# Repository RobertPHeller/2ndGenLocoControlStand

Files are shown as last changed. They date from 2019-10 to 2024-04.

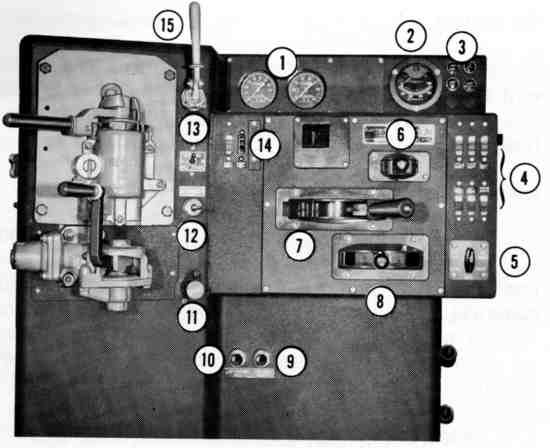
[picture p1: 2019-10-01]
docs/sd40-2-4.jpg

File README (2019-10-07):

This is a model diesel locomotive control stand (more or less typical of a 2nd 
generation diesel locomotive).

Files / Directories:

2ndGenLocoControlStand.dxf, 2ndGenLocoControlStand.gcad, and 
2ndGenLocoControlStand.tcl relate to the 3D model of the front panel (based on 
a Hammond Manucafturing RL6685 enclosure).

The ESP32ControlStand directory contains the ESP32 (TTGO-T1) based design, the 
electronics are in KiCad form (Version: 2013.06.11).  The 
ESP32ControlStand/ESP32ControlStand_Node directory contains the OpenMRN code 
(C++, Arduino style using the OpenMRNLite library).

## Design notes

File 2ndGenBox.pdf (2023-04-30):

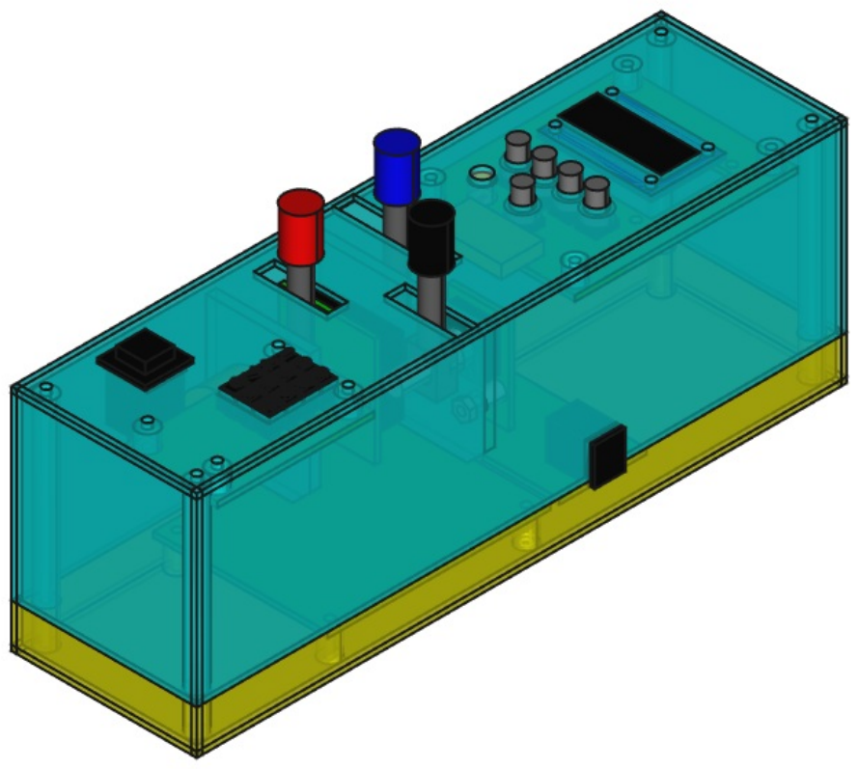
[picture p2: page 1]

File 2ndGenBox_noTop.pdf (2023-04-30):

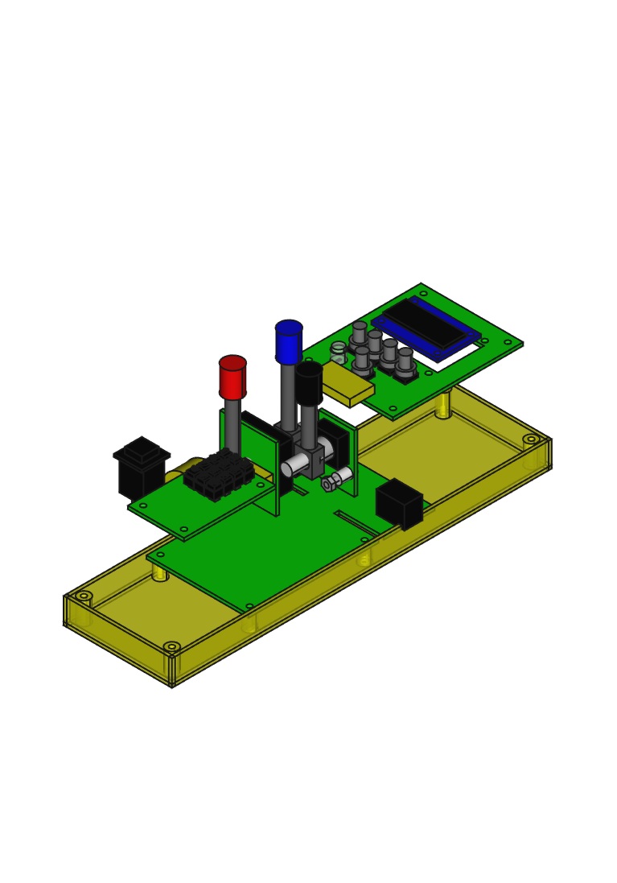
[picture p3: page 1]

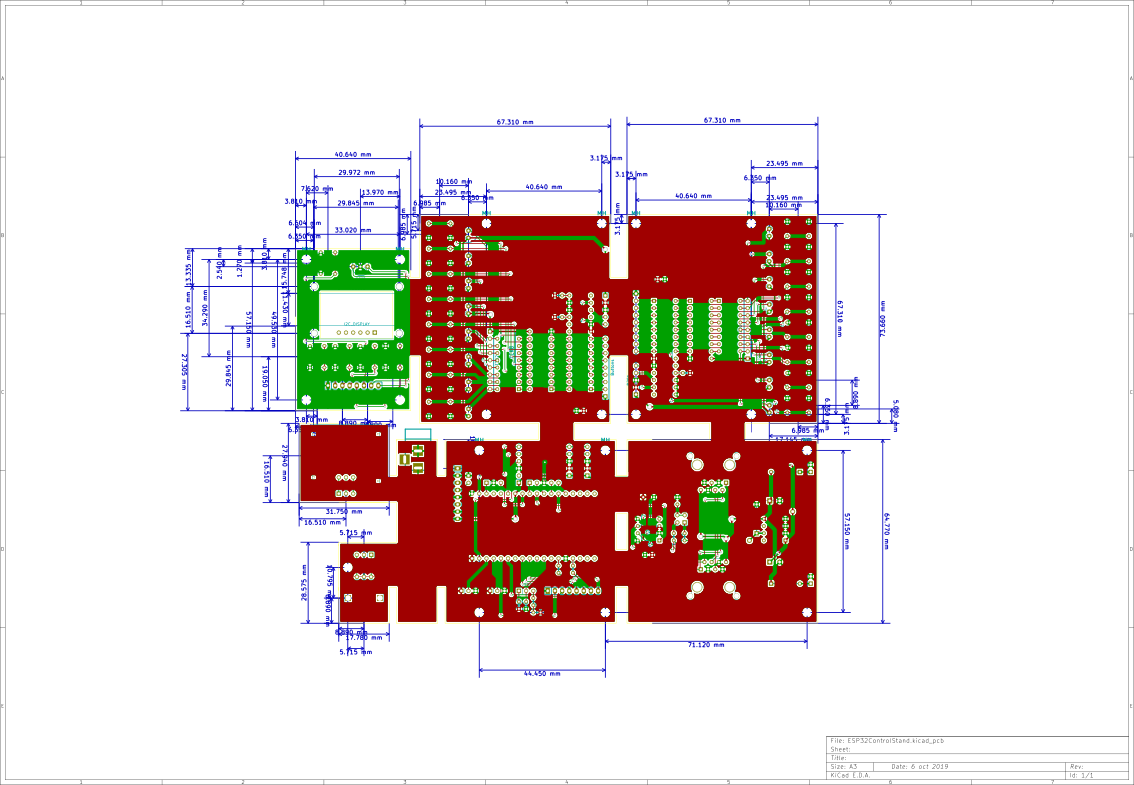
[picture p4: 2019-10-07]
ESP32ControlStand/ESP32ControlStand.png

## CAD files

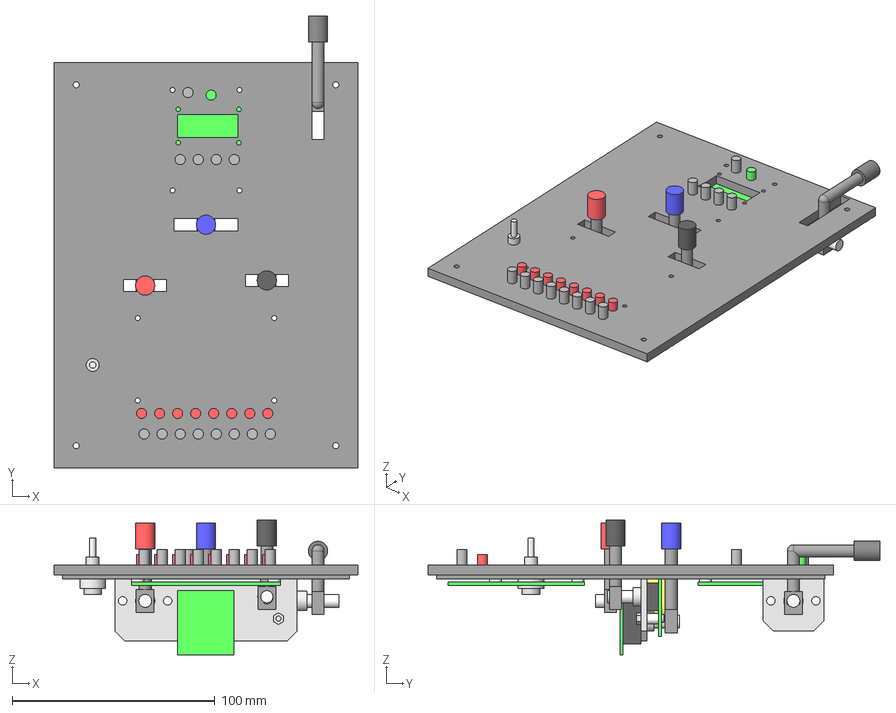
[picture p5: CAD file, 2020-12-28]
2ndGenLocoControlStand.fcstd
149.9 x 222.9 x 66.5 mm
ControlStandLid_lid
ControlStandLid_throttleReverserBrakeBracket
ControlStandLid_throttle_body
ControlStandLid_throttle_bushing
ControlStandLid_throttle_shaft
ControlStandLid_throttle_noturn
ControlStandLid_throttle_circuitBoard
ControlStandLid_throttleLever_shaft
ControlStandLid_throttleLever_handle
ControlStandLid_reverser_body
ControlStandLid_reverser_bushing
ControlStandLid_reverser_shaft
ControlStandLid_reverser_circuitBoard
ControlStandLid_reverser_noturnStandoff
ControlStandLid_reverser_noturnScrew
ControlStandLid_reverser_ntNut
ControlStandLid_reverserLever_shaft
ControlStandLid_reverserLever_handle
ControlStandLid_brakePot_body
ControlStandLid_brakePot_bushing
ControlStandLid_brakePot_shaft
ControlStandLid_brakePot_tab1
ControlStandLid_brakePot_tab2
ControlStandLid_brakeLever_shaft
ControlStandLid_brakeLever_handle
ControlStandLid_buttonDisplayBoard_board
ControlStandLid_buttonDisplayBoardSandoff1
ControlStandLid_buttonDisplayBoardSandoff2
ControlStandLid_buttonDisplayBoardSandoff3
ControlStandLid_buttonDisplayBoardSandoff4
ControlStandLid_hornBracket
ControlStandLid_hornPot_body
ControlStandLid_hornPot_bushing
ControlStandLid_hornPot_shaft
ControlStandLid_hornPot_tab1
ControlStandLid_hornPot_tab2
ControlStandLid_hornHandle_shaft
ControlStandLid_hornHandle_handle
ControlStandLid_buttonLEDBoard_board
ControlStandLid_buttonLEDBoardStandoff1
ControlStandLid_buttonLEDBoardStandoff2
ControlStandLid_buttonLEDBoardStandoff3
ControlStandLid_buttonLEDBoardStandoff4
ControlStandLid_lightSwitch_body
ControlStandLid_lightSwitch_terminals
ControlStandLid_lightSwitch_bushing
ControlStandLid_lightSwitch_shaft
ControlStandLid_statusLED_led
ControlStandLid_buttonLEDBoardLEDS1_led
ControlStandLid_buttonLEDBoardLEDS2_led
ControlStandLid_buttonLEDBoardLEDS3_led
ControlStandLid_buttonLEDBoardLEDS4_led
ControlStandLid_buttonLEDBoardLEDS5_led
ControlStandLid_buttonLEDBoardLEDS6_led
ControlStandLid_buttonLEDBoardLEDS7_led
ControlStandLid_buttonLEDBoardLEDS8_led
ControlStandLid_buttonDisplayBoardPlungers1_body
ControlStandLid_buttonDisplayBoardPlungers2_body
ControlStandLid_buttonDisplayBoardPlungers3_body
ControlStandLid_buttonDisplayBoardPlungers4_body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

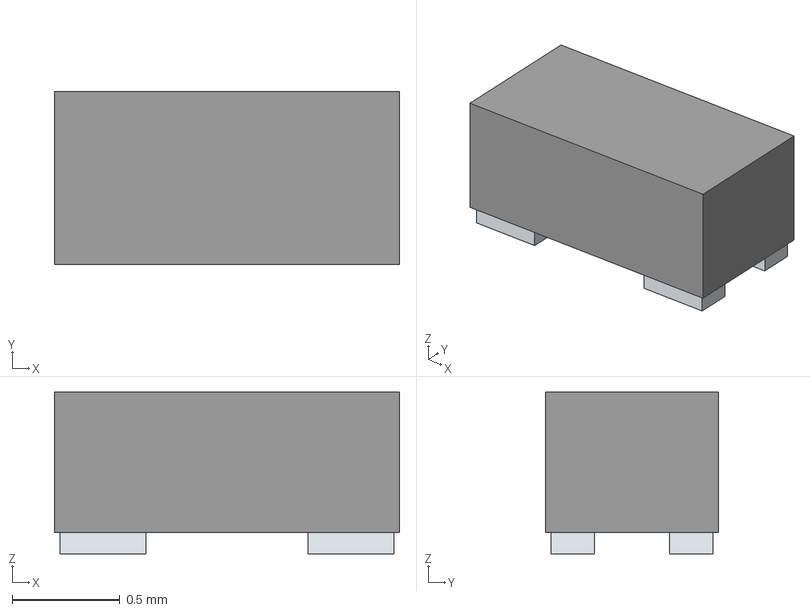
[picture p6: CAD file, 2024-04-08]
ESP32-S3-WROOM-ControlStand/3dmodels/APHB1608CGKSURKC.stp
1.60 x 0.8 x 0.75 mm
Pins

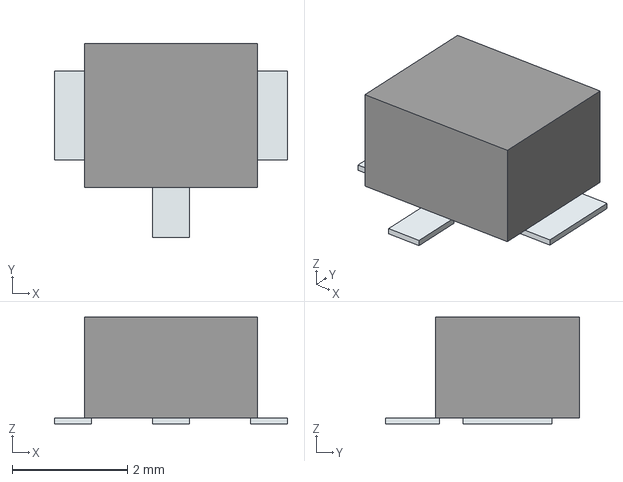
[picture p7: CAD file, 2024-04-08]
ESP32-S3-WROOM-ControlStand/3dmodels/B3U-1100P-B.stp
4.04 x 3.37 x 1.85 mm
Pins

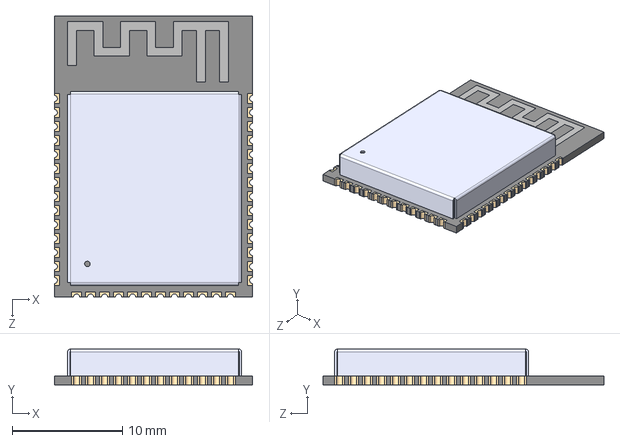
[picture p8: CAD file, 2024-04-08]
ESP32-S3-WROOM-ControlStand/3dmodels/ESP32-S3-WROOM-1-N4.stp
18.0 x 3.25 x 25.5 mm

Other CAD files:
2ndGenLocoControlStand.dxf

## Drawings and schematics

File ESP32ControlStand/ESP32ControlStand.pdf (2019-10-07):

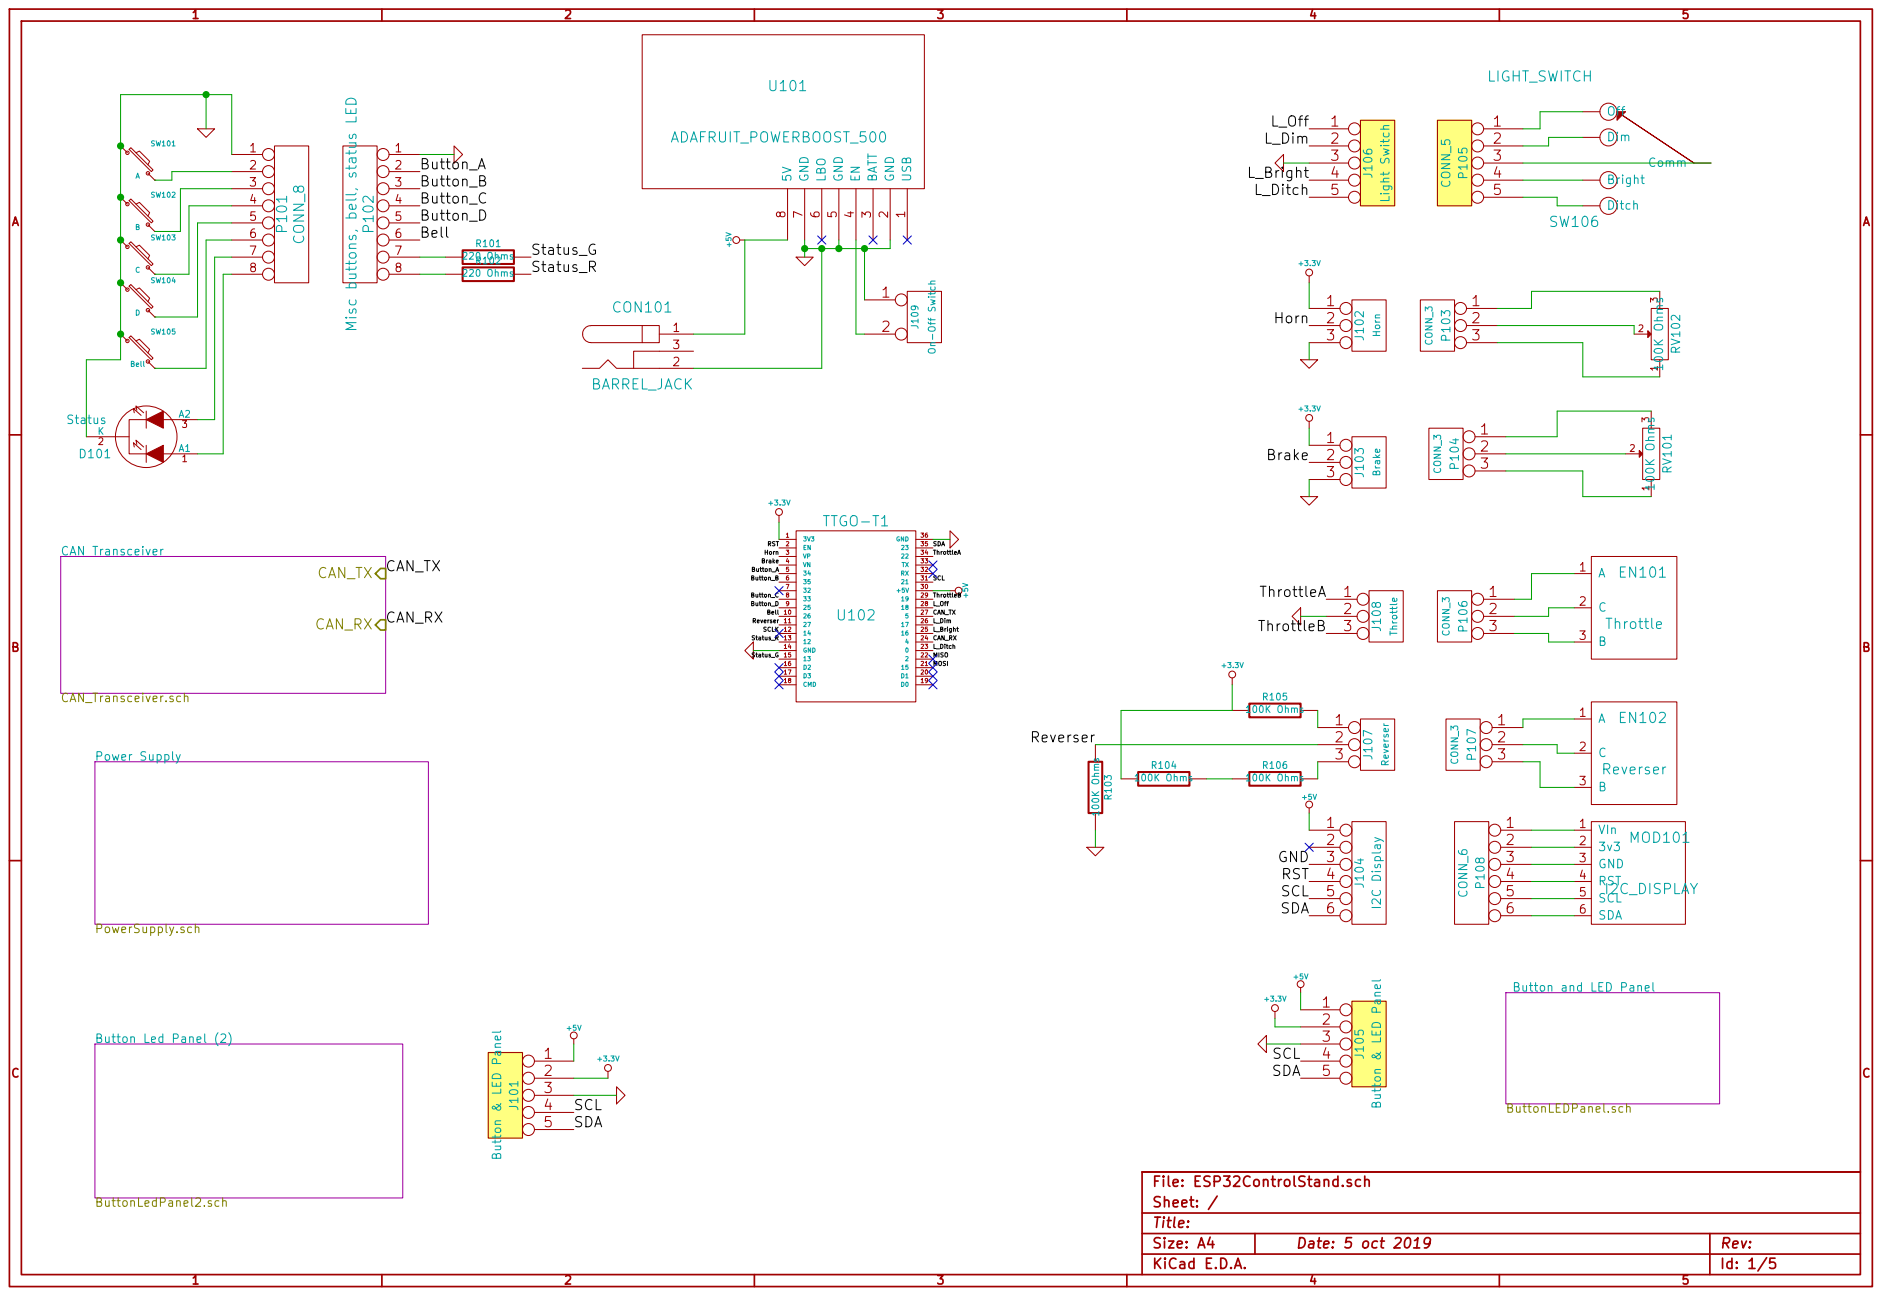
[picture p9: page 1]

220 Ohms Button Led Panel (2) ButtonLedPanel2.sch

+3.3V USB 1 GND 2 BATT 3 EN 4 GND 5 LBO 6 GND 7 5V 8 U101 ADAFRUIT_POWERBOOST_500 +5V
Status_G 123 CON101

SCL MISO MOSI SCLK CAN_TX

Id: 1/5 Title: File: ESP32ControlStand.sch

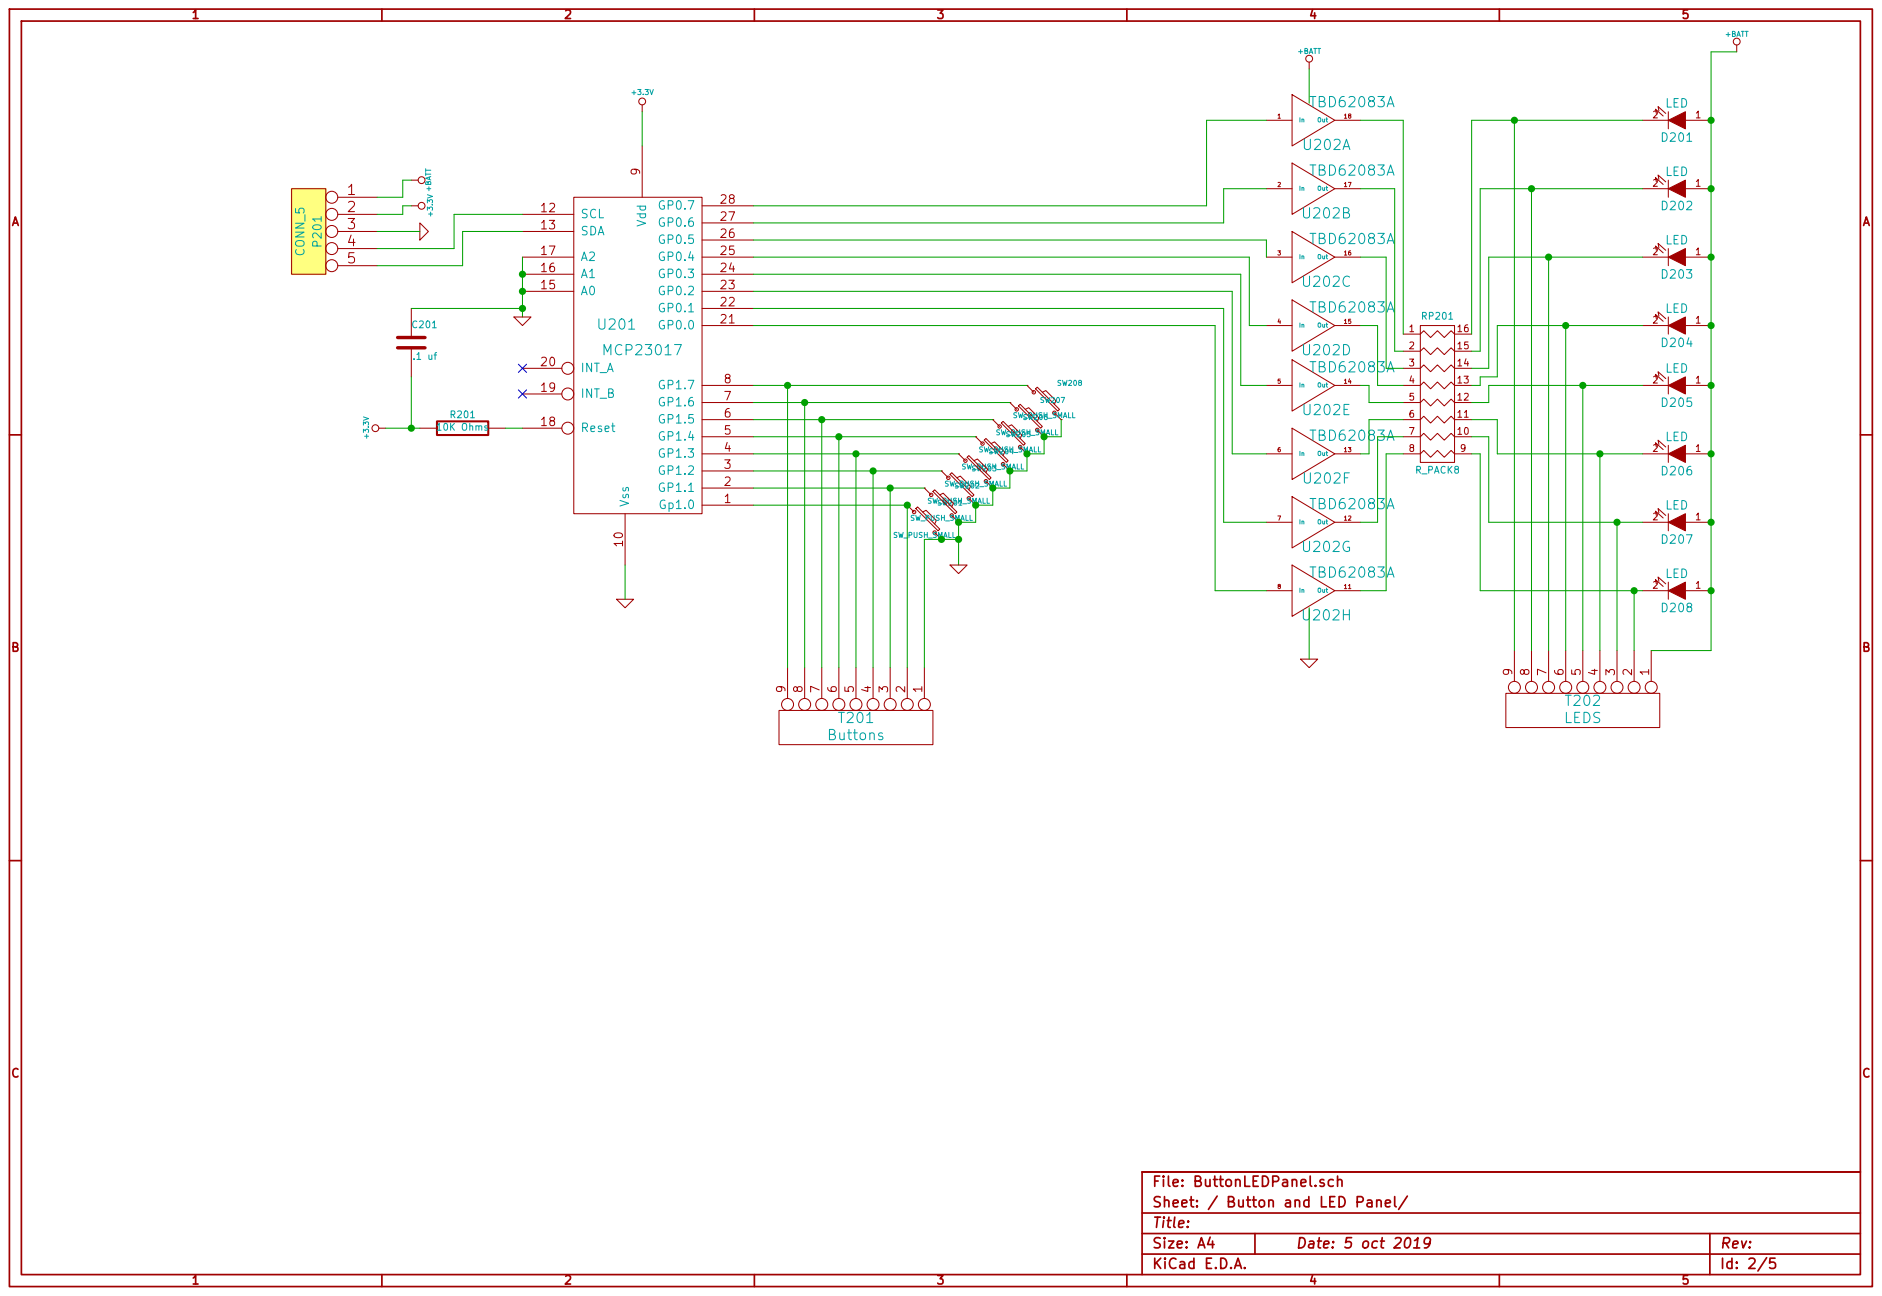
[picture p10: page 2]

7 | 10

Id: 2/5 Title: File: ButtonLEDPanel.sch Sheet: / Button and LED Panel/

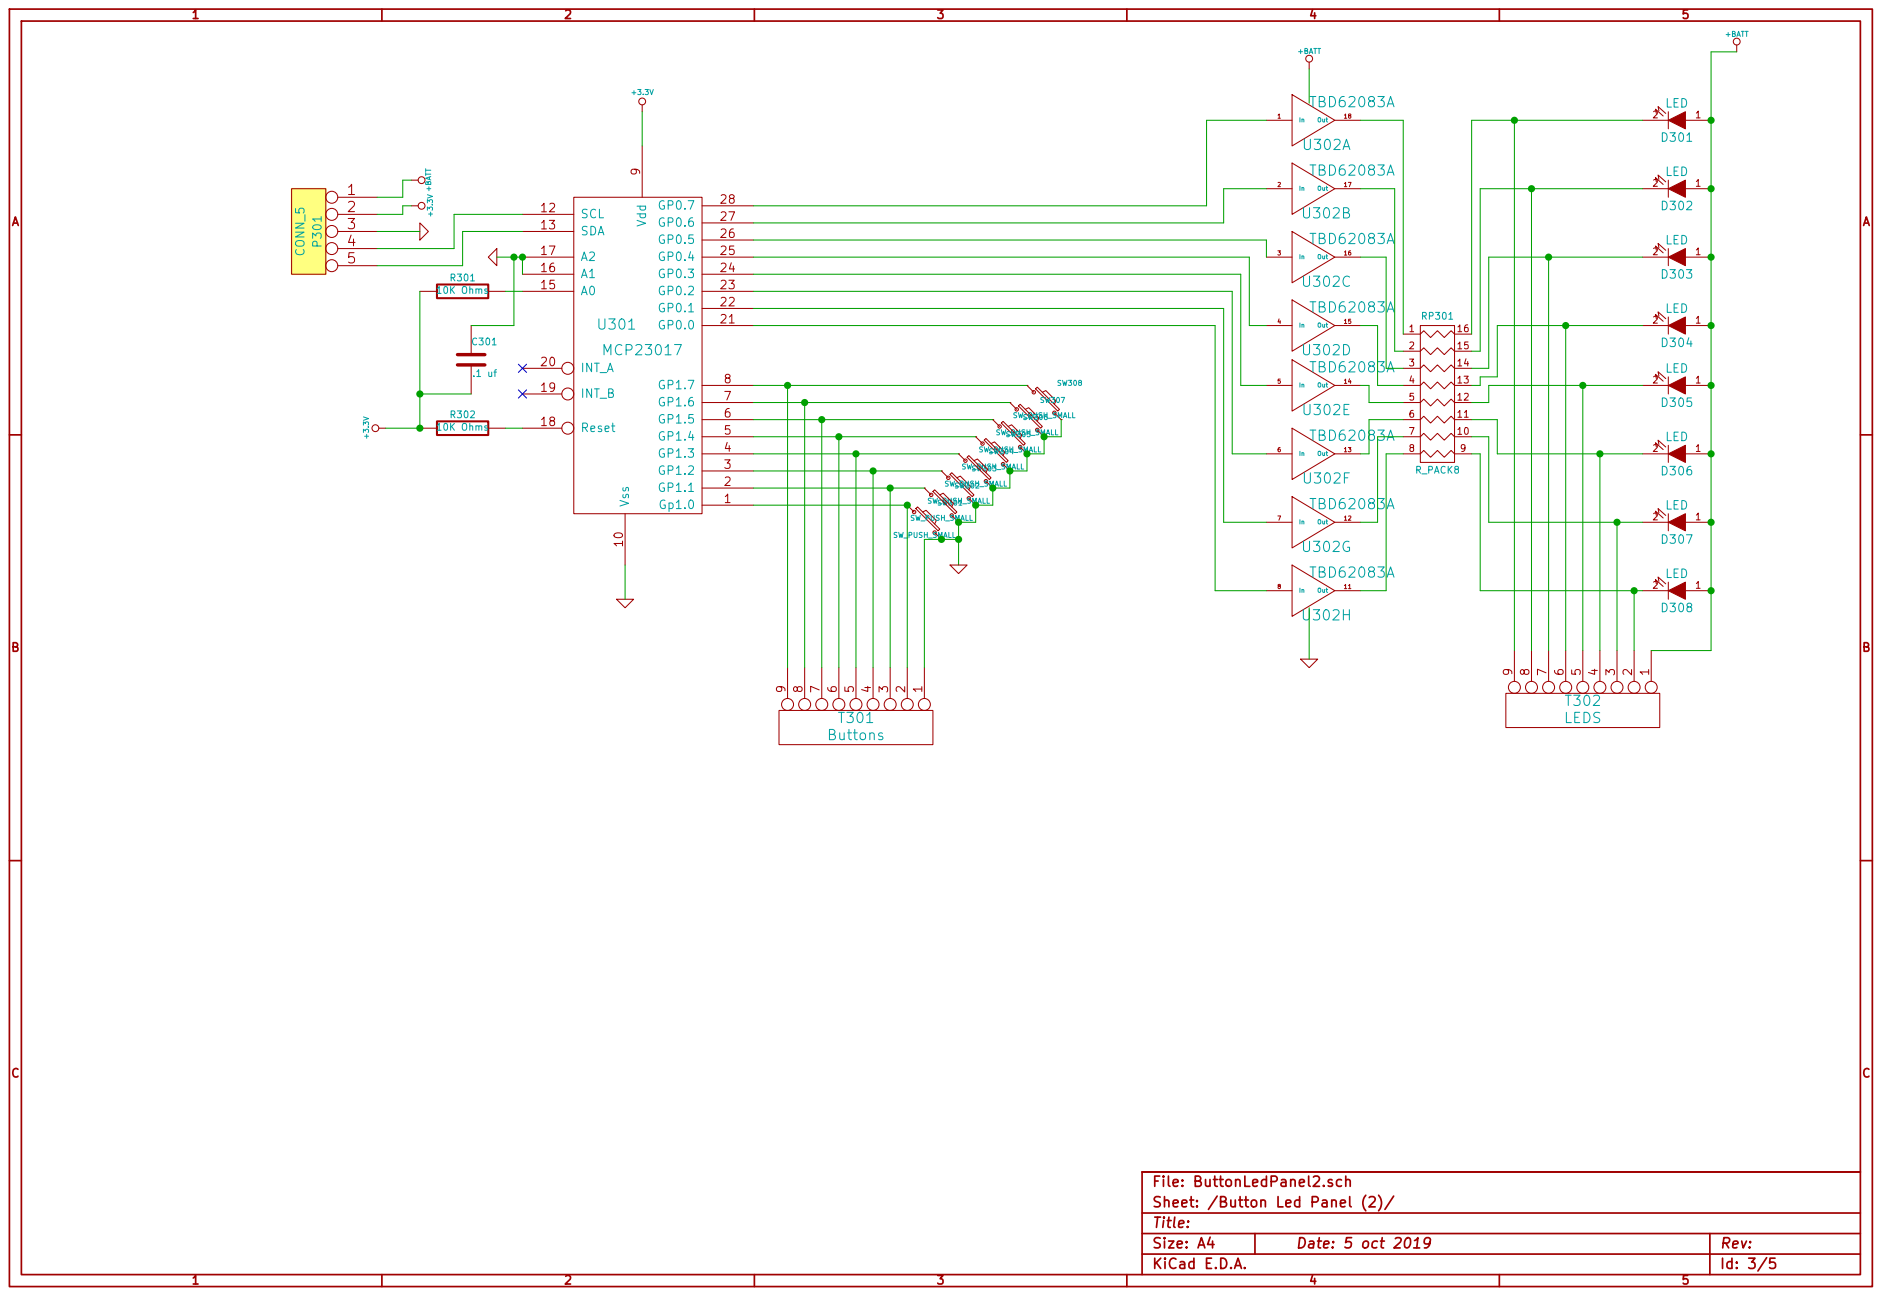
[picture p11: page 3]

7 | 10

Id: 3/5 Title: File: ButtonLedPanel2.sch Sheet: /Button Led Panel (2)/

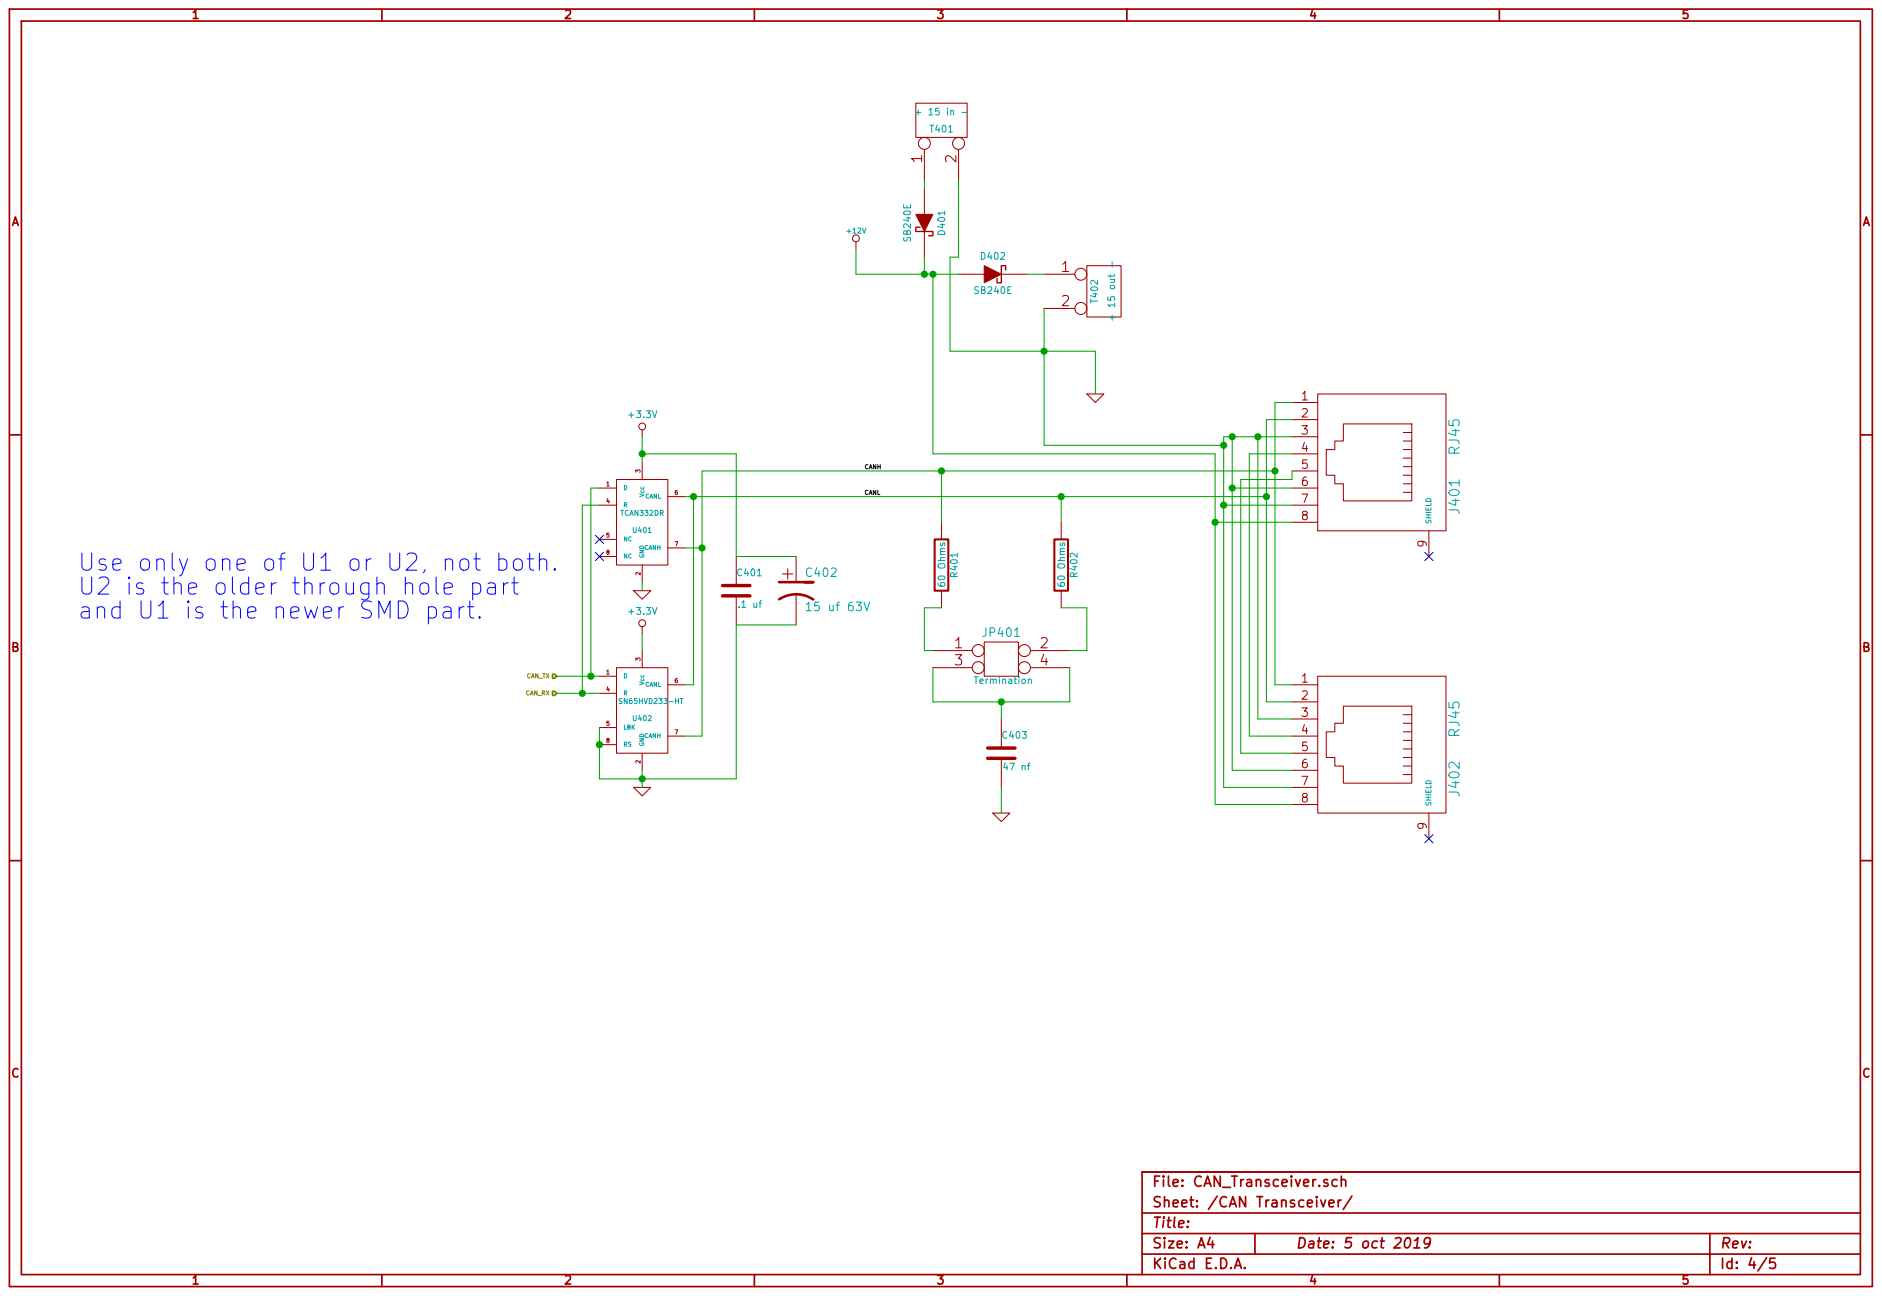
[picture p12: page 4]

T401 + 15 in - D401 SB240E +12V Use only one of U1 or U2, not both.

U2 is the older through hole part
and U1 is the newer SMD part.

Id: 4/5 Title: File: CAN_Transceiver.sch
Sheet: /CAN Transceiver/

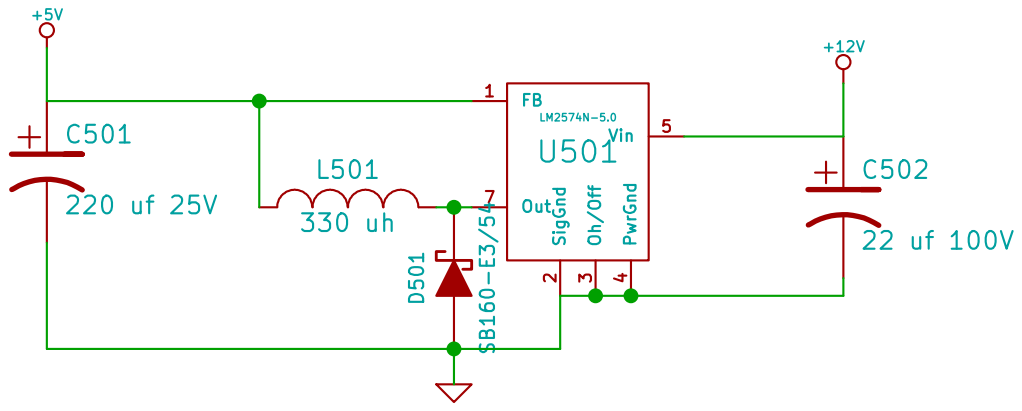
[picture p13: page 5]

Id: 5/5 Title: File: PowerSupply.sch
Sheet: /Power Supply/

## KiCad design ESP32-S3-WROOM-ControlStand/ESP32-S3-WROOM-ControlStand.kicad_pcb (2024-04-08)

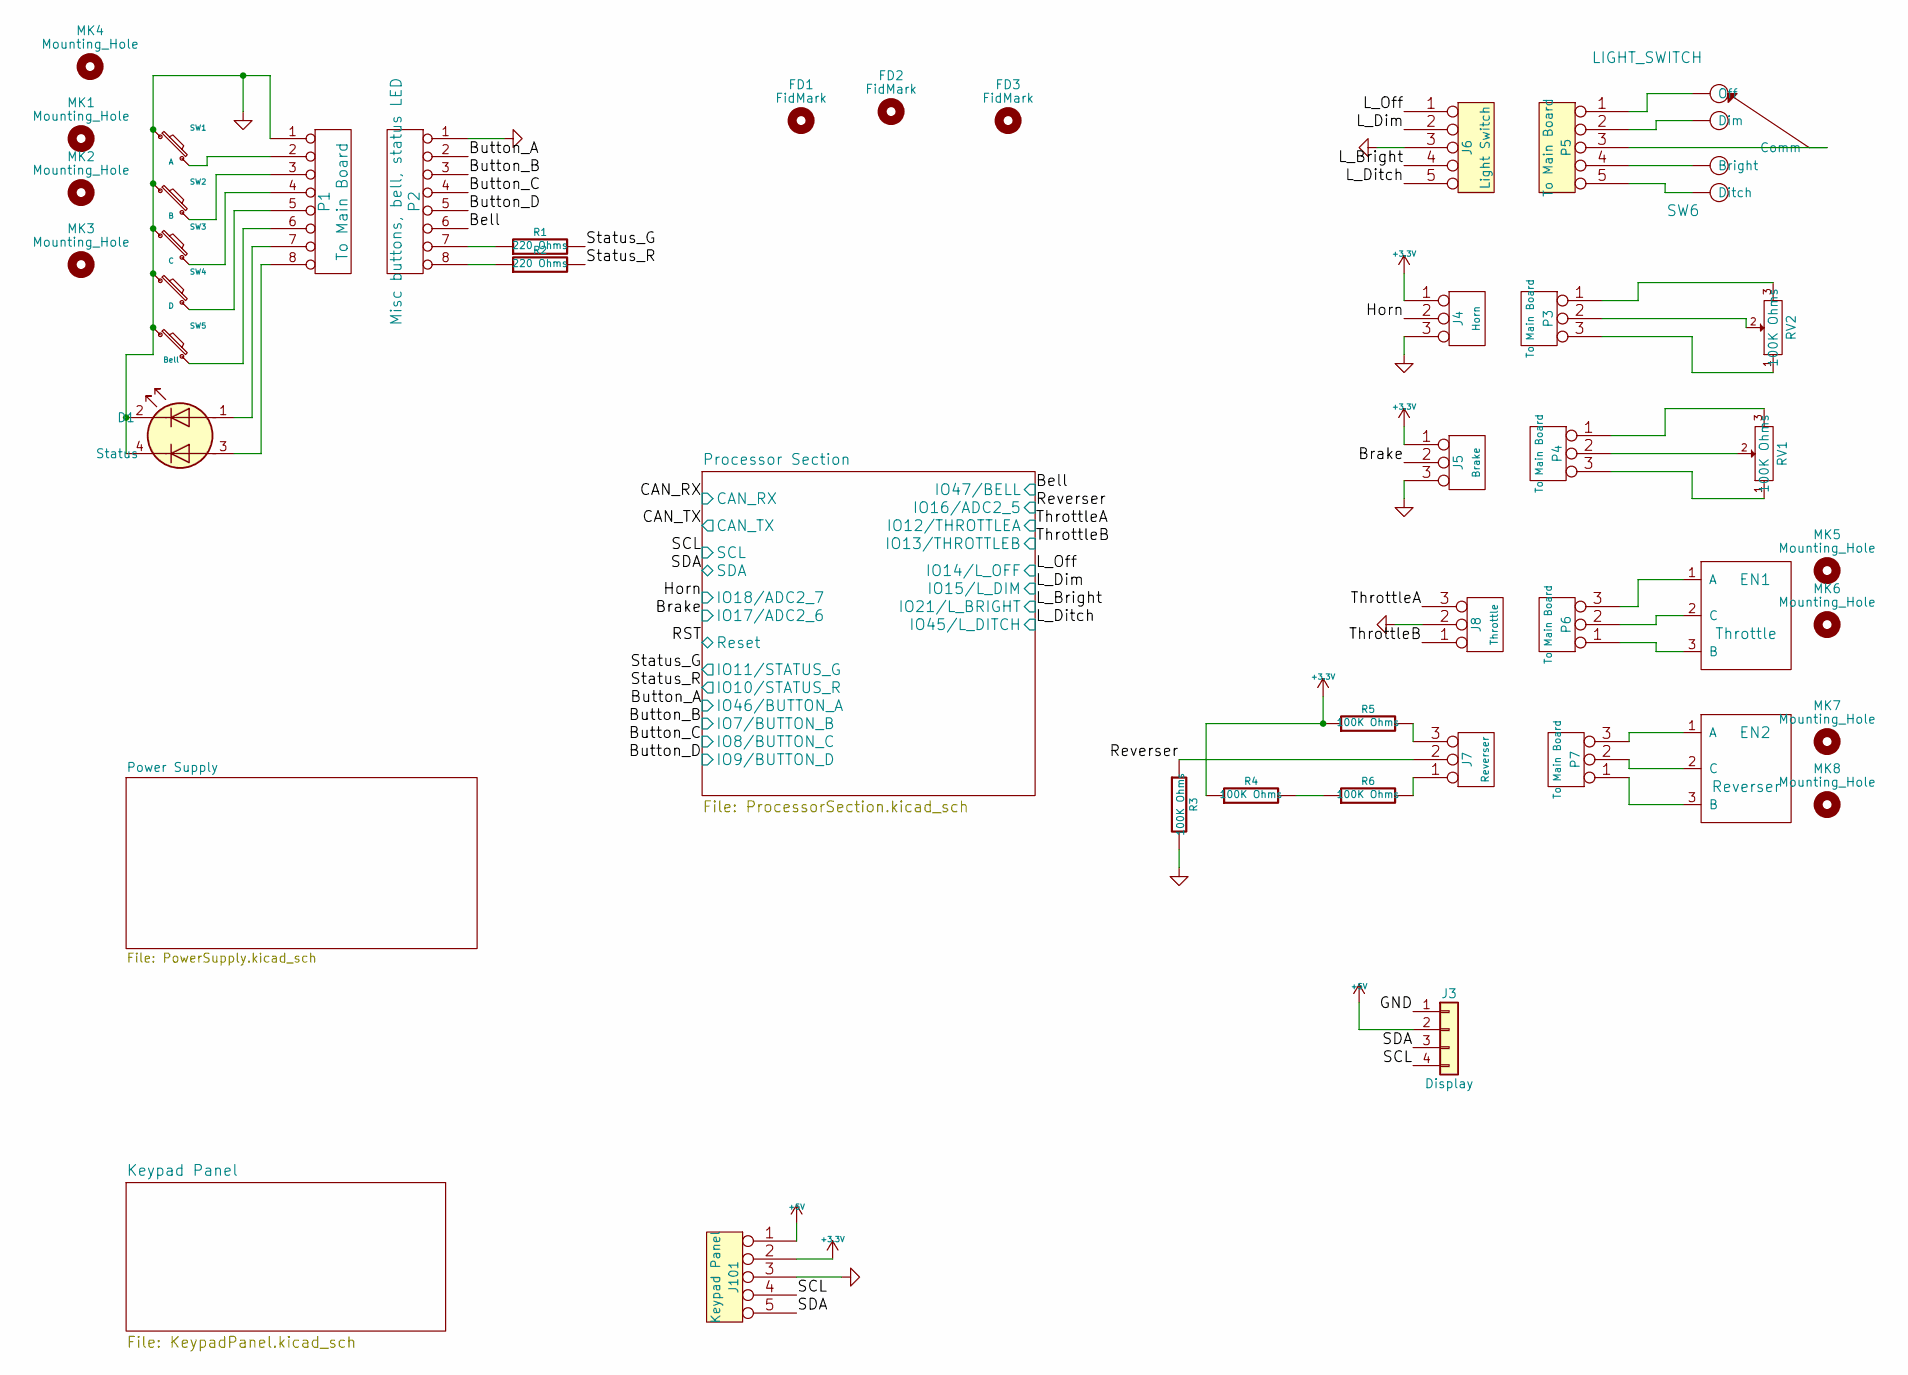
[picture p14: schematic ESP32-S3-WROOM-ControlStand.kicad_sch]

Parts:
D1: Status; APHB1608CGKSURKC; Mouser Part Number 604-APHB1608CGKSURKC
EN1: Throttle; Series25L-Encoder; Mouser Part Number 706-25LB10-Q
EN2: Reverser; ALPSEC12C; Mouser Part Number 652-PEC11R4325FN0012
FD1, FD2, FD3: FidMark; Fiducial_1mm_Dia_2.54mm_Outer_CopperTop
J3: Display; JST_PH_B4B-PH-K_1x04_P2.00mm_Vertical; Manufacturer_Part_Number B4B-PH-SM4-TB
J4: Horn; Pin_Header_Straight_1x03_Pitch2.54mm; Mouser Part Number 649-1012937890301BLF
J5: Brake; Pin_Header_Straight_1x03_Pitch2.54mm; Mouser Part Number 649-1012937890301BLF
J6: Light Switch; Pin_Header_Straight_1x05_Pitch2.54mm; Mouser Part Number 523-G800W303018EU
J7: Reverser; Pin_Header_Straight_1x03_Pitch2.54mm; Mouser Part Number 649-1012937890301BLF
J8: Throttle; Pin_Header_Straight_1x03_Pitch2.54mm; Mouser Part Number 649-1012937890301BLF
J101: Keypad Panel; Pin_Header_Straight_1x05_Pitch2.54mm; Mouser Part Number 523-G800W303018EU
MK1, MK2, MK3, MK4, MK5, MK6, MK7, MK8: Mounting_Hole; MountingHole_2.5mm
P1: To Main Board; Pin_Header_Angled_1x08_Pitch2.54mm; Mouser Part Number 649-1012937990801BLF
P2: Misc buttons, bell, status LED; Pin_Header_Straight_1x08_Pitch2.54mm; Mouser Part Number 649-1012937890801BLF
P3, P4, P5: To Main Board
P6, P7: To Main Board; Pin_Header_Angled_1x03_Pitch2.54mm; Mouser Part Number 855-M20-9750346
R1, R2: 220 Ohms; R_0603_1608Metric; Mouser Part Number 603-AC0603FR-07220RL
R3, R4, R5, R6: 100K Ohms; R_0402_1005Metric; Mouser Part Number 279-CRGCQ0402J100K
RV1, RV2: 100K Ohms; Mouser Part Number 774-450T328F104A1A1
SW1: A; SW_SPST_EVQQ2; Mouser Part Number 667-EVQ-Q2U02W
SW2: B; SW_SPST_EVQQ2; Mouser part Number 667-EVQ-Q2U02W
SW3: C; SW_SPST_EVQQ2; Mouser Part Number 667-EVQ-Q2U02W
SW4: D; SW_SPST_EVQQ2; Mouser Part Number 667-EVQ-Q2U02W
SW5: Bell; SW_SPST_EVQQ2; Mouser Part Number 667-EVQ-Q2U02W
SW6: LIGHT_SWITCH

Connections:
+5V: J3.2, J101.1; also elsewhere on the board
/Bell: P2.6; also elsewhere on the board
/Brake: J5.2 (PM); also elsewhere on the board
/Button_A: P2.2; also elsewhere on the board
/Button_B: P2.3; also elsewhere on the board
/Button_C: P2.4; also elsewhere on the board
/Button_D: P2.5; also elsewhere on the board
/Horn: J4.2 (PM); also elsewhere on the board
/L_Bright: J6.4; also elsewhere on the board
/L_Dim: J6.2; also elsewhere on the board
/L_Ditch: J6.5; also elsewhere on the board
/L_Off: J6.1; also elsewhere on the board
/Reverser: J7.2 (PM), R3.1; also elsewhere on the board
/SCL: J3.4, J101.4; also elsewhere on the board
/SDA: J3.3, J101.5; also elsewhere on the board
/Status_G: R1.2; also elsewhere on the board
/Status_R: R2.2; also elsewhere on the board
/ThrottleA: J8.3; also elsewhere on the board
/ThrottleB: J8.1; also elsewhere on the board
GND: D1.2 (K1), D1.4 (K2), J3.1, J4.3, J5.3, J6.3, J8.2 (PM), J101.3, P1.1, P2.1, R3.2, SW1.1, SW2.1, SW3.1, SW4.1, SW5.1; also elsewhere on the board
unnamed: D1.1 (A1), P1.7
unnamed: D1.3 (A2), P1.8
unnamed: EN1.1 (A), P6.3
unnamed: EN1.2 (C), P6.2 (PM)
unnamed: EN1.3 (B), P6.1
unnamed: EN2.1 (A), P7.3
unnamed: EN2.2 (C), P7.2 (PM)
unnamed: EN2.3 (B), P7.1
unnamed: J7.1, R6.2
unnamed: J7.3, R5.2
unnamed: P1.2, SW1.2
unnamed: P1.3, SW2.2
unnamed: P1.4, SW3.2
unnamed: P1.5, SW4.2
unnamed: P1.6, SW5.2
unnamed: P2.7, R1.1
unnamed: P2.8, R2.1
unnamed: P3.1, RV2.3
unnamed: P3.2 (PM), RV2.2
unnamed: P3.3, RV2.1
unnamed: P4.1, RV1.3
unnamed: P4.2 (PM), RV1.2
unnamed: P4.3, RV1.1
unnamed: P5.1, SW6.~
unnamed: P5.2, SW6.~
unnamed: P5.3, SW6.~
unnamed: P5.4, SW6.~
unnamed: P5.5, SW6.~
unnamed: R4.2, R6.1

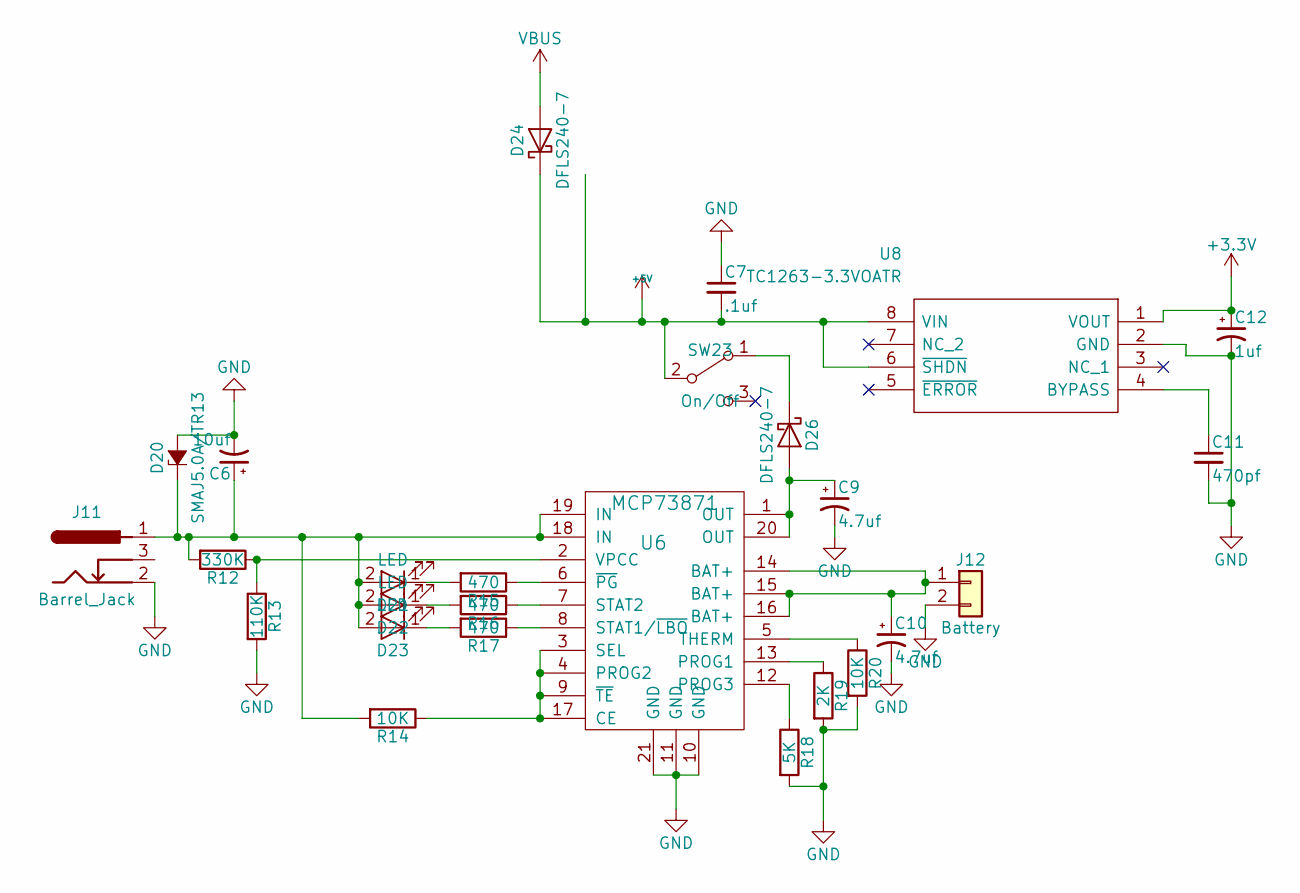
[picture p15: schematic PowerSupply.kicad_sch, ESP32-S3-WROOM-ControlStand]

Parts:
C6: 10uf; CP_Elec_4x5.7; Mouser Part Number 710-865080340001
C7: .1uf; C_0402; Mouser Part Number 81-GRM155R62A104KE4J
C9, C10: 4.7uf; CP_Elec_4x5.7; Mouser Part Number 710-865080640004
C11: 470pf; C_0402; Mouser Part Number 80-C0402C471K4RAUTO
C12: 1uf; C_0603_POL; Mouser Part Number 74-TMCJ1C105MTRF
D20: SMAJ5.0A/TR13; D_SMA; Mouser Part Number 603-SMAJ5.0A/TR13
D21: LED; LED_0402; Mouser Part Number 710-150040GS73220
D22: LED; LED_0402; Mouser Part Number 710-150040YS73220
D23: LED; LED_0402; Mouser Part Number 710-150040RS73220
D24, D26: DFLS240-7; D_PowerDI-123; Mouser Part Number 621-DFLS240-7
J11: Barrel_Jack; BARREL_JACK; Mouser Part Number 992-CON-SOCJ-2155
J12: Battery; JST_PH_B2B-PH-K_1x02_P2.00mm_Vertical; Manufacturer_Part_Number B2B-PH-SM4-TB
R12: 330K; R_0402; Mouser Part Number 603-AF0402FR-07330KL
R13: 110K; R_0402; Mouser Part Number 603-RC0402JR-13110KL
R14, R20: 10K; R_0402; Mouser Part Number 603-RC0402JR-0710KL
R15, R16, R17: 470; R_0402; Mouser Part Number 603-RC0402JR-07470RL
R18: 5K; R_0402; Mouser Part Number 603-RC0402FR-075KL
R19: 2K; R_0402; Mouser Part Number 603-RC0402FR-132KL
SW23: On/Off; SW_SPDT_CK-JS102011SAQN; Mouser Part Number 611-JS102011SAQN
U6: MCP73871; QFN-20-1EP_4x4mm_P0.5mm_EP2.5x2.5mm_ThermalVias; Mouser Part Number 579-MCP73871-3CAI/ML
U8: TC1263-3.3VOATR; SOIC-8W_5.3x5.3mm_P1.27mm; Manufacturer_Part_Number TC1263-3.3VOATR

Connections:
+5V: C7.2, D24.1 (K), SW23.2 (B), U8.6 (~SHDN), U8.8 (VIN); also elsewhere on the board
GND: C6.2, C7.1, C9.2, C10.2, C11.2, C12.2, D20.2 (A), J11.2, J12.2, R13.2, R18.2, R19.2, R20.2, U6.10 (GND), U6.11 (GND), U6.21 (GND), U8.2 (GND); also elsewhere on the board
unnamed: C6.1, D20.1 (K), D21.2 (A), D22.2 (A), D23.2 (A), J11.1, R12.2, R14.2, U6.18 (IN), U6.19 (IN)
unnamed: C9.1, D26.2 (A), U6.1 (OUT), U6.20 (OUT)
unnamed: C10.1, J12.1, U6.14 (BAT+), U6.15 (BAT+), U6.16 (BAT+)
unnamed: C11.1, U8.4 (BYPASS)
unnamed: D21.1 (K), R15.2
unnamed: D22.1 (K), R16.2
unnamed: D23.1 (K), R17.2
unnamed: D26.1 (K), SW23.1 (A)
unnamed: R12.1, R13.1, U6.2 (VPCC)
unnamed: R14.1, U6.3 (SEL), U6.4 (PROG2), U6.9 (~TE), U6.17 (CE)
unnamed: R15.1, U6.6 (~PG)
unnamed: R16.1, U6.7 (STAT2)
unnamed: R17.1, U6.8 (STAT1/~LBO)
unnamed: R18.1, U6.12 (PROG3)
unnamed: R19.1, U6.13 (PROG1)
unnamed: R20.1, U6.5 (THERM)
VBUS: D24.2 (A); also elsewhere on the board

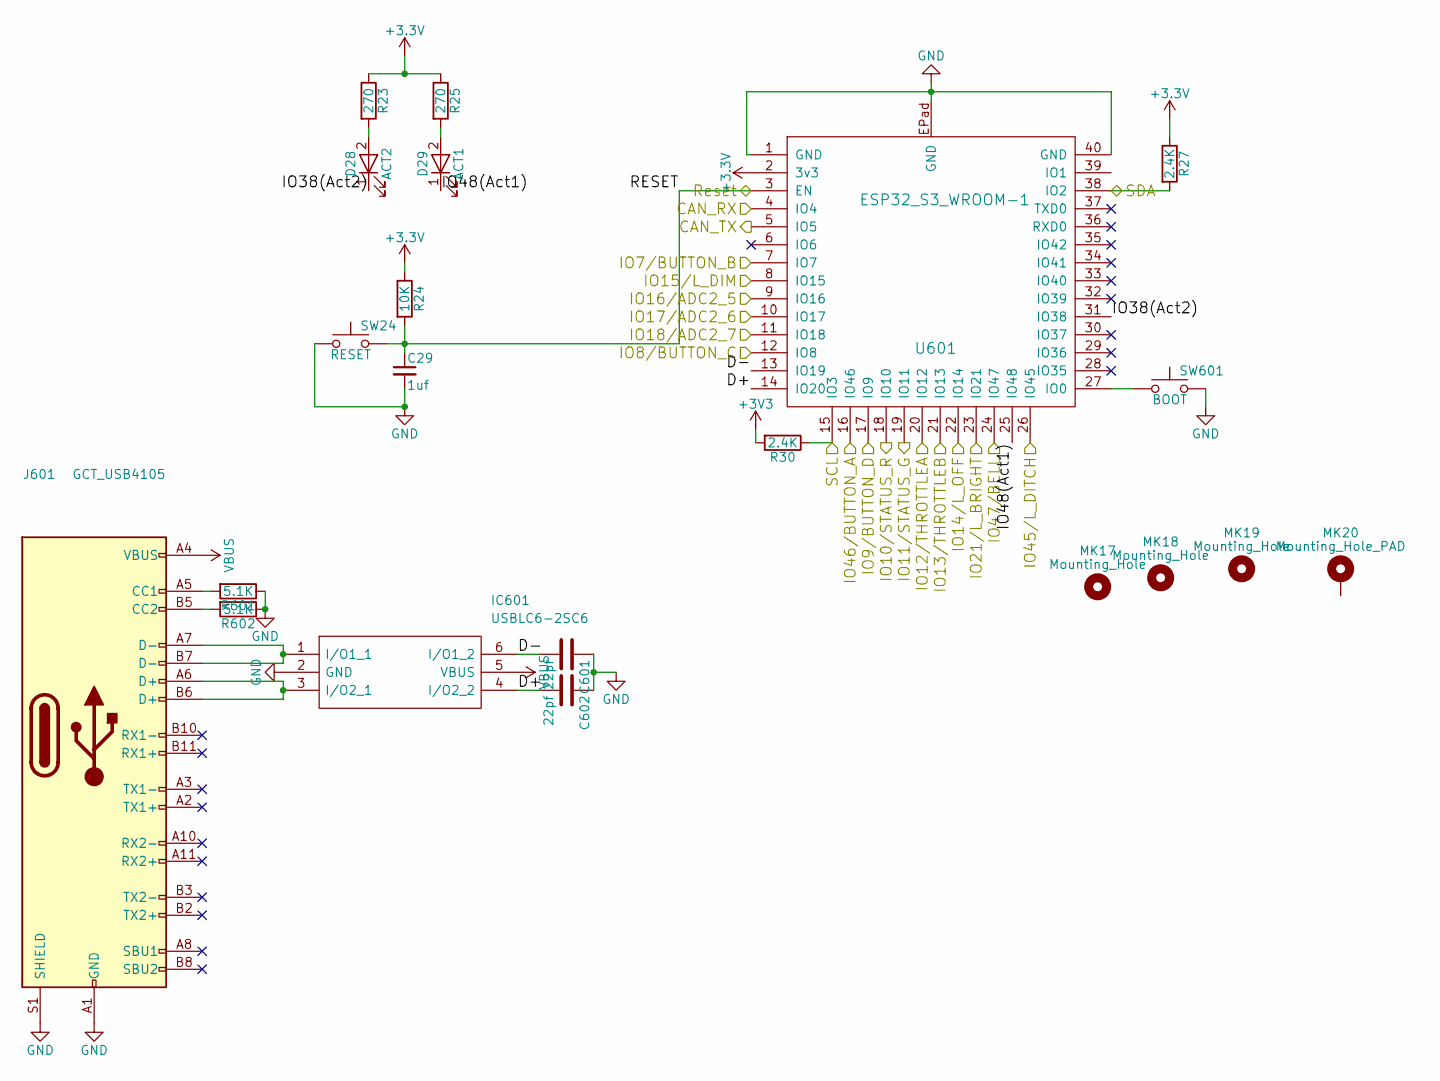
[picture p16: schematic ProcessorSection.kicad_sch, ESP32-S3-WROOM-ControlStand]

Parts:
C29: 1uf; C_0402; Mouser Part Number 80-C0402C101K8RAUTO
C601, C602: 22pf; C_0402; Mouser Part Number 187-CL05C220JB5NNND
D28: ACT2; LED_0402; Mouser Part Number 710-150040SS73220
D29: ACT1; LED_0402; Mouser Part Number 710-150040GS73220
IC601: USBLC6-2SC6; SOT-23-6; Mouser2 Part Number 511-USBLC6-2SC6
J601: GCT_USB4105; USB_C_Receptacle_GCT_USB4105-xx-A_16P_TopMnt_Horizontal
MK17, MK18, MK19: Mounting_Hole; MountingHole_2.5mm
MK20: Mounting_Hole_PAD; MountingHole_2.5mm_Pad
R23, R25: 270; R_0402; Mouser Part Number 754-RR0510P-271D
R24: 10K; R_0402; Mouser Part Number 603-RC0402JR-1310KL
R27, R30: 2.4K; R_0402; Mouser Part Number 71-CRCW06032K40JNEAC
R601, R602: 5.1K; R_0402; Mouser Part Number 71-CRCW0402-5.1K-E3
SW24: RESET; SW_SPST_PTS810; Mouser Part Number 611-PTS810SJM250SMTR
SW601: BOOT; SW_SPST_PTS810; Mouser Part Number 611-PTS810SJM250SMTR
U601: ESP32_S3_WROOM-1; Mouser Part Number 356-ESP32-S3WROOM1N4

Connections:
/Bell: U601.24 (IO47); also elsewhere on the board
/Brake: U601.10 (IO17); also elsewhere on the board
/Button_A: U601.16 (IO46); also elsewhere on the board
/Button_B: U601.7 (IO7); also elsewhere on the board
/Button_C: U601.12 (IO8); also elsewhere on the board
/Button_D: U601.17 (IO9); also elsewhere on the board
/CAN_RX: U601.4 (IO4)
/CAN_TX: U601.5 (IO5)
/Horn: U601.11 (IO18); also elsewhere on the board
/L_Bright: U601.23 (IO21); also elsewhere on the board
/L_Dim: U601.8 (IO15); also elsewhere on the board
/L_Ditch: U601.26 (IO45); also elsewhere on the board
/L_Off: U601.22 (IO14); also elsewhere on the board
/Processor Section/D+: C602.2, IC601.4 (I/O2_2), U601.14 (IO20)
/Processor Section/D-: C601.2, IC601.6 (I/O1_2), U601.13 (IO19)
/Processor Section/IO38(Act2): D28.1 (K), U601.31 (IO38)
/Processor Section/IO48(Act1): D29.1 (K), U601.25 (IO48)
/RST: C29.1, R24.2, SW24.2, U601.3 (EN)
/Reverser: U601.9 (IO16); also elsewhere on the board
/SCL: R30.1, U601.15 (IO3); also elsewhere on the board
/SDA: R27.2, U601.38 (IO2); also elsewhere on the board
/Status_G: U601.19 (IO11); also elsewhere on the board
/Status_R: U601.18 (IO10); also elsewhere on the board
/ThrottleA: U601.20 (IO12); also elsewhere on the board
/ThrottleB: U601.21 (IO13); also elsewhere on the board
GND: C29.2, C601.1, C602.1, IC601.2 (GND), J601.A1 (GND), J601.A12 (GND), J601.B1 (GND), J601.B12 (GND), J601.S1 (SHIELD), R601.1, R602.1, SW24.1, SW601.2, U601.1 (GND), U601.40 (GND), U601.EPad (GND); also elsewhere on the board
unnamed: D28.2 (A), R23.2
unnamed: D29.2 (A), R25.2
unnamed: IC601.1 (I/O1_1), J601.A7 (D-), J601.B7 (D-)
unnamed: IC601.3 (I/O2_1), J601.A6 (D+), J601.B6 (D+)
unnamed: J601.A5 (CC1), R601.2
unnamed: J601.B5 (CC2), R602.2
unnamed: SW601.1, U601.27 (IO0)
VBUS: IC601.5 (VBUS), J601.A4 (VBUS), J601.A9 (VBUS), J601.B4 (VBUS), J601.B9 (VBUS); also elsewhere on the board

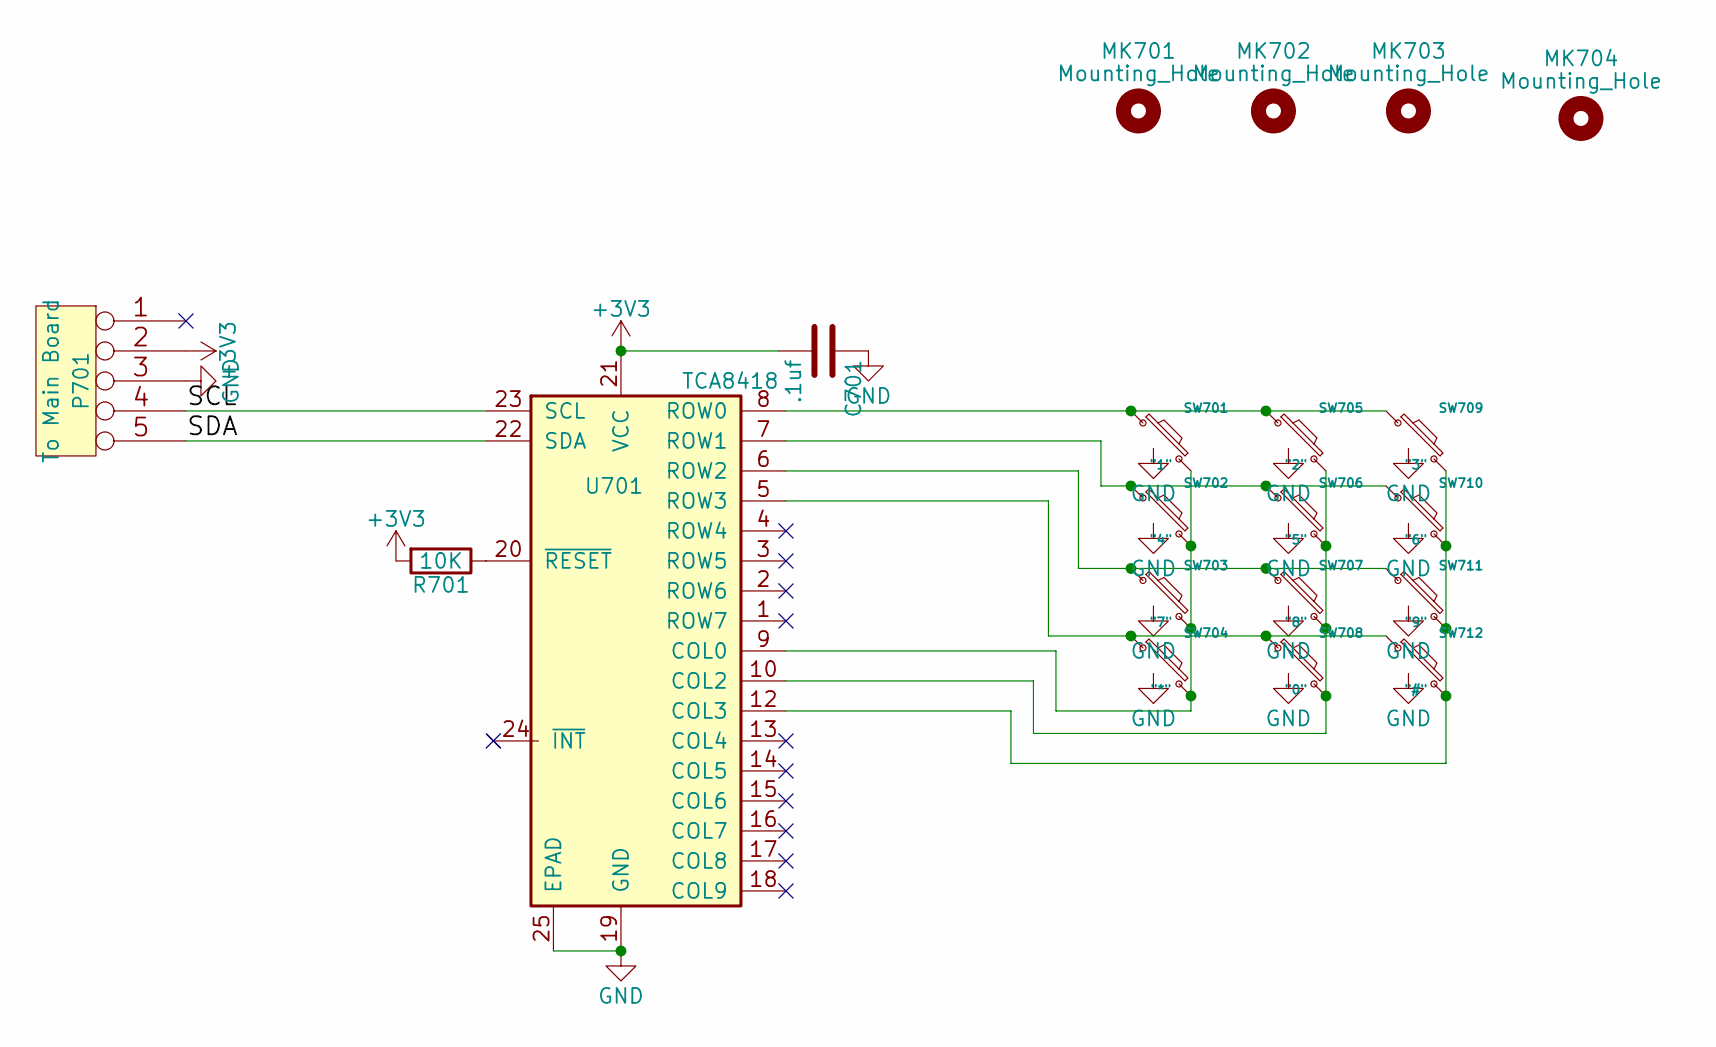
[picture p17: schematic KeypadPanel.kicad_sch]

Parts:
C701: .1uf; C_0603_1608Metric; Mouser Part Number 810-C0603X5R1E104KBB
MK701, MK702, MK703, MK704: Mounting_Hole; MountingHole_2.5mm
P701: To Main Board; Pin_Header_Angled_1x05_Pitch2.54mm; Mouser Part Number 649-1012937990501BLF
R701: 10K; R_0603_1608Metric; Mouser Part Number 71-CRCW0603J-910K-E3
SW701: "1"; SW_SPST_B3U-1100P-B; Mouser Part Number 653-B3U-1100P-B
SW702: "4"; SW_SPST_B3U-1100P-B; Mouser Part Number 653-B3U-1100P-B
SW703: "7"; SW_SPST_B3U-1100P-B; Mouser Part Number 653-B3U-1100P-B
SW704: "*"; SW_SPST_B3U-1100P-B; Mouser Part Number 653-B3U-1100P-B
SW705: "2"; SW_SPST_B3U-1100P-B; Mouser Part Number 653-B3U-1100P-B
SW706: "5"; SW_SPST_B3U-1100P-B; Mouser Part Number 653-B3U-1100P-B
SW707: "8"; SW_SPST_B3U-1100P-B; Mouser Part Number 653-B3U-1100P-B
SW708: "0"; SW_SPST_B3U-1100P-B; Mouser Part Number 653-B3U-1100P-B
SW709: "3"; SW_SPST_B3U-1100P-B; Mouser Part Number 653-B3U-1100P-B
SW710: "6"; SW_SPST_B3U-1100P-B; Mouser Part Number 653-B3U-1100P-B
SW711: "9"; SW_SPST_B3U-1100P-B; Mouser Part Number 653-B3U-1100P-B
SW712: "#"; SW_SPST_B3U-1100P-B; Mouser Part Number 653-B3U-1100P-B
U701: TCA8418; QFN-24-1EP_4x4mm_P0.5mm_EP2.7x2.7mm_ThermalVias

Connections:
/Keypad Panel/SCL: P701.4, U701.23 (SCL)
/Keypad Panel/SDA: P701.5, U701.22 (SDA)
GND: C701.1, P701.3, SW701.3 (GND), SW702.3 (GND), SW703.3 (GND), SW704.3 (GND), SW705.3 (GND), SW706.3 (GND), SW707.3 (GND), SW708.3 (GND), SW709.3 (GND), SW710.3 (GND), SW711.3 (GND), SW712.3 (GND), U701.19 (GND), U701.25 (EPAD); also elsewhere on the board
unnamed: R701.1, U701.20 (~RESET)
unnamed: SW701.1, SW705.1, SW709.1, U701.8 (ROW0)
unnamed: SW701.2, SW702.2, SW703.2, SW704.2, U701.9 (COL0)
unnamed: SW702.1, SW706.1, SW710.1, U701.7 (ROW1)
unnamed: SW703.1, SW707.1, SW711.1, U701.6 (ROW2)
unnamed: SW704.1, SW708.1, SW712.1, U701.5 (ROW3)
unnamed: SW705.2, SW706.2, SW707.2, SW708.2, U701.10 (COL2)
unnamed: SW709.2, SW710.2, SW711.2, SW712.2, U701.12 (COL3)

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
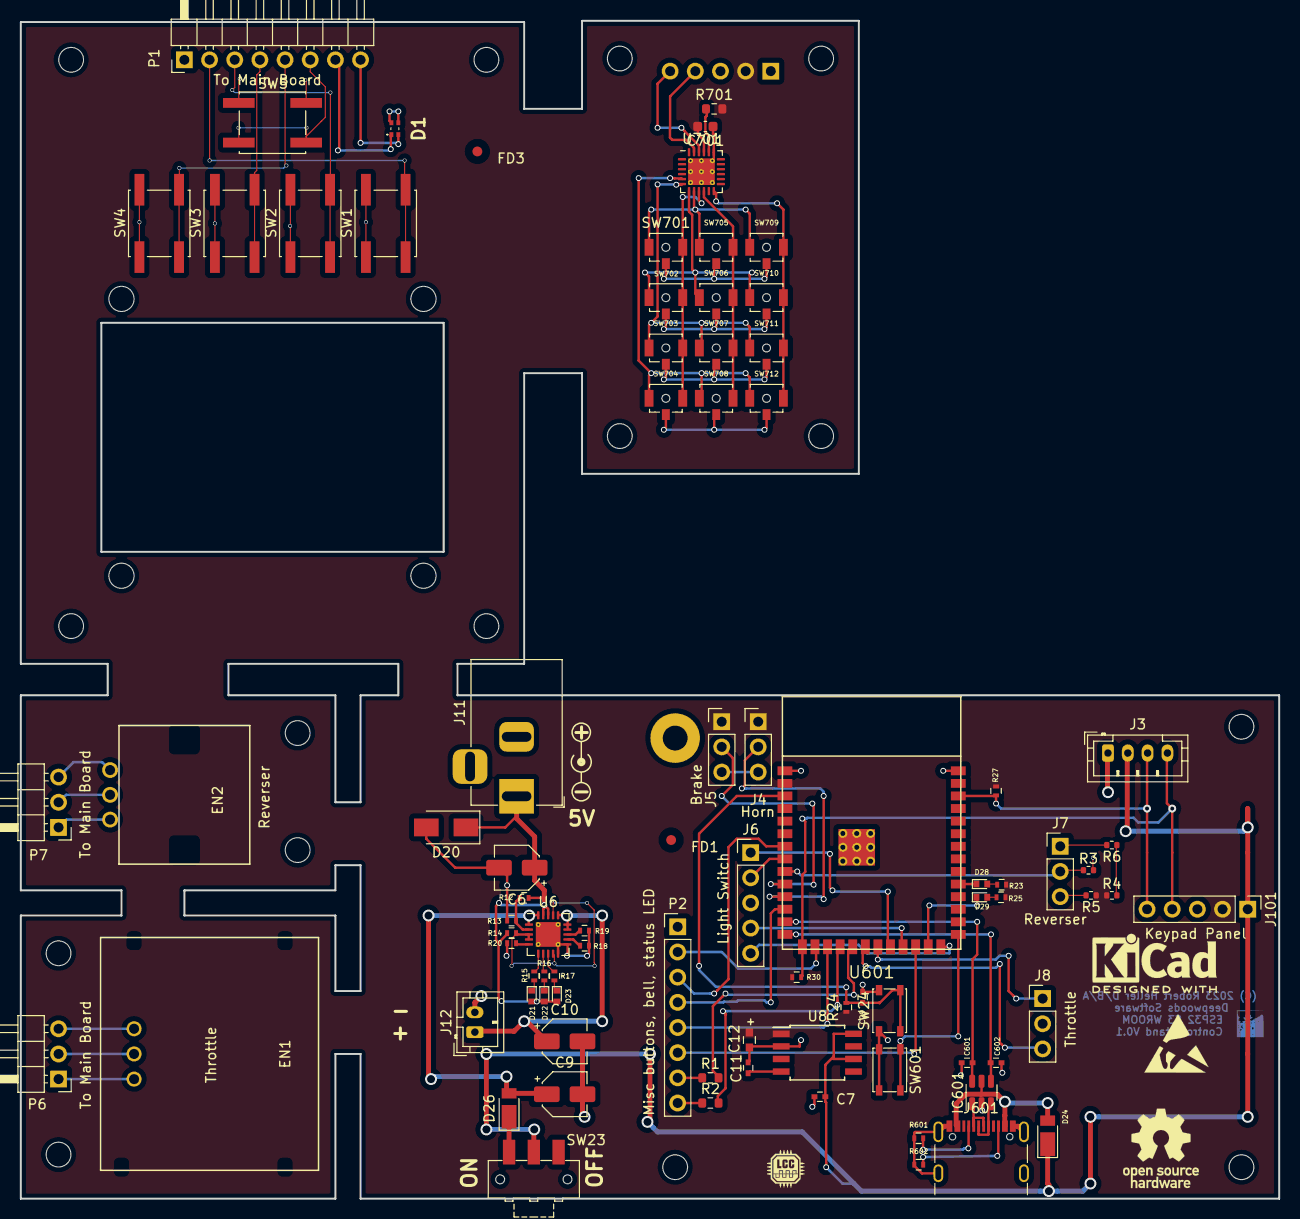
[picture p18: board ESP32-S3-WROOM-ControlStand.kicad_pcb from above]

Board: 2 copper layers, 127.0 x 118.9 mm, 102 parts (1 on the bottom side), 78 nets.

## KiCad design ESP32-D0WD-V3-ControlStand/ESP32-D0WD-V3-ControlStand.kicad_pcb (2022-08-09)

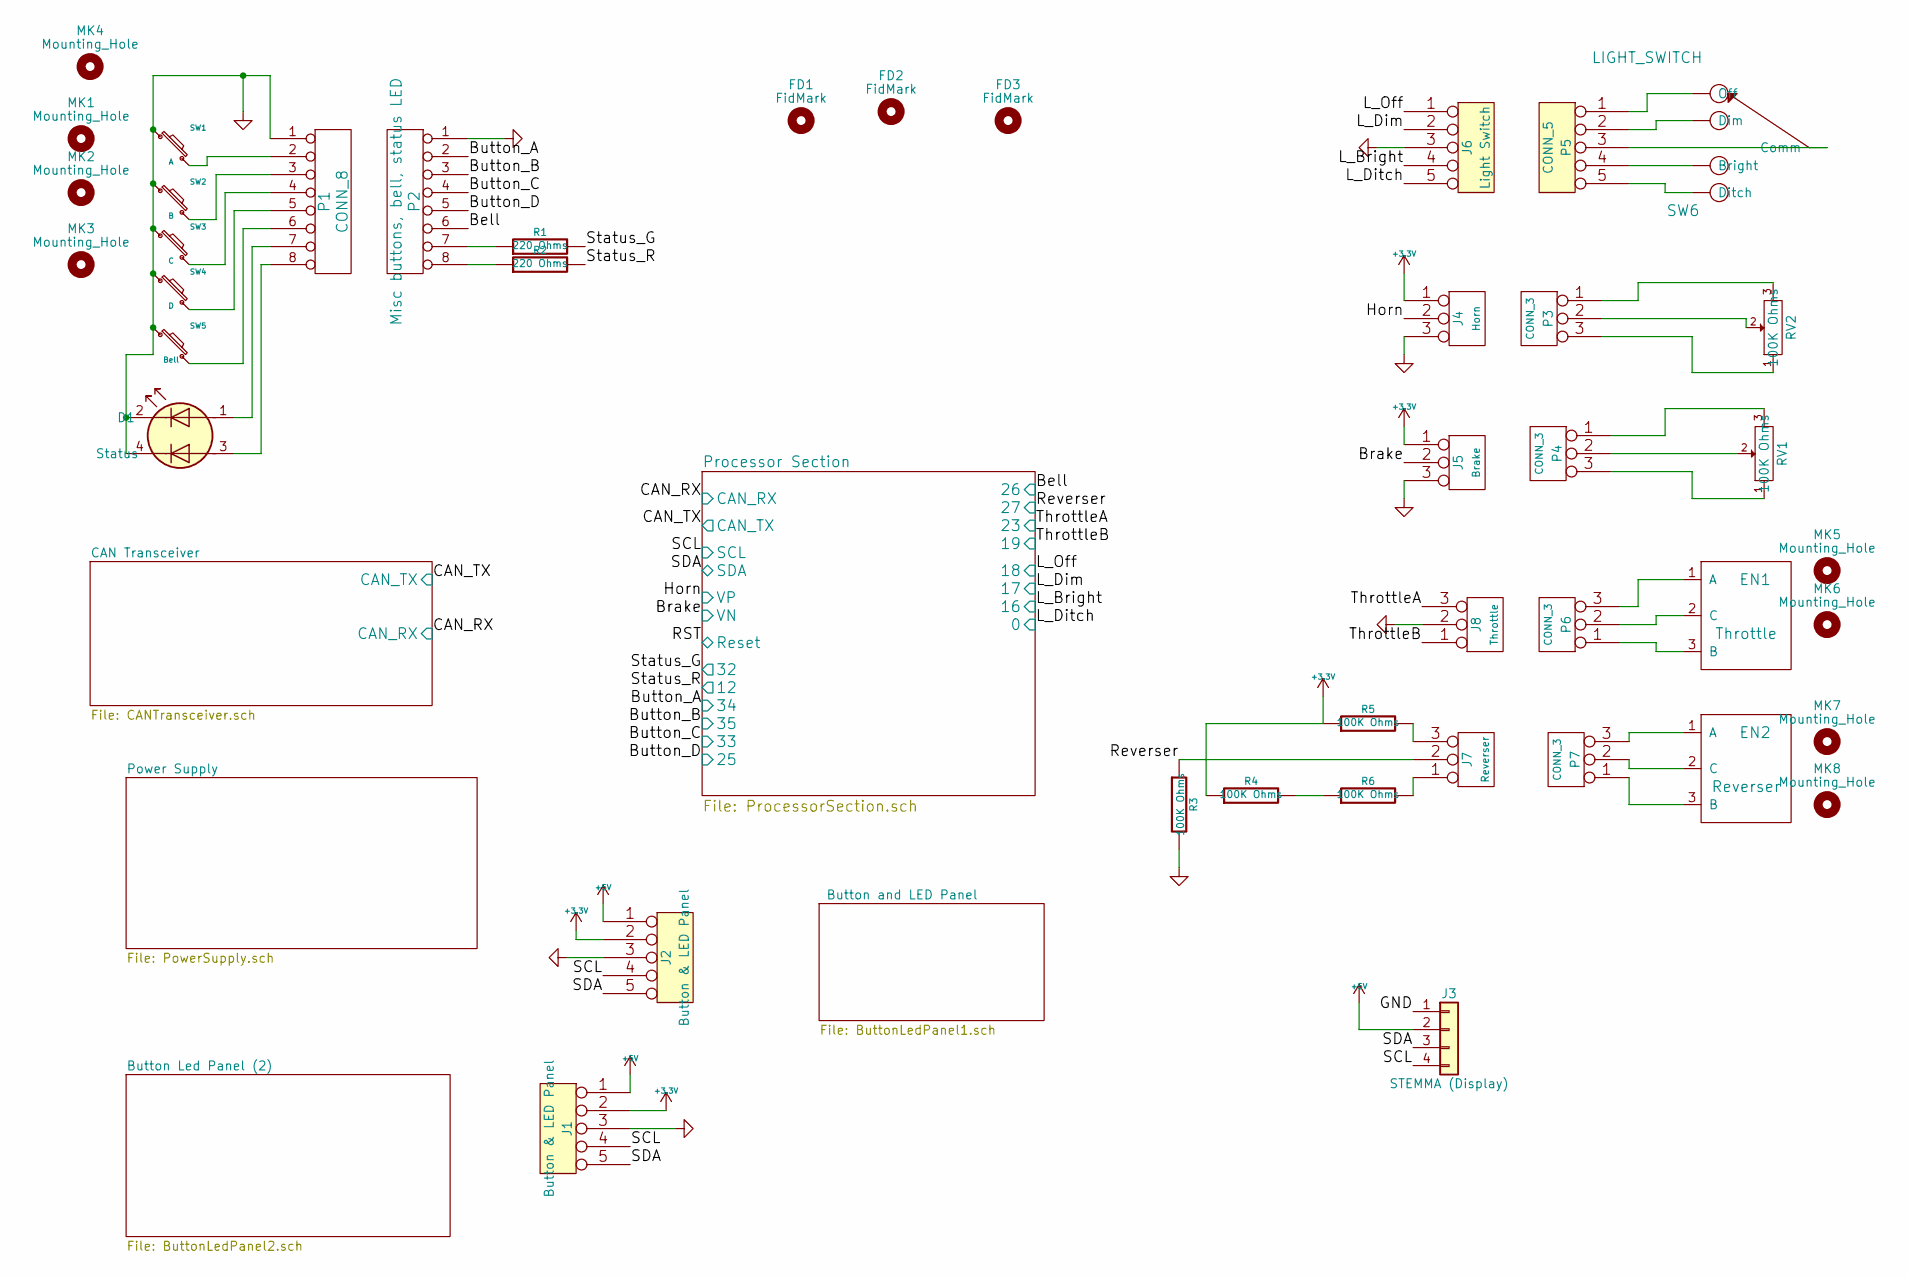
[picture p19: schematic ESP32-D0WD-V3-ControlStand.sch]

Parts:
D1: Status; APHB1608CGKSURKC; Mouser Part Number 604-APHB1608CGKSURKC
EN1: Throttle; Series25L-Encoder; Mouser Part Number 706-25LB10-Q
EN2: Reverser; ALPSEC12C; Mouser Part Number 652-PEC11R4325FN0012
FD1, FD2, FD3: FidMark; Fiducial_1mm_Dia_2.54mm_Outer_CopperTop
J1, J2: Button & LED Panel; Pin_Header_Straight_1x05_Pitch2.54mm; Mouser Part Number 523-G800W303018EU
J3: STEMMA (Display); JST_PH_B4B-PH-SM4-TB_04x2.00mm_Straight; Manufacturer_Part_Number B4B-PH-SM4-TB
J4: Horn; Pin_Header_Straight_1x03_Pitch2.54mm; Mouser Part Number 649-1012937890301BLF
J5: Brake; Pin_Header_Straight_1x03_Pitch2.54mm; Mouser Part Number 649-1012937890301BLF
J6: Light Switch; Pin_Header_Straight_1x05_Pitch2.54mm; Mouser Part Number 523-G800W303018EU
J7: Reverser; Pin_Header_Straight_1x03_Pitch2.54mm; Mouser Part Number 649-1012937890301BLF
J8: Throttle; Pin_Header_Straight_1x03_Pitch2.54mm; Mouser Part Number 649-1012937890301BLF
MK1, MK2, MK3, MK4, MK5, MK6, MK7, MK8: Mounting_Hole; MountingHole_2.5mm
P1: CONN_8; Pin_Header_Angled_1x08_Pitch2.54mm; Mouser Part Number 649-1012937990801BLF
P2: Misc buttons, bell, status LED; Pin_Header_Straight_1x08_Pitch2.54mm; Mouser Part Number 649-1012937890801BLF
P3, P4: CONN_3
P5: CONN_5
P6, P7: CONN_3; Pin_Header_Angled_1x03_Pitch2.54mm; Mouser Part Number 855-M20-9750346
R1, R2: 220 Ohms; R_0603; Mouser Part Number 603-AC0603FR-07220RL
R3, R4, R5, R6: 100K Ohms; R_0402; Mouser Part Number 279-CRGCQ0402J100K
RV1, RV2: 100K Ohms; Mouser Part Number 774-450T328F104A1A1
SW1: A; SW_SPST_EVQQ2; Mouser Part Number 667-EVQ-Q2U02W
SW2: B; SW_SPST_EVQQ2; Mouser part Number 667-EVQ-Q2U02W
SW3: C; SW_SPST_EVQQ2; Mouser Part Number 667-EVQ-Q2U02W
SW4: D; SW_SPST_EVQQ2; Mouser Part Number 667-EVQ-Q2U02W
SW5: Bell; SW_SPST_EVQQ2; Mouser Part Number 667-EVQ-Q2U02W
SW6: LIGHT_SWITCH

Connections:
+3V3: J1.2, J2.2, J4.1, J5.1, R4.1, R5.1; also elsewhere on the board
+5V: J1.1, J2.1, J3.2; also elsewhere on the board
/Bell: P2.6; also elsewhere on the board
/Brake: J5.2 (PM); also elsewhere on the board
/Button_A: P2.2; also elsewhere on the board
/Button_B: P2.3; also elsewhere on the board
/Button_C: P2.4; also elsewhere on the board
/Button_D: P2.5; also elsewhere on the board
/Horn: J4.2 (PM); also elsewhere on the board
/L_Bright: J6.4; also elsewhere on the board
/L_Dim: J6.2; also elsewhere on the board
/L_Ditch: J6.5; also elsewhere on the board
/L_Off: J6.1; also elsewhere on the board
/Reverser: J7.2 (PM), R3.1; also elsewhere on the board
/SCL: J1.4, J2.4, J3.4; also elsewhere on the board
/SDA: J1.5, J2.5, J3.3; also elsewhere on the board
/Status_G: R1.2; also elsewhere on the board
/Status_R: R2.2; also elsewhere on the board
/ThrottleA: J8.3; also elsewhere on the board
/ThrottleB: J8.1; also elsewhere on the board
GND: D1.2 (K1), D1.4 (K2), J1.3, J2.3, J3.1, J4.3, J5.3, J6.3, J8.2 (PM), P1.1, P2.1, R3.2, SW1.1, SW2.1, SW3.1, SW4.1, SW5.1; also elsewhere on the board
unnamed: D1.1 (A1), P1.7
unnamed: D1.3 (A2), P1.8
unnamed: EN1.1 (A), P6.3
unnamed: EN1.2 (C), P6.2 (PM)
unnamed: EN1.3 (B), P6.1
unnamed: EN2.1 (A), P7.3
unnamed: EN2.2 (C), P7.2 (PM)
unnamed: EN2.3 (B), P7.1
unnamed: J7.1, R6.2
unnamed: J7.3, R5.2
unnamed: P1.2, SW1.2
unnamed: P1.3, SW2.2
unnamed: P1.4, SW3.2
unnamed: P1.5, SW4.2
unnamed: P1.6, SW5.2
unnamed: P2.7, R1.1
unnamed: P2.8, R2.1
unnamed: P3.1, RV2.3
unnamed: P3.2 (PM), RV2.2
unnamed: P3.3, RV2.1
unnamed: P4.1, RV1.3
unnamed: P4.2 (PM), RV1.2
unnamed: P4.3, RV1.1
unnamed: P5.1, SW6.~
unnamed: P5.2, SW6.~
unnamed: P5.3, SW6.~
unnamed: P5.4, SW6.~
unnamed: P5.5, SW6.~
unnamed: R4.2, R6.1

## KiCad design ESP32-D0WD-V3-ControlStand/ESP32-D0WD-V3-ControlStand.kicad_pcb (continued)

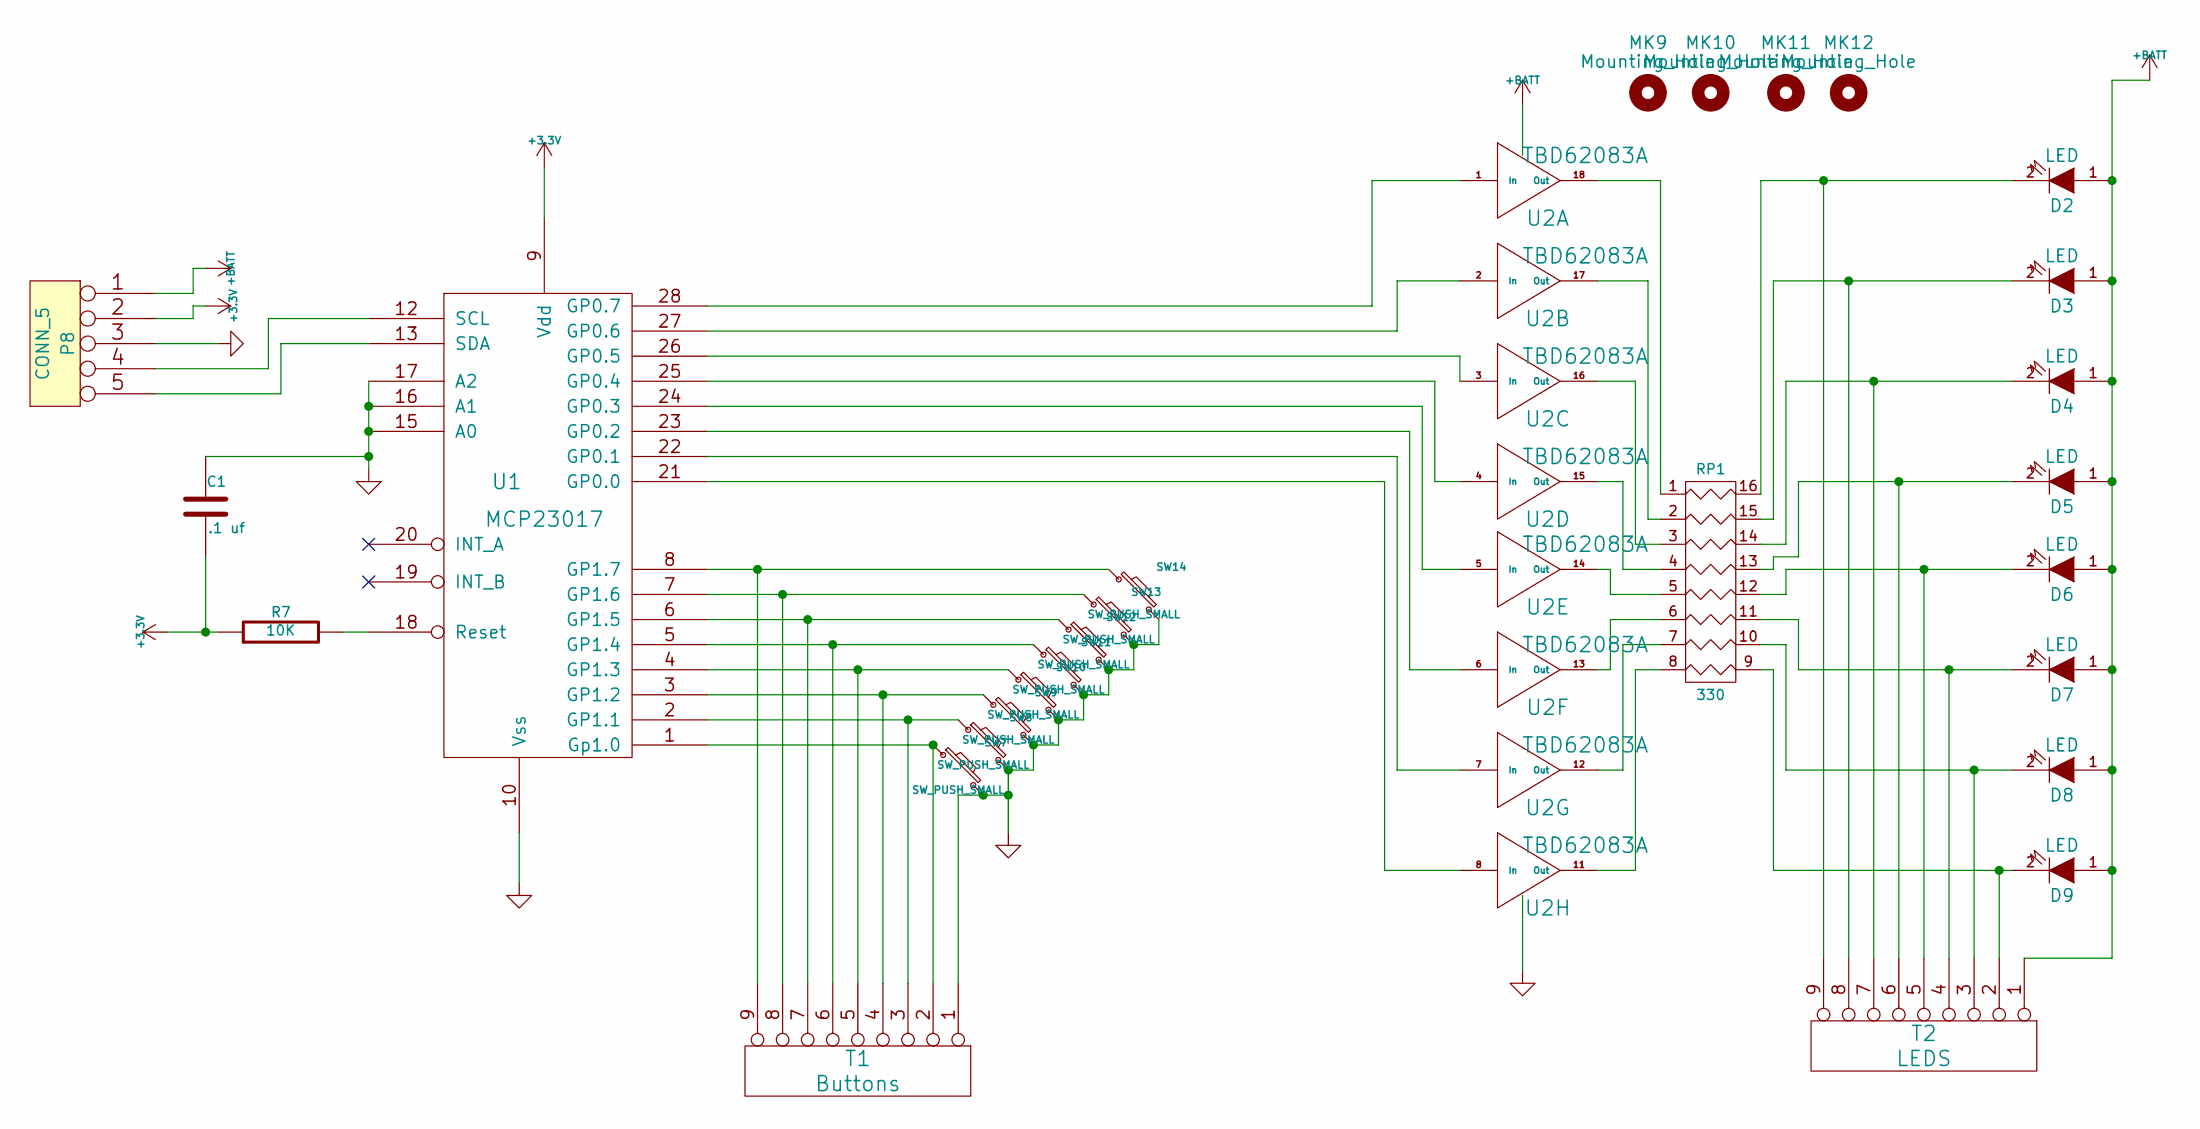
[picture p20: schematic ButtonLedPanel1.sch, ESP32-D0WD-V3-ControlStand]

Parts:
C1: .1 uf; C_0603; Mouser Part Number 710-885012206095
D2, D3, D4, D5, D6, D7, D8, D9: LED; LED_D5.0mm
MK9, MK10, MK11, MK12: Mounting_Hole; MountingHole_2.5mm
P8: CONN_5; Pin_Header_Angled_1x05_Pitch2.54mm; Mouser Part Number 649-1012937990501BLF
R7: 10K; R_0402; Mouser Part Number 603-RC0402JR-0710KL
RP1: 330; 4816P; Mouser Part Number 652-4816P-T1LF-330
SW7, SW8, SW9, SW10, SW11, SW12, SW13, SW14: SW_PUSH_SMALL; SW_PUSH_6mm; Mouser Part Number 179-TS026660BK160LCR
T1: Buttons; TerminalBlock_Pheonix_MPT-2.54mm_9pol; Mouser Part Number 651-1725724
T2: LEDS; TerminalBlock_Pheonix_MPT-2.54mm_9pol; Mouser Part Number 651-1725724
U1: MCP23017; SOIC-28W_7.5x17.9mm_Pitch1.27mm; Mouser Part Number 579-MCP23017-E/SO
U2: TBD62083A; SOIC-18W_7.5x11.6mm_Pitch1.27mm; Mouser Part Number 757-TBD62083AFG

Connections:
+3V3: C1.2, P8.2, R7.1, U1.9 (Vdd); also elsewhere on the board
+BATT: D2.1 (A), D3.1 (A), D4.1 (A), D5.1 (A), D6.1 (A), D7.1 (A), D8.1 (A), D9.1 (A), P8.1, T2.1, U2.10 (OC); also elsewhere on the board
GND: C1.1, P8.3, SW7.2, SW8.2, SW9.2, SW10.2, SW11.2, SW12.2, SW13.2, SW14.2, T1.1, U1.10 (Vss), U1.15 (A0), U1.16 (A1), U1.17 (A2), U2.9 (IC); also elsewhere on the board
unnamed: D2.2 (K), RP1.16 (R1), T2.9
unnamed: D3.2 (K), RP1.15 (R2), T2.8
unnamed: D4.2 (K), RP1.14 (R3), T2.7
unnamed: D5.2 (K), RP1.13 (R4), T2.6
unnamed: D6.2 (K), RP1.12 (R5), T2.5
unnamed: D7.2 (K), RP1.11 (R6), T2.4
unnamed: D8.2 (K), RP1.10 (R7), T2.3
unnamed: D9.2 (K), RP1.9 (R8), T2.2
unnamed: P8.4, U1.12 (SCL)
unnamed: P8.5, U1.13 (SDA)
unnamed: R7.2, U1.18 (Reset)
unnamed: RP1.1, U2.18 (Out)
unnamed: RP1.2, U2.17 (Out)
unnamed: RP1.3, U2.16 (Out)
unnamed: RP1.4, U2.15 (Out)
unnamed: RP1.5, U2.14 (Out)
unnamed: RP1.6, U2.13 (Out)
unnamed: RP1.7, U2.12 (Out)
unnamed: RP1.8, U2.11 (Out)
unnamed: SW7.1, T1.2, U1.1 (Gp1.0)
unnamed: SW8.1, T1.3, U1.2 (GP1.1)
unnamed: SW9.1, T1.4, U1.3 (GP1.2)
unnamed: SW10.1, T1.5, U1.4 (GP1.3)
unnamed: SW11.1, T1.6, U1.5 (GP1.4)
unnamed: SW12.1, T1.7, U1.6 (GP1.5)
unnamed: SW13.1, T1.8, U1.7 (GP1.6)
unnamed: SW14.1, T1.9, U1.8 (GP1.7)
unnamed: U1.21 (GP0.0), U2.8 (In)
unnamed: U1.22 (GP0.1), U2.7 (In)
unnamed: U1.23 (GP0.2), U2.6 (In)
unnamed: U1.24 (GP0.3), U2.5 (In)
unnamed: U1.25 (GP0.4), U2.4 (In)
unnamed: U1.26 (GP0.5), U2.3 (In)
unnamed: U1.27 (GP0.6), U2.2 (In)
unnamed: U1.28 (GP0.7), U2.1 (In)

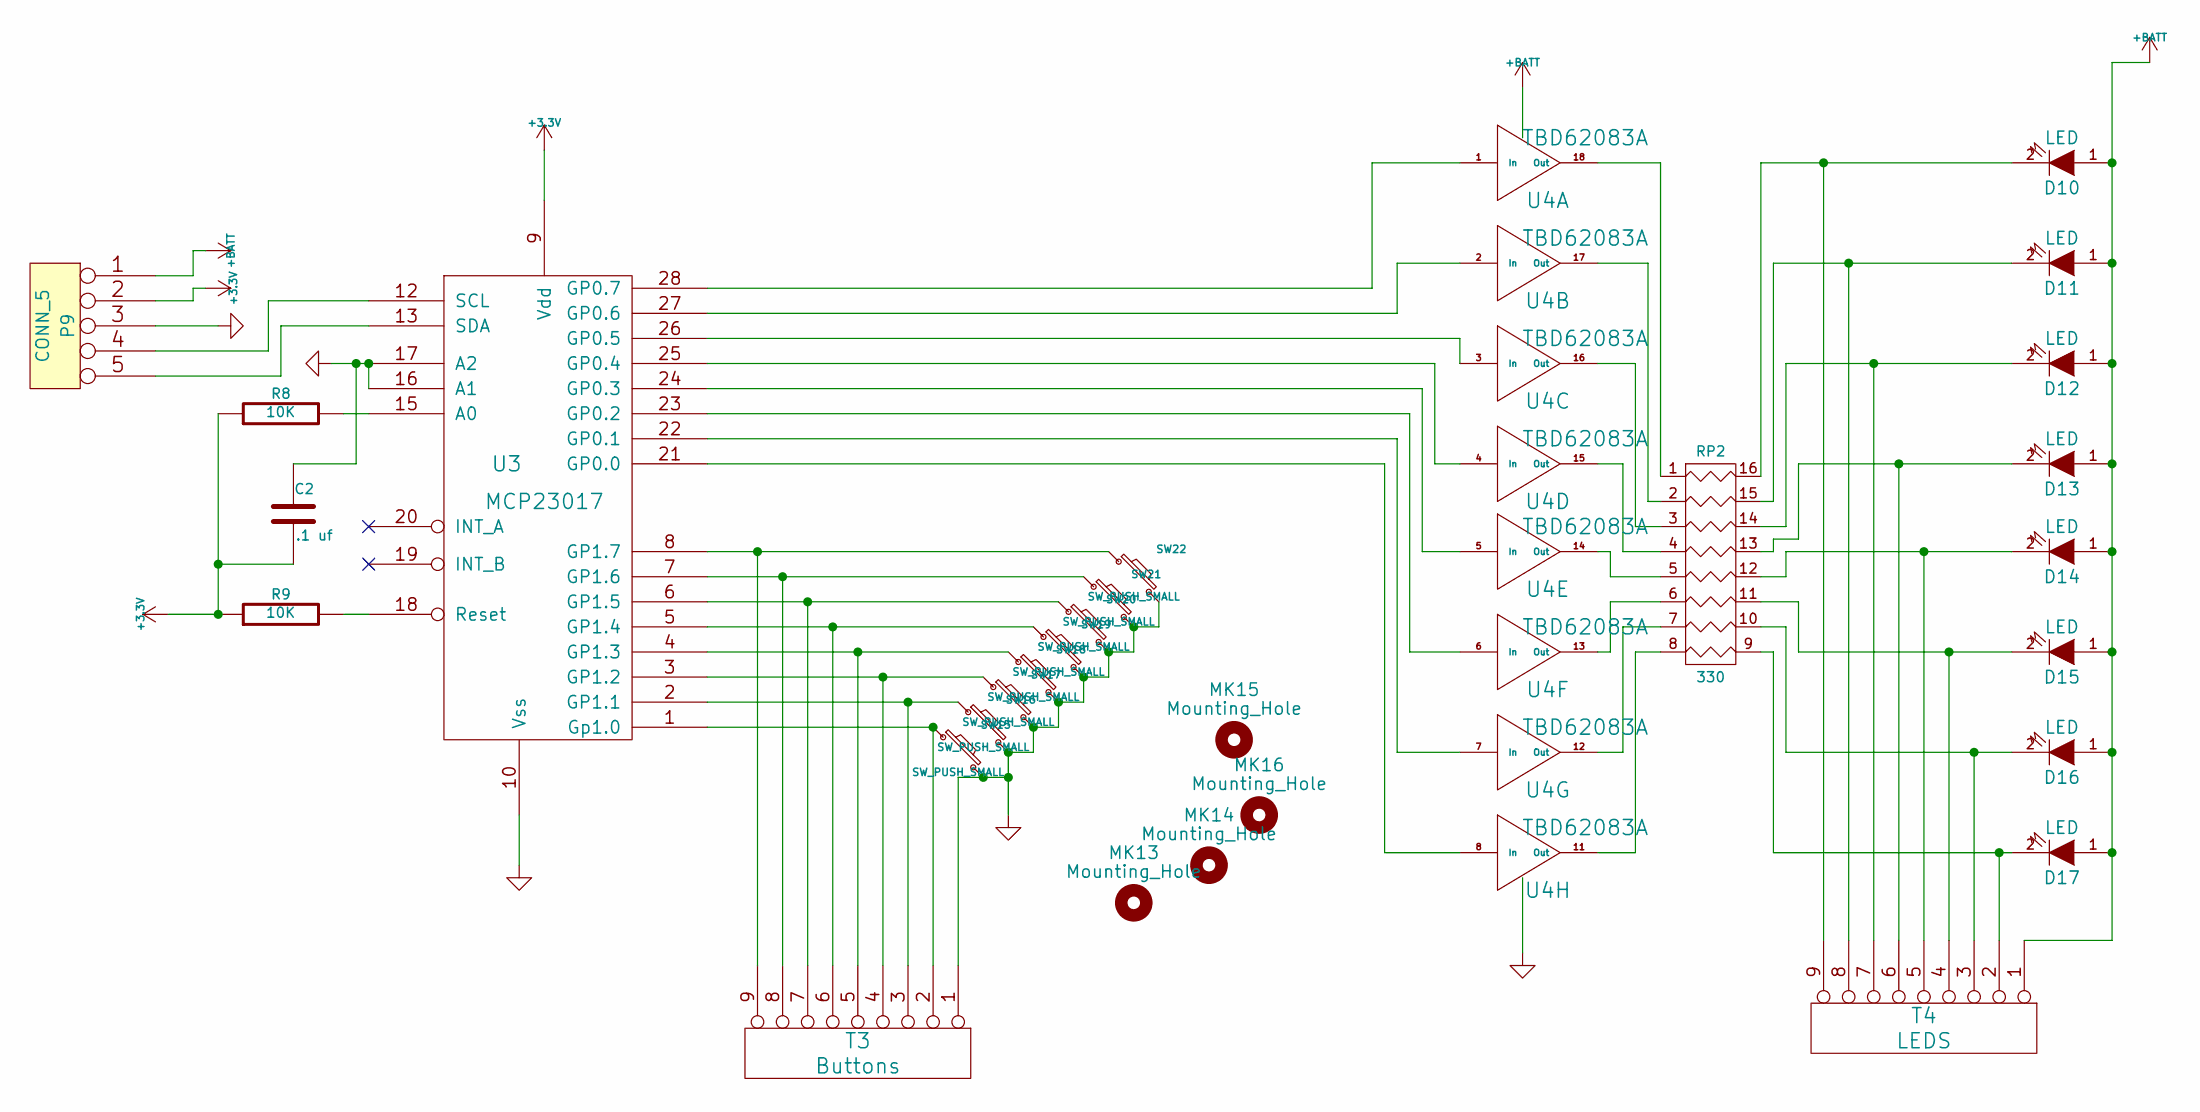
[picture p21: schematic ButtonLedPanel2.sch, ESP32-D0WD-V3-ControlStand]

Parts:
C2: .1 uf; C_0603; Mouser Part Number 710-885012206095
D10, D11, D12, D13, D14, D15, D16, D17: LED; LED_D5.0mm
MK13, MK14, MK15, MK16: Mounting_Hole; MountingHole_2.5mm
P9: CONN_5; Pin_Header_Angled_1x05_Pitch2.54mm; Mouser Part Number 649-1012937990501BLF
R8, R9: 10K; R_0402; Mouser Part Number 603-RC0402JR-0710KL
RP2: 330; 4816P; Mouser Part Number 652-4816P-T1LF-330
SW15, SW16, SW17, SW18, SW19, SW20, SW21, SW22: SW_PUSH_SMALL; SW_PUSH_6mm; Mouser Part Number 179-TS026660BK160LCR
T3: Buttons; TerminalBlock_Pheonix_MPT-2.54mm_9pol; Mouser Part Number 651-1725724
T4: LEDS; TerminalBlock_Pheonix_MPT-2.54mm_9pol; Mouser Part Number 651-1725724
U3: MCP23017; SOIC-28W_7.5x17.9mm_Pitch1.27mm; Mouser Part Number 79-MCP23017-E/SO
U4: TBD62083A; SOIC-18W_7.5x11.6mm_Pitch1.27mm; Mouser Part Number 757-TBD62083AFG

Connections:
+3V3: C2.2, P9.2, R8.1, R9.1, U3.9 (Vdd); also elsewhere on the board
+BATT: D10.1 (A), D11.1 (A), D12.1 (A), D13.1 (A), D14.1 (A), D15.1 (A), D16.1 (A), D17.1 (A), P9.1, T4.1, U4.10 (OC); also elsewhere on the board
GND: C2.1, P9.3, SW15.2, SW16.2, SW17.2, SW18.2, SW19.2, SW20.2, SW21.2, SW22.2, T3.1, U3.10 (Vss), U3.16 (A1), U3.17 (A2), U4.9 (IC); also elsewhere on the board
unnamed: D10.2 (K), RP2.16 (R1), T4.9
unnamed: D11.2 (K), RP2.15 (R2), T4.8
unnamed: D12.2 (K), RP2.14 (R3), T4.7
unnamed: D13.2 (K), RP2.13 (R4), T4.6
unnamed: D14.2 (K), RP2.12 (R5), T4.5
unnamed: D15.2 (K), RP2.11 (R6), T4.4
unnamed: D16.2 (K), RP2.10 (R7), T4.3
unnamed: D17.2 (K), RP2.9 (R8), T4.2
unnamed: P9.4, U3.12 (SCL)
unnamed: P9.5, U3.13 (SDA)
unnamed: R8.2, U3.15 (A0)
unnamed: R9.2, U3.18 (Reset)
unnamed: RP2.1, U4.18 (Out)
unnamed: RP2.2, U4.17 (Out)
unnamed: RP2.3, U4.16 (Out)
unnamed: RP2.4, U4.15 (Out)
unnamed: RP2.5, U4.14 (Out)
unnamed: RP2.6, U4.13 (Out)
unnamed: RP2.7, U4.12 (Out)
unnamed: RP2.8, U4.11 (Out)
unnamed: SW15.1, T3.2, U3.1 (Gp1.0)
unnamed: SW16.1, T3.3, U3.2 (GP1.1)
unnamed: SW17.1, T3.4, U3.3 (GP1.2)
unnamed: SW18.1, T3.5, U3.4 (GP1.3)
unnamed: SW19.1, T3.6, U3.5 (GP1.4)
unnamed: SW20.1, T3.7, U3.6 (GP1.5)
unnamed: SW21.1, T3.8, U3.7 (GP1.6)
unnamed: SW22.1, T3.9, U3.8 (GP1.7)
unnamed: U3.21 (GP0.0), U4.8 (In)
unnamed: U3.22 (GP0.1), U4.7 (In)
unnamed: U3.23 (GP0.2), U4.6 (In)
unnamed: U3.24 (GP0.3), U4.5 (In)
unnamed: U3.25 (GP0.4), U4.4 (In)
unnamed: U3.26 (GP0.5), U4.3 (In)
unnamed: U3.27 (GP0.6), U4.2 (In)
unnamed: U3.28 (GP0.7), U4.1 (In)

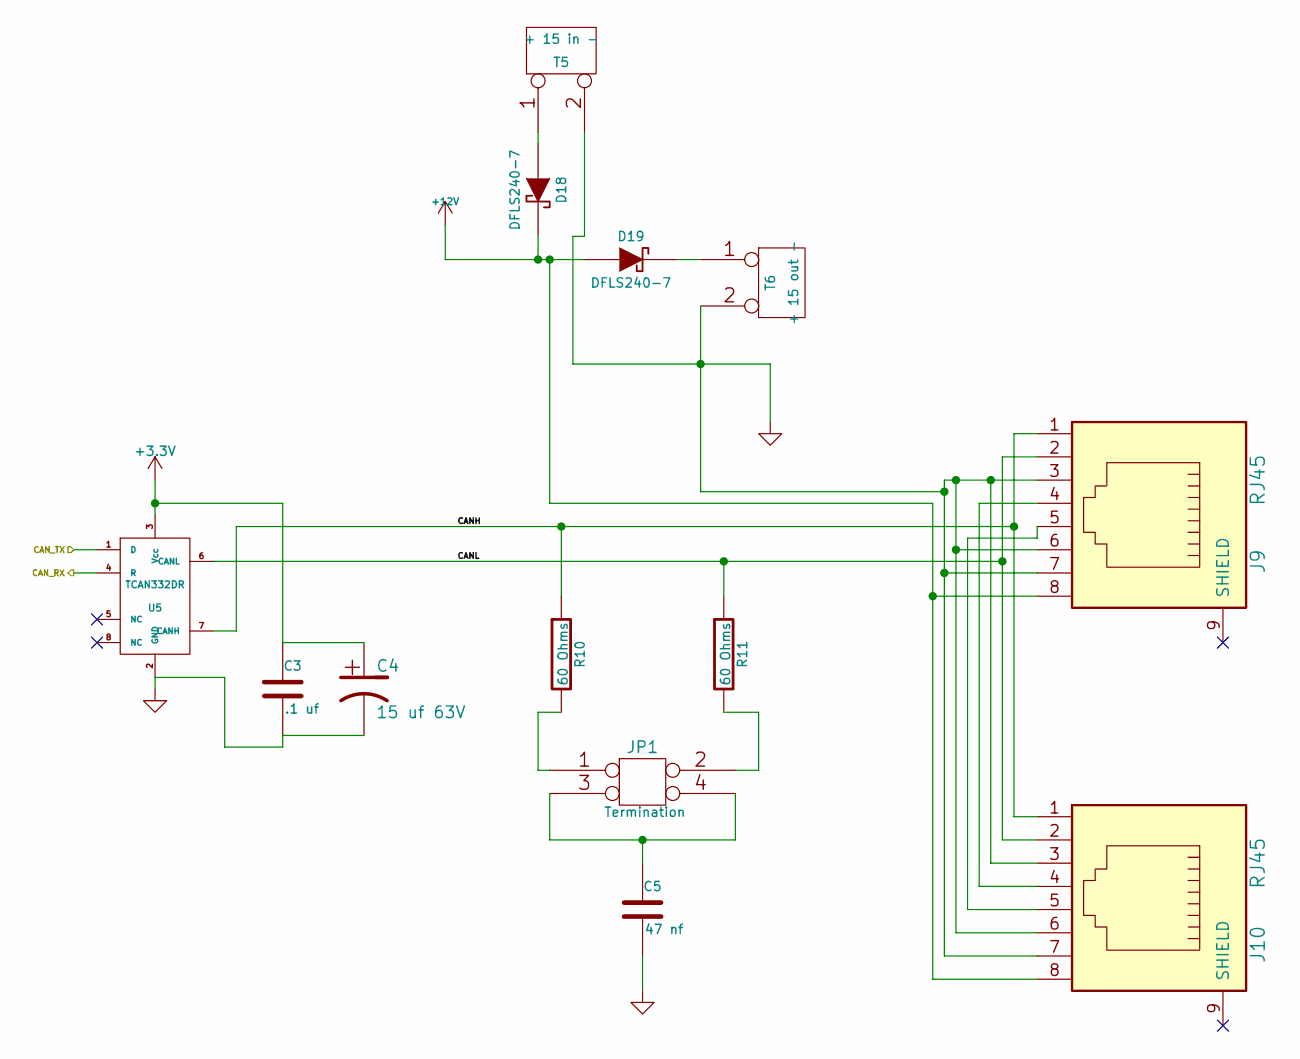
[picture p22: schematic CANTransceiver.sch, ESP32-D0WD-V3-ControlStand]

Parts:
C3: .1 uf; C_0603; Mouser Part Number 710-885012206095
C4: 15 uf 63V; CP_Elec_4x5.7; Mouser Part Number 647-UUD1C150MCL
C5: 47 nf; C_0603; Mouser Part Number 710-885012206093
D18, D19: DFLS240-7; D_PowerDI-123; Mouser Part Number 621-DFLS240-7
J9, J10: RJ45; RJ45_8N-S; Mouser Part Number 710-615008144221
JP1: Termination; Pin_Header_Straight_2x02_Pitch2.54mm; Mouser Part Number 649-67997-404HLF
R10, R11: 60 Ohms; R_1206; Mouser Part Number 71-CRCW120660R0KNAIF
T5: + 15 in -; TerminalBlock_Pheonix_MPT-2.54mm_2pol; Mouser Part Number 651-1725656
T6: + 15 out -; TerminalBlock_Pheonix_MPT-2.54mm_2pol; Mouser Part Number 651-1725656
U5: TCAN332DR; SOIC-8_3.9x4.9mm_Pitch1.27mm; Mouser Part Number 595-TCAN332DR

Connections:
+3V3: C3.1, C4.1, U5.3 (Vcc); also elsewhere on the board
+12V: D18.2 (K), D19.1 (A), J9.8, J10.8; also elsewhere on the board
/CAN Transceiver/CANH: J9.1, J10.1, R10.1, U5.7 (CANH)
/CAN Transceiver/CANL: J9.2, J10.2, R11.1, U5.6 (CANL)
/CAN_RX: U5.4 (R); also elsewhere on the board
/CAN_TX: U5.1 (D); also elsewhere on the board
GND: C3.2, C4.2, C5.2, J9.3, J9.6, J9.7, J10.3, J10.6, J10.7, T5.2 (PM), T6.2 (PM), U5.2 (GND); also elsewhere on the board
unnamed: C5.1, JP1.3, JP1.4
unnamed: D18.1 (A), T5.1
unnamed: D19.2 (K), T6.1
unnamed: J9.4, J10.4
unnamed: J9.5, J10.5
unnamed: JP1.1, R10.2
unnamed: JP1.2, R11.2

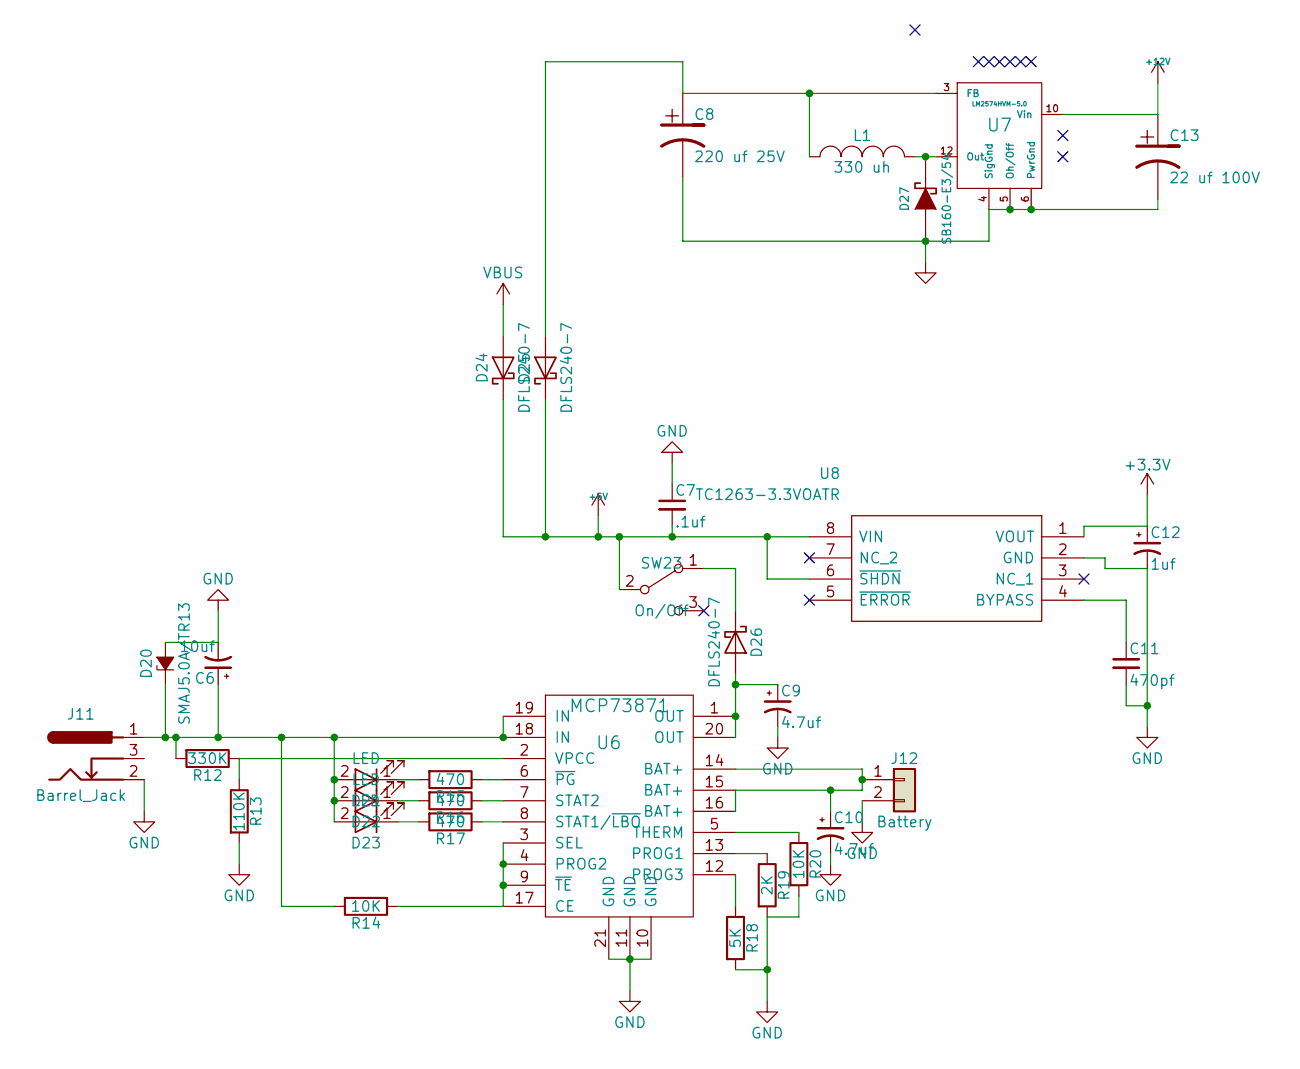
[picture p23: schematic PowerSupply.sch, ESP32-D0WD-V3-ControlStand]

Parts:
C6: 10uf; CP_Elec_4x5.7; Mouser Part Number 710-865080340001
C7: .1uf; C_0402; Mouser Part Number 81-GRM155R62A104KE4J
C8: 220 uf 25V; CP_Elec_8x10; Mouser Part Number 647-UWT1E221MNL1GS
C9, C10: 4.7uf; CP_Elec_4x5.7; Mouser Part Number 710-865080640004
C11: 470pf; C_0402; Mouser Part Number 80-C0402C471K4RAUTO
C12: 1uf; C_0603_POL; Mouser Part Number 74-TMCJ1C105MTRF
C13: 22 uf 100V; CP_Elec_8x10; Mouser Part Number 647-UUX2A220MNL6GS
D20: SMAJ5.0A/TR13; D_SMA; Mouser Part Number 603-SMAJ5.0A/TR13
D21: LED; LED_0402; Mouser Part Number 710-150040GS73220
D22: LED; LED_0402; Mouser Part Number 710-150040YS73220
D23: LED; LED_0402; Mouser Part Number 710-150040RS73220
D24, D25, D26: DFLS240-7; D_PowerDI-123; Mouser Part Number 621-DFLS240-7
D27: SB160-E3/54; D_SMB; Mouser Part Number 610-CMSH1-60TR13
J11: Barrel_Jack; BARREL_JACK; Mouser Part Number 992-CON-SOCJ-2155
J12: Battery; JST_PH_B2B-PH-SM4-TB_02x2.00mm_Straight; Manufacturer_Part_Number B2B-PH-SM4-TB
L1: 330 uh; SRN1060; Mouser Part Number 652-SRN1060-331M
R12: 330K; R_0402; Mouser Part Number 603-AF0402FR-07330KL
R13: 110K; R_0402; Mouser Part Number 603-RC0402JR-13110KL
R14, R20: 10K; R_0402; Mouser Part Number 603-RC0402JR-0710KL
R15, R16, R17: 470; R_0402; Mouser Part Number 603-RC0402JR-07470RL
R18: 5K; R_0402; Mouser Part Number 603-RC0402FR-075KL
R19: 2K; R_0402; Mouser Part Number 603-RC0402FR-132KL
SW23: On/Off; SW_SPDT_CK-JS102011SAQN; Mouser Part Number 611-JS102011SAQN
U6: MCP73871; QFN-20-1EP_4x4mm_Pitch0.5mm; Mouser Part Number 579-MCP73871-3CAI/ML
U7: LM2574HVM-5.0; SOIC-14_7.4x8.7mm_Pitch1.27mm; Mouser Part Number 926-LM2574HVM5.0NOPB
U8: TC1263-3.3VOATR; SO-8_5.3x6.2mm_Pitch1.27mm; Manufacturer_Part_Number TC1263-3.3VOATR

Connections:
+3V3: C12.1, U8.1 (VOUT); also elsewhere on the board
+5V: C7.2, D24.1 (K), D25.1 (K), SW23.2 (B), U8.6 (~SHDN), U8.8 (VIN); also elsewhere on the board
+12V: C13.1, U7.10 (Vin); also elsewhere on the board
GND: C6.2, C7.1, C8.2, C9.2, C10.2, C11.2, C12.2, C13.2, D20.2 (A), D27.1 (A), J11.2, J12.2, R13.2, R18.2, R19.2, R20.2, U6.10 (GND), U6.11 (GND), U6.21 (GND), U7.4 (SigGnd), U7.5 (Oh/Off), U7.6 (PwrGnd), U8.2 (GND); also elsewhere on the board
unnamed: C6.1, D20.1 (K), D21.2 (A), D22.2 (A), D23.2 (A), J11.1, R12.2, R14.2, U6.18 (IN), U6.19 (IN)
unnamed: C8.1, D25.2 (A), L1.1, U7.3 (FB)
unnamed: C9.1, D26.2 (A), U6.1 (OUT), U6.20 (OUT)
unnamed: C10.1, J12.1, U6.14 (BAT+), U6.15 (BAT+), U6.16 (BAT+)
unnamed: C11.1, U8.4 (BYPASS)
unnamed: D21.1 (K), R15.2
unnamed: D22.1 (K), R16.2
unnamed: D23.1 (K), R17.2
unnamed: D26.1 (K), SW23.1 (A)
unnamed: D27.2 (K), L1.2, U7.12 (Out)
unnamed: R12.1, R13.1, U6.2 (VPCC)
unnamed: R14.1, U6.3 (SEL), U6.4 (PROG2), U6.9 (~TE), U6.17 (CE)
unnamed: R15.1, U6.6 (~PG)
unnamed: R16.1, U6.7 (STAT2)
unnamed: R17.1, U6.8 (STAT1/~LBO)
unnamed: R18.1, U6.12 (PROG3)
unnamed: R19.1, U6.13 (PROG1)
unnamed: R20.1, U6.5 (THERM)
VBUS: D24.2 (A); also elsewhere on the board

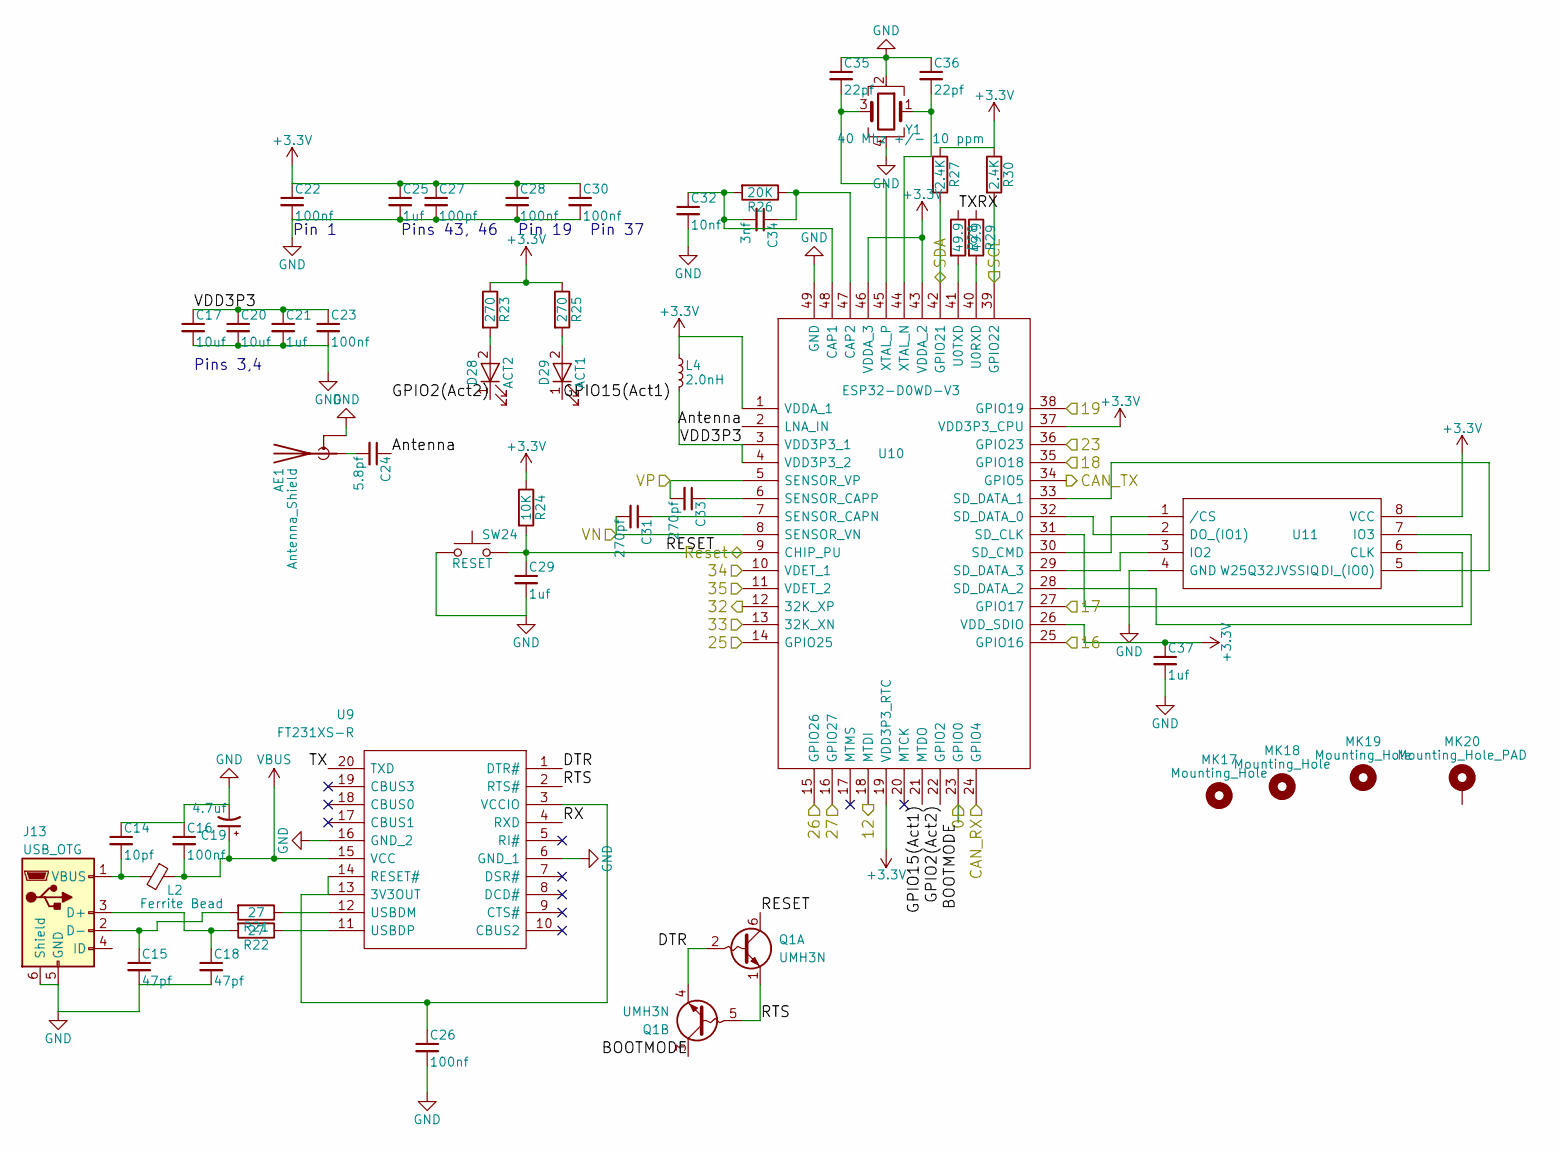
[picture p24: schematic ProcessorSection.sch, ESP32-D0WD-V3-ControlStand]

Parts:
AE1: Antenna_Shield; Antenna
C14: 10pf; C_0402; Mouser Part Number 80-C0402C100K5RAUTO
C15, C18: 47pf; C_0402; Mouser Part Number 80-C0402C470K5RAUTO
C16, C26: 100nf; C_0402; Mouser Part Number 80-C0402C104K8R
C17, C20: 10uf; C_0805; Mouser Part Number 187-CL21A106MQFNNNE
C19: 4.7uf; CP_Elec_4x5.7; Mouser Part Number 710-865080540002
C21, C25, C29, C37: 1uf; C_0402; Mouser Part Number 80-C0402C101K8RAUTO
C22, C23, C28, C30: 100nf; C_0402; Mouser Part Number 710-885012105001
C24: 5.8pf; C_0402
C27: 100pf; C_0402; Mouser Part Number 80-C0402C101K3RAUTO
C31, C33: 270pf; C_0402
C32: 10nf; C_0402; Mouser Part Number 81-GRM155R61E103KA1D
C34: 3nf; C_0402; Mouser Part Number 81-GRM1557U1A302JA1D
C35, C36: 22pf; C_0402; Mouser Part Number 187-CL05C220JB5NNND
D28: ACT2; LED_0402; Mouser Part Number 710-150040SS73220
D29: ACT1; LED_0402; Mouser Part Number 710-150040GS73220
J13: USB_OTG; USB_Micro-B_Molex_47346-0001; Mouser Part Number 538-47346-0001
L2: Ferrite Bead; L_0402; Mouser Part Number 810-MMZ1005S800CTD25
L4: 2.0nH; L_0402; Mouser Part Number 810-MLG1005S2N0ST000
MK17, MK18, MK19: Mounting_Hole; MountingHole_2.5mm
MK20: Mounting_Hole_PAD; MountingHole_2.5mm_Pad
Q1: UMH3N; SOT-363_SC-70-6; Mouser Part Number 755-UMH3NFHATN
R21, R22: 27; R_0402; Mouser Part Number 603-RT0402FRE0727RL
R23, R25: 270; R_0402; Mouser Part Number 754-RR0510P-271D
R24: 10K; R_0402; Mouser Part Number 603-RC0402JR-1310KL
R26: 20K; R_0402; Mouser Part Number 791-RMC10K203FTH
R27, R30: 2.4K; R_0402; Mouser Part Number 71-CRCW06032K40JNEAC
R28, R29: 49.9; R_0402; Mouser Part Number 791-RMC1/16SK49R9FTH
SW24: RESET; PTS647SM38SMTR2LFS; Mouser Part Number 611-PTS647SN70SMTR2L
U9: FT231XS-R; SSOP-20_5.3x7.2mm_Pitch0.65mm; Manufacturer_Part_Number FT231XS-R
U10: ESP32-D0WD-V3; QFN35P500X500X90-49N-D; Manufacturer_Part_Number ESP32-D0WD-V3; Mouser Part Number 356-ESP32-D0WD-V3
U11: W25Q32JVSSIQ; SOIC-8_3.9x4.9mm_Pitch1.27mm; Mouser Part Number 454-W25Q32JVSSIQ
Y1: 40 Mhz +/- 10 ppm; FA20_H; Mouser Part Number 732-FA-20H40MF10Z-W3

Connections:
+3V3: C22.1, C25.1, C27.1, C28.1, C30.1, C37.1, L4.1, R23.1, R24.1, R25.1, R27.1, R30.1, U10.1 (VDDA_1), U10.19 (VDD3P3_RTC), U10.26 (VDD_SDIO), U10.37 (VDD3P3_CPU), U10.43 (VDDA_2), U10.46 (VDDA_3), U11.8 (VCC); also elsewhere on the board
/Bell: U10.15 (GPIO26); also elsewhere on the board
/Brake: C31.2, U10.8 (SENSOR_VN); also elsewhere on the board
/Button_A: U10.10 (VDET_1); also elsewhere on the board
/Button_B: U10.11 (VDET_2); also elsewhere on the board
/Button_C: U10.13 (32K_XN); also elsewhere on the board
/Button_D: U10.14 (GPIO25); also elsewhere on the board
/CAN_RX: U10.24 (GPIO4); also elsewhere on the board
/CAN_TX: U10.34 (GPIO5); also elsewhere on the board
/Horn: C33.2, U10.5 (SENSOR_VP); also elsewhere on the board
/L_Bright: U10.25 (GPIO16); also elsewhere on the board
/L_Dim: U10.27 (GPIO17); also elsewhere on the board
/L_Ditch: Q1.3 (C2), U10.23 (GPIO0); also elsewhere on the board
/L_Off: U10.35 (GPIO18); also elsewhere on the board
/Processor Section/Antenna: C24.1, U10.2 (LNA_IN)
/Processor Section/DTR: Q1.2 (B1), Q1.4 (E2), U9.1 (DTR#)
/Processor Section/GPIO2(Act2): D28.1 (K), U10.22 (GPIO2)
/Processor Section/GPIO15(Act1): D29.1 (K), U10.21 (MTDO)
/Processor Section/RTS: Q1.1 (E1), Q1.5 (B2), U9.2 (RTS#)
/Processor Section/RX: R29.1, U9.4 (RXD)
/Processor Section/TX: R28.1, U9.20 (TXD)
/Processor Section/VDD3P3: C17.1, C20.1, C21.1, C23.1, L4.2, U10.3 (VDD3P3_1), U10.4 (VDD3P3_2)
/RST: C29.1, Q1.6 (C1), R24.2, SW24.2, U10.9 (CHIP_PU)
/Reverser: U10.16 (GPIO27); also elsewhere on the board
/SCL: R30.2, U10.39 (GPIO22); also elsewhere on the board
/SDA: R27.2, U10.42 (GPIO21); also elsewhere on the board
/Status_G: U10.12 (32K_XP); also elsewhere on the board
/Status_R: U10.18 (MTDI); also elsewhere on the board
/ThrottleA: U10.36 (GPIO23); also elsewhere on the board
/ThrottleB: U10.38 (GPIO19); also elsewhere on the board
GND: AE1.2 (Shield), C14.1, C15.2, C16.1, C17.2, C18.2, C19.2, C20.2, C21.2, C22.2, C23.2, C25.2, C26.2, C27.2, C28.2, C29.2, C30.2, C32.2, C35.1, C36.1, C37.2, J13.5 (GND), J13.6 (Shield), SW24.1, U9.6 (GND_1), U9.16 (GND_2), U10.49 (GND), U11.4 (GND), Y1.2, Y1.4; also elsewhere on the board
unnamed: AE1.1 (A), C24.2
unnamed: C14.2, J13.1 (VBUS), L2.2
unnamed: C15.1, J13.2 (D-), R21.2
unnamed: C18.1, J13.3 (D+), R22.2
unnamed: C26.1, U9.3 (VCCIO), U9.13 (3V3OUT), U9.14 (RESET#)
unnamed: C31.1, U10.7 (SENSOR_CAPN)
unnamed: C32.1, C34.2, R26.2, U10.48 (CAP1)
unnamed: C33.1, U10.6 (SENSOR_CAPP)
unnamed: C34.1, R26.1, U10.47 (CAP2)
unnamed: C35.2, U10.45 (XTAL_P), Y1.3
unnamed: C36.2, U10.44 (XTAL_N), Y1.1
unnamed: D28.2 (A), R23.2
unnamed: D29.2 (A), R25.2
unnamed: R21.1, U9.12 (USBDM)
unnamed: R22.1, U9.11 (USBDP)
unnamed: R28.2, U10.41 (U0TXD)
unnamed: R29.2, U10.40 (U0RXD)
unnamed: U10.28 (SD_DATA_2), U11.7 (IO3)
unnamed: U10.29 (SD_DATA_3), U11.3 (IO2)
unnamed: U10.30 (SD_CMD), U11.1 (/CS)
unnamed: U10.31 (SD_CLK), U11.6 (CLK)
unnamed: U10.32 (SD_DATA_0), U11.2 (DO_(IO1))
unnamed: U10.33 (SD_DATA_1), U11.5 (DI_(IO0))
VBUS: C16.2, C19.1, L2.1, U9.15 (VCC); also elsewhere on the board

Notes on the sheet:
Pins 3,4
Pin 1
Pins 43, 46
Pin 19
Pin 37

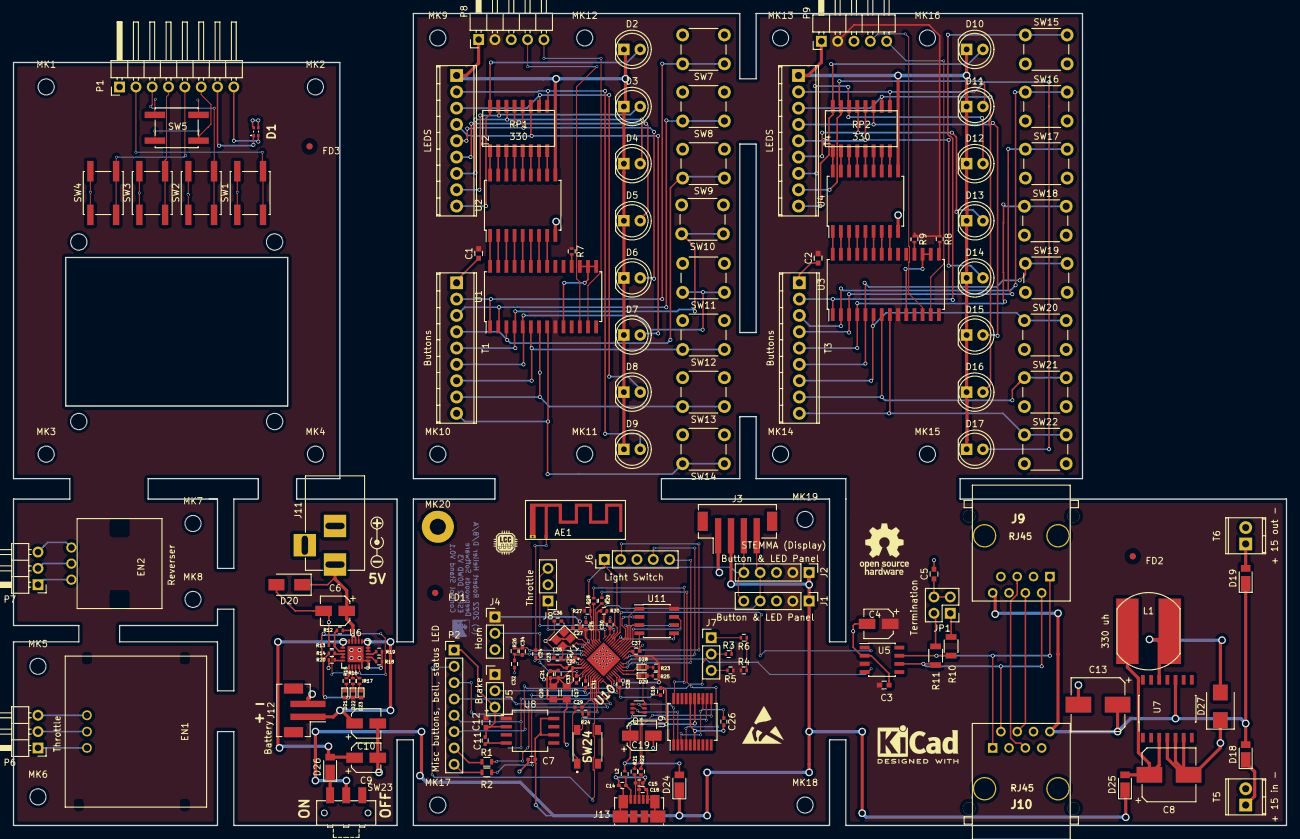
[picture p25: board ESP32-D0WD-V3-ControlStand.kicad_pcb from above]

Board: 2 copper layers, 198.1 x 126.4 mm, 189 parts (0 on the bottom side), 174 nets.

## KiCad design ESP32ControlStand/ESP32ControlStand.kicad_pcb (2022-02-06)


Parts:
CON101: BARREL_JACK
D101: Status
EN101: Throttle; Mouser Part Number 706-25LB10-Q
EN102: Reverser; Mouser Part Number 652-PEC11R4325FN0012
J101, J105: Button & LED Panel
J102: Horn
J103: Brake
J104: I2C Display
J106: Light Switch
J107: Reverser
J108: Throttle
J109: On-Off Switch
MOD101: I2C_DISPLAY
P101: CONN_8
P102: Misc buttons, bell, status LED
P103, P104, P106, P107: CONN_3
P105: CONN_5
P108: CONN_6
R1, R2: 2.4K Ohms; R_Axial_DIN0207_L6.3mm_D2.5mm_P2.54mm_Vertical
R101, R102: 220 Ohms
R103, R104, R105, R106: 100K Ohms
RV101, RV102: 100K Ohms; Mouser Part Number 774-450T328F104A1A1
SW101: A
SW102: B
SW103: C
SW104: D
SW105: Bell
SW106: LIGHT_SWITCH
U101: ADAFRUIT_POWERBOOST_500
U102: TTGO-T1

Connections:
+3.3V: J101.2, J102.1, J103.1, J105.2, R1.1, R2.1, R104.1, R105.1, U102.1 (3V3); also elsewhere on the board
+5V: CON101.1, J101.1, J104.1, J105.1, U101.8 (5V), U102.30 (+5V); also elsewhere on the board
/Bell: P102.6, U102.10 (26)
/Brake: J103.2 (PM), U102.4 (VN)
/Button_A: P102.2, U102.5 (34)
/Button_B: P102.3, U102.6 (35)
/Button_C: P102.4, U102.8 (33)
/Button_D: P102.5, U102.9 (25)
/CAN_RX: U102.24 (4); also elsewhere on the board
/CAN_TX: U102.27 (5); also elsewhere on the board
/Horn: J102.2 (PM), U102.3 (VP)
/L_Bright: J106.4, U102.25 (16)
/L_Dim: J106.2, U102.26 (17)
/L_Ditch: J106.5, U102.23 (0)
/L_Off: J106.1, U102.28 (18)
/MISO: U102.22 (2)
/MOSI: U102.21 (15)
/RST: J104.4, U102.2 (EN)
/Reverser: J107.2 (PM), R103.1, U102.11 (27)
/SCL: J101.4, J104.5, J105.4, R1.2, U102.34 (22)
/SCLK: U102.12 (14)
/SDA: J101.5, J104.6, J105.5, R2.2, U102.31 (21)
/Status_G: R101.2, U102.7 (32)
/Status_R: R102.2, U102.13 (12)
/ThrottleA: J108.1, U102.35 (23)
/ThrottleB: J108.3, U102.29 (19)
GND: CON101.2, D101.2 (K), J101.3, J102.3, J103.3, J104.3, J105.3, J106.3, J108.2 (PM), J109.1, P101.1, P102.1, R103.2, SW101.1, SW102.1, SW103.1, SW104.1, SW105.1, U101.2 (GND), U101.5 (GND), U101.7 (GND), U102.14 (GND), U102.36 (GND); also elsewhere on the board
unnamed: D101.1 (A1), P101.8
unnamed: D101.3 (A2), P101.7
unnamed: EN101.1 (A), P106.1
unnamed: EN101.2 (C), P106.2 (PM)
unnamed: EN101.3 (B), P106.3
unnamed: EN102.1 (A), P107.1
unnamed: EN102.2 (C), P107.2 (PM)
unnamed: EN102.3 (B), P107.3
unnamed: J107.1, R105.2
unnamed: J107.3, R106.2
unnamed: J109.2 (PM), U101.4 (EN)
unnamed: MOD101.1 (VIn), P108.1
unnamed: MOD101.2 (3v3), P108.2
unnamed: MOD101.3 (GND), P108.3
unnamed: MOD101.4 (RST), P108.4
unnamed: MOD101.5 (SCL), P108.5
unnamed: MOD101.6 (SDA), P108.6
unnamed: P101.2, SW101.2
unnamed: P101.3, SW102.2
unnamed: P101.4, SW103.2
unnamed: P101.5, SW104.2
unnamed: P101.6, SW105.2
unnamed: P102.7, R101.1
unnamed: P102.8, R102.1
unnamed: P103.1, RV102.3
unnamed: P103.2 (PM), RV102.2
unnamed: P103.3, RV102.1
unnamed: P104.1, RV101.3
unnamed: P104.2 (PM), RV101.2
unnamed: P104.3, RV101.1
unnamed: P105.1, SW106.~
unnamed: P105.2, SW106.~
unnamed: P105.3, SW106.~
unnamed: P105.4, SW106.~
unnamed: P105.5, SW106.~
unnamed: R104.2, R106.1


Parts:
C201: .1 uf
D201, D202, D203, D204, D205, D206, D207, D208: LED
P201: CONN_5
R201: 10K Ohms
RP201: R_PACK8
SW201, SW202, SW203, SW204, SW205, SW206, SW207, SW208: SW_PUSH_SMALL
T201: Buttons
T202: LEDS
U201: MCP23017
U202: TBD62083A

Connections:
+3.3V: C201.2, P201.2, R201.1, U201.9 (Vdd); also elsewhere on the board
+BATT: D201.1 (A), D202.1 (A), D203.1 (A), D204.1 (A), D205.1 (A), D206.1 (A), D207.1 (A), D208.1 (A), P201.1, T202.1, U202.10 (OC); also elsewhere on the board
GND: C201.1, P201.3, SW201.2, SW202.2, SW203.2, SW204.2, SW205.2, SW206.2, SW207.2, SW208.2, T201.1, U201.10 (Vss), U201.15 (A0), U201.16 (A1), U201.17 (A2), U202.9 (IC); also elsewhere on the board
unnamed: D201.2 (K), RP201.16 (R1), T202.9
unnamed: D202.2 (K), RP201.15 (R2), T202.8
unnamed: D203.2 (K), RP201.14 (R3), T202.7
unnamed: D204.2 (K), RP201.13 (R4), T202.6
unnamed: D205.2 (K), RP201.12 (R5), T202.5
unnamed: D206.2 (K), RP201.11 (R6), T202.4
unnamed: D207.2 (K), RP201.10 (R7), T202.3
unnamed: D208.2 (K), RP201.9 (R8), T202.2
unnamed: P201.4, U201.12 (SCL)
unnamed: P201.5, U201.13 (SDA)
unnamed: R201.2, U201.18 (Reset)
unnamed: RP201.1, U202.18 (Out)
unnamed: RP201.2, U202.17 (Out)
unnamed: RP201.3, U202.16 (Out)
unnamed: RP201.4, U202.15 (Out)
unnamed: RP201.5, U202.14 (Out)
unnamed: RP201.6, U202.13 (Out)
unnamed: RP201.7, U202.12 (Out)
unnamed: RP201.8, U202.11 (Out)
unnamed: SW201.1, T201.2, U201.1 (Gp1.0)
unnamed: SW202.1, T201.3, U201.2 (GP1.1)
unnamed: SW203.1, T201.4, U201.3 (GP1.2)
unnamed: SW204.1, T201.5, U201.4 (GP1.3)
unnamed: SW205.1, T201.6, U201.5 (GP1.4)
unnamed: SW206.1, T201.7, U201.6 (GP1.5)
unnamed: SW207.1, T201.8, U201.7 (GP1.6)
unnamed: SW208.1, T201.9, U201.8 (GP1.7)
unnamed: U201.21 (GP0.0), U202.8 (In)
unnamed: U201.22 (GP0.1), U202.7 (In)
unnamed: U201.23 (GP0.2), U202.6 (In)
unnamed: U201.24 (GP0.3), U202.5 (In)
unnamed: U201.25 (GP0.4), U202.4 (In)
unnamed: U201.26 (GP0.5), U202.3 (In)
unnamed: U201.27 (GP0.6), U202.2 (In)
unnamed: U201.28 (GP0.7), U202.1 (In)


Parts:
C301: .1 uf
D301, D302, D303, D304, D305, D306, D307, D308: LED
P301: CONN_5
R301, R302: 10K Ohms
RP301: R_PACK8
SW301, SW302, SW303, SW304, SW305, SW306, SW307, SW308: SW_PUSH_SMALL
T301: Buttons
T302: LEDS
U301: MCP23017
U302: TBD62083A

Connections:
+3.3V: C301.2, P301.2, R301.1, R302.1, U301.9 (Vdd); also elsewhere on the board
+BATT: D301.1 (A), D302.1 (A), D303.1 (A), D304.1 (A), D305.1 (A), D306.1 (A), D307.1 (A), D308.1 (A), P301.1, T302.1, U302.10 (OC); also elsewhere on the board
GND: C301.1, P301.3, SW301.2, SW302.2, SW303.2, SW304.2, SW305.2, SW306.2, SW307.2, SW308.2, T301.1, U301.10 (Vss), U301.16 (A1), U301.17 (A2), U302.9 (IC); also elsewhere on the board
unnamed: D301.2 (K), RP301.16 (R1), T302.9
unnamed: D302.2 (K), RP301.15 (R2), T302.8
unnamed: D303.2 (K), RP301.14 (R3), T302.7
unnamed: D304.2 (K), RP301.13 (R4), T302.6
unnamed: D305.2 (K), RP301.12 (R5), T302.5
unnamed: D306.2 (K), RP301.11 (R6), T302.4
unnamed: D307.2 (K), RP301.10 (R7), T302.3
unnamed: D308.2 (K), RP301.9 (R8), T302.2
unnamed: P301.4, U301.12 (SCL)
unnamed: P301.5, U301.13 (SDA)
unnamed: R301.2, U301.15 (A0)
unnamed: R302.2, U301.18 (Reset)
unnamed: RP301.1, U302.18 (Out)
unnamed: RP301.2, U302.17 (Out)
unnamed: RP301.3, U302.16 (Out)
unnamed: RP301.4, U302.15 (Out)
unnamed: RP301.5, U302.14 (Out)
unnamed: RP301.6, U302.13 (Out)
unnamed: RP301.7, U302.12 (Out)
unnamed: RP301.8, U302.11 (Out)
unnamed: SW301.1, T301.2, U301.1 (Gp1.0)
unnamed: SW302.1, T301.3, U301.2 (GP1.1)
unnamed: SW303.1, T301.4, U301.3 (GP1.2)
unnamed: SW304.1, T301.5, U301.4 (GP1.3)
unnamed: SW305.1, T301.6, U301.5 (GP1.4)
unnamed: SW306.1, T301.7, U301.6 (GP1.5)
unnamed: SW307.1, T301.8, U301.7 (GP1.6)
unnamed: SW308.1, T301.9, U301.8 (GP1.7)
unnamed: U301.21 (GP0.0), U302.8 (In)
unnamed: U301.22 (GP0.1), U302.7 (In)
unnamed: U301.23 (GP0.2), U302.6 (In)
unnamed: U301.24 (GP0.3), U302.5 (In)
unnamed: U301.25 (GP0.4), U302.4 (In)
unnamed: U301.26 (GP0.5), U302.3 (In)
unnamed: U301.27 (GP0.6), U302.2 (In)
unnamed: U301.28 (GP0.7), U302.1 (In)


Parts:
C401: .1 uf; Mouser Part Number 21RZ310-RC
C402: 15 uf 63V; Mouser Part Number 710-860080773002
C403: 47 nf; Mouser Part Number 75-1C10Z5U473M050B
D401, D402: SB240E; Mouser Part Number 625-SB240-E3
J401, J402: RJ45; Mouser Part Number 710-615008144221
JP401: Termination; Mouser Part Number 649-67997-404HLF
R401, R402: 60 Ohms; Mouser Part Number 71-RN60C60R0B/R
T401: + 15 in -; Mouser Part Number 651-1725656
T402: + 15 out -; Mouser Part Number 651-1725656
U401: TCAN332DR; Mouser Part Number 595-TCAN332DR
U402: SN65HVD233-HT; Mouser Part Number 595-SN65HVD233SJD

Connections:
+3.3V: C401.1, C402.1, U401.3 (Vcc), U402.3 (Vcc); also elsewhere on the board
+12V: D401.2 (K), D402.1 (A), J401.8, J402.8; also elsewhere on the board
/CAN Transceiver/CANH: J401.1, J402.1, R401.1, U401.7 (CANH), U402.7 (CANH)
/CAN Transceiver/CANL: J401.2, J402.2, R402.1, U401.6 (CANL), U402.6 (CANL)
/CAN_RX: U401.4 (R), U402.4 (R); also elsewhere on the board
/CAN_TX: U401.1 (D), U402.1 (D); also elsewhere on the board
GND: C401.2, C402.2, C403.2, J401.3, J401.6, J401.7, J402.3, J402.6, J402.7, T401.2 (PM), T402.2 (PM), U401.2 (GND), U402.2 (GND), U402.5 (LBK), U402.8 (RS); also elsewhere on the board
unnamed: C403.1, JP401.3, JP401.4
unnamed: D401.1 (A), T401.1
unnamed: D402.2 (K), T402.1
unnamed: J401.4, J402.4
unnamed: J401.5, J402.5
unnamed: JP401.1, R401.2
unnamed: JP401.2, R402.2

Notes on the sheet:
Use only one of U1 or U2, not both. U2 is the older through hole part and U1 is the newer SMD part.


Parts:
C501: 220 uf 25V; Mouser Part Number 140-REA221M1EBK0811P
C502: 22 uf 100V; Mouser Part Number 140-REA220M2ABK0811P
D501: SB160-E3/54; Mouser Part Number 625-SB160-E3
L501: 330 uh; Mouser Part Number PE-52627NL
U501: LM2574N-5.0; Mouser Part Number 926-LM2574N-5.0/NOPB

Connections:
+5V: C501.1, L501.1, U501.1 (FB); also elsewhere on the board
+12V: C502.1, U501.5 (Vin); also elsewhere on the board
GND: C501.2, C502.2, D501.1 (A), U501.2 (SigGnd), U501.3 (Oh/Off), U501.4 (PwrGnd); also elsewhere on the board
unnamed: D501.2 (K), L501.2, U501.7 (Out)


Board: 2 copper layers, 184.1 x 144.1 mm, 120 parts (1 on the bottom side), 126 nets.

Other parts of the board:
MH: MountingHole_2-5mm_RevA_Date21Jun2010
MH#2, MH#3, MH#4, MH#5, MH#6, MH#7, MH#8, MH#9, MH#10, MH#11, MH#12, MH#13, MH#14, MH#15, MH#16, MH#17, MH#18, MH#19: MountingHole_2-5mm_RevA_Date21Jun2010

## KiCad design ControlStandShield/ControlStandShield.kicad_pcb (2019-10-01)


Board: 2 copper layers, 68.6 x 53.3 mm, 40 parts (0 on the bottom side), 53 nets.

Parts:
C1, C2: .1 uf; C1
K4: Throttle; PIN_ARRAY_3X1
K5: Auto Brake; PIN_ARRAY_3X1
K6: Ind. Brake; PIN_ARRAY_3X1
K8: Unit Selector; PIN_ARRAY_3X1
P1: Power; Socket_Strip_Arduino_1x08
P2: Analog; Socket_Strip_Arduino_1x06
P3: Digital; Socket_Strip_Arduino_1x10
P4: Digital; Socket_Strip_Arduino_1x08
P5, P6, P7, P8: CONN_01X01; Arduino_1pin
P10: Reverser; PIN_ARRAY_4x1
P12: Horn; PIN_ARRAY_2X1
P13: Unit Select Display; pin_array_4x2
P15: Aux LED Indicators; PIN_ARRAY_5x2
P18: Misc Switches; pin_array_4x2
R1, R2: 500K Ohms; R4
R3, R11: 10K Ohms; R4
R4, R5, R6, R7, R8, R9, R10: 150 Ohms; R4
R12, R13, R14, R15, R16, R17, R18, R19: 220 Ohms; R1
U1: 74LS47; DIP-16__300
U2: MCP23008; DIP-18__300

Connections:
+5V: C1.1, C2.1, K4.1, K5.1, K6.1, P1.5, P10.1, P13.1, P15.1, P18.1, R1.2, R3.1, R11.1, U1.16, U2.18
/A0: K4.2, P2.1
/A1: K5.2, P2.2
/A2: K6.2, P2.3
/A3: P2.4, P10.4
/A4(SDA): P3.2, U2.2
/A5(SCL): P3.1, U2.1
/D2: K8.1, P4.6
/D3: K8.3, P4.5
/D4: P4.4, P12.1
/D5: P4.3, U1.7
/D6: P4.2, U1.1
/D7: P4.1, U1.2
/D8: P3.10, P18.2
/D9: P3.9, P18.3
/D10: P3.8, P18.4
/D11: P3.7, P18.5
/D12: P3.6, P18.6
/D13: P3.5, P18.7
GND: C1.2, C2.2, K4.3, K5.3, K6.3, K8.2, P1.6, P1.7, P3.4, P10.3, P12.2, P15.10, P18.8, R2.1, U1.6, U1.8, U2.3, U2.4, U2.5, U2.9
unnamed: P13.5, R7.2
unnamed: P13.4, R6.2
unnamed: P13.3, R5.2
unnamed: P13.2, R4.2
unnamed: R10.1, U1.14
unnamed: R8.1, U1.9
unnamed: R7.1, U1.10
unnamed: R6.1, U1.11
unnamed: R5.1, U1.12
unnamed: R4.1, U1.13
unnamed: R9.1, U1.15
unnamed: P13.8, R10.2
unnamed: P13.7, R9.2
unnamed: P13.6, R8.2
unnamed: P10.2, R1.1, R2.2
unnamed: P15.9, R19.2
unnamed: R19.1, U2.17
unnamed: P15.8, R18.2
unnamed: R18.1, U2.16
unnamed: P15.7, R17.2
unnamed: R17.1, U2.15
unnamed: P15.6, R16.2
unnamed: R16.1, U2.14
unnamed: P15.5, R15.2
unnamed: R15.1, U2.13
unnamed: P15.4, R14.2
unnamed: R14.1, U2.12
unnamed: P15.3, R13.2
unnamed: R13.1, U2.11
unnamed: P15.2, R12.2
unnamed: R12.1, U2.10
unnamed: R11.2, U2.6
unnamed: R3.2, U1.3, U1.4, U1.5

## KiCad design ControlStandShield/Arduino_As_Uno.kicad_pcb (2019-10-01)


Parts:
P1: Power; Socket_Strip_Arduino_1x08
P2: Analog; Socket_Strip_Arduino_1x06
P3: Digital; Socket_Strip_Arduino_1x10
P4: Digital; Socket_Strip_Arduino_1x08
P5, P6, P7, P8: CONN_01X01; Arduino_1pin

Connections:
+3V3: P1.4
+5V: P1.5
/0(Rx): P4.8
/1(Tx): P4.7
/2: P4.6
/3(**): P4.5
/4: P4.4
/5(**): P4.3
/6(**): P4.2
/7: P4.1
/8: P3.10
/9(**): P3.9
/10(**/SS): P3.8
/11(**/MOSI): P3.7
/12(MISO): P3.6
/13(SCK): P3.5
/A0: P2.1
/A1: P2.2
/A2: P2.3
/A3: P2.4
/A4(SDA): P2.5, P3.2
/A5(SCL): P2.6, P3.1
/AREF: P3.3
/IOREF: P1.2
/Reset: P1.3
/Vin: P1.8
GND: P1.6, P1.7, P3.4

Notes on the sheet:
Holes
Shield for Arduino that uses the same pin disposition like "Uno" board Rev 3.

Board: 2 copper layers, 8 parts (0 on the bottom side), 3 nets, no tracks yet.

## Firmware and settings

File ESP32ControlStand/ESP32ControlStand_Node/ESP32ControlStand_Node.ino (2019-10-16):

// -!- C++ -!- //////////////////////////////////////////////////////////////
//
//  System        : 
//  Module        : 
//  Object Name   : $RCSfile$
//  Revision      : $Revision$
//  Date          : $Date$
//  Author        : $Author$
//  Created By    : Robert Heller
//  Created       : Sun Oct 6 09:53:40 2019
//  Last Modified : <191016.1050>
//
//  Description	
//
//  Notes
//
//  History
//	
/////////////////////////////////////////////////////////////////////////////
//
//    Copyright (C) 2019  Robert Heller D/B/A Deepwoods Software
//			51 Locke Hill Road
//			Wendell, MA 01379-9728
//
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
// 
//
//////////////////////////////////////////////////////////////////////////////

#include <Arduino.h>
#include <SPI.h>
#include <Wire.h>
#include <Adafruit_GFX.h>
#include <Adafruit_SSD1306.h>
#include <SPIFFS.h>

#include <OpenMRNLite.h>
#include "openlcb/ConfiguredConsumer.hxx"
#include "openlcb/ConfiguredProducer.hxx"
#include "openlcb/MultiConfiguredConsumer.hxx"
#include "utils/GpioInitializer.hxx"
#include "openlcb/TractionThrottle.hxx"
#include <Adafruit_MCP23017.h>

// Configuration defines

// 1: How to connect to OpenLCB/LCC -- CAN or WiFi

// Pick an operating mode below, if you select USE_WIFI it will expose
// this node on WIFI if you select USE_CAN, this node will be available
// on CAN.
// Enabling both options will allow the ESP32 to be accessible from
// both WiFi and CAN interfaces.

#define USE_WIFI
//#define USE_CAN


// 2: Which (if any) of the MCP23017 button/LED boards is connected?
#define MCP23017_0
//#define MCP23017_1



#include "config.h"
#include "NODEID.h" // Get nodeid from an externally generated header file
#include "ArduinoExtenderGpio.h"
#include "ESP32ControlStand.h"

using mcp23017Gpio = ArduinoExtenderGpioTemplate<Adafruit_MCP23017>;


#if defined(USE_WIFI)
// Configuring WiFi accesspoint name and password
// ^^^^^^^^^^^^^^^^^^^^^^^^^^^^^^^^^^^^^^^^^^^^^^
// There are two options:
// 1) edit the sketch to set this information just below. Use quotes:
//     const char* ssid     = "linksys";
//     const char* password = "superSecret";
// 2) add a new file to the sketch folder called something.cpp with the
// following contents:
//     #include <OpenMRNLite.h>
//
//     char WIFI_SSID[] = "linksys";
//     char WIFI_PASS[] = "theTRUEsupers3cr3t";

/// This is the name of the WiFi network (access point) to connect to.
const char *ssid = WIFI_SSID;

/// Password of the wifi network.
const char *password = WIFI_PASS;

/// This is the hostname which the ESP32 will advertise via mDNS, it should be
/// unique.
const char *hostname = "esp32mrn";

// Uncomment this line to enable usage of ::select() within the Grid Connect
// code.
//OVERRIDE_CONST_TRUE(gridconnect_tcp_use_select);

#endif // USE_WIFI

#if defined(USE_CAN)
/// This is the ESP32 pin connected to the SN65HVD23x/MCP2551 R (RX) pin.
/// Recommended pins: 4, 16, 21.
/// Note: Any pin can be used for this other than 6-11 which are connected to
/// the onboard flash.
/// Note: If you are using a pin other than 4 you will likely need to adjust
/// the GPIO pin definitions for the outputs.
constexpr gpio_num_t CAN_RX_PIN = GPIO_NUM_4;

/// This is the ESP32 pin connected to the SN65HVD23x/MCP2551 D (TX) pin.
/// Recommended pins: 5, 17, 22.
/// Note: Any pin can be used for this other than 6-11 which are connected to
/// the onboard flash and 34-39 which are input only.
/// Note: If you are using a pin other than 5 you will likely need to adjust
/// the GPIO pin definitions for the outputs.
constexpr gpio_num_t CAN_TX_PIN = GPIO_NUM_5;

#endif // USE_CAN

/// This is the primary entrypoint for the OpenMRN/LCC stack.
OpenMRN openmrn(NODE_ID);

// note the dummy string below is required due to a bug in the GCC compiler
// for the ESP32
string dummystring("abcdef");

/// ConfigDef comes from config.h and is specific to this particular device and
/// target. It defines the layout of the configuration memory space and is also
/// used to generate the cdi.xml file. Here we instantiate the configuration
/// layout. The argument of offset zero is ignored and will be removed later.
static constexpr openlcb::ConfigDef cfg(0);

#if defined(USE_WIFI)
Esp32WiFiManager wifi_mgr(ssid, password, openmrn.stack(), cfg.seg().wifi());
#endif // USE_WIFI

#ifdef MCP23017_0
extern const mcp23017Gpio 
LED00_Pin, LED01_Pin, LED02_Pin, LED03_Pin, 
LED04_Pin, LED05_Pin, LED06_Pin, LED07_Pin, 
BUT00_Pin, BUT01_Pin, BUT02_Pin, BUT03_Pin,
BUT04_Pin, BUT05_Pin, BUT06_Pin, BUT07_Pin;

Adafruit_MCP23017 mcp0;

constexpr const mcp23017Gpio LED00_Pin(&mcp0,0,true,false);
constexpr const mcp23017Gpio LED01_Pin(&mcp0,1,true,false);
constexpr const mcp23017Gpio LED02_Pin(&mcp0,2,true,false);
constexpr const mcp23017Gpio LED03_Pin(&mcp0,3,true,false);
constexpr const mcp23017Gpio LED04_Pin(&mcp0,4,true,false);
constexpr const mcp23017Gpio LED05_Pin(&mcp0,5,true,false);
constexpr const mcp23017Gpio LED06_Pin(&mcp0,6,true,false);
constexpr const mcp23017Gpio LED07_Pin(&mcp0,7,true,false);
constexpr const mcp23017Gpio BUT00_Pin(&mcp0,8,false,true);
constexpr const mcp23017Gpio BUT01_Pin(&mcp0,9,false,true);
constexpr const mcp23017Gpio BUT02_Pin(&mcp0,10,false,true);
constexpr const mcp23017Gpio BUT03_Pin(&mcp0,11,false,true);
constexpr const mcp23017Gpio BUT04_Pin(&mcp0,12,false,true);
constexpr const mcp23017Gpio BUT05_Pin(&mcp0,13,false,true);
constexpr const mcp23017Gpio BUT06_Pin(&mcp0,14,false,true);
constexpr const mcp23017Gpio BUT07_Pin(&mcp0,15,false,true);

constexpr const Gpio *const LED0_set[] = {
    &LED00_Pin, &LED01_Pin, &LED02_Pin, &LED03_Pin, 
    &LED04_Pin, &LED05_Pin, &LED06_Pin, &LED07_Pin
};

openlcb::MultiConfiguredConsumer gpio_consumers(openmrn.stack()->node(),
    LED0_set, ARRAYSIZE(LED0_set), cfg.seg().mcp0().consumers());

openlcb::ConfiguredProducer BUT00_producer(openmrn.stack()->node(), cfg.seg().mcp0().producers().entry<0>(), &BUT00_Pin);
openlcb::ConfiguredProducer BUT01_producer(openmrn.stack()->node(), cfg.seg().mcp0().producers().entry<1>(), &BUT01_Pin);
openlcb::ConfiguredProducer BUT02_producer(openmrn.stack()->node(), cfg.seg().mcp0().producers().entry<2>(), &BUT02_Pin);
openlcb::ConfiguredProducer BUT03_producer(openmrn.stack()->node(), cfg.seg().mcp0().producers().entry<3>(), &BUT03_Pin);
openlcb::ConfiguredProducer BUT04_producer(openmrn.stack()->node(), cfg.seg().mcp0().producers().entry<4>(), &BUT04_Pin);
openlcb::ConfiguredProducer BUT05_producer(openmrn.stack()->node(), cfg.seg().mcp0().producers().entry<5>(), &BUT05_Pin);
openlcb::ConfiguredProducer BUT06_producer(openmrn.stack()->node(), cfg.seg().mcp0().producers().entry<6>(), &BUT06_Pin);
openlcb::ConfiguredProducer BUT07_producer(openmrn.stack()->node(), cfg.seg().mcp0().producers().entry<7>(), &BUT07_Pin);

// The producers need to be polled repeatedly for changes and to execute the
// debouncing algorithm. This class instantiates a refreshloop and adds the
// producers to it.
openlcb::RefreshLoop BUT0_refresh_loop(openmrn.stack()->node(),
    {
        BUT00_producer.polling(),
        BUT01_producer.polling(),
        BUT02_producer.polling(),
        BUT03_producer.polling(),
        BUT04_producer.polling(),
        BUT05_producer.polling(),
        BUT06_producer.polling(),
        BUT07_producer.polling()
    }
);
#endif

#ifdef MCP23017_1
extern const mcp23017Gpio 
LED10_Pin, LED11_Pin, LED12_Pin, LED13_Pin, 
LED14_Pin, LED15_Pin, LED16_Pin, LED17_Pin, 
BUT10_Pin, BUT11_Pin, BUT12_Pin, BUT13_Pin,
BUT14_Pin, BUT15_Pin, BUT16_Pin, BUT17_Pin;

Adafruit_MCP23017 mcp1;

constexpr const mcp23017Gpio LED10_Pin(&mcp1,0,true,false);
constexpr const mcp23017Gpio LED11_Pin(&mcp1,1,true,false);
constexpr const mcp23017Gpio LED12_Pin(&mcp1,2,true,false);
constexpr const mcp23017Gpio LED13_Pin(&mcp1,3,true,false);
constexpr const mcp23017Gpio LED14_Pin(&mcp1,4,true,false);
constexpr const mcp23017Gpio LED15_Pin(&mcp1,5,true,false);
constexpr const mcp23017Gpio LED16_Pin(&mcp1,6,true,false);
constexpr const mcp23017Gpio LED17_Pin(&mcp1,7,true,false);
constexpr const mcp23017Gpio BUT10_Pin(&mcp1,8,false,true);
constexpr const mcp23017Gpio BUT11_Pin(&mcp1,9,false,true);
constexpr const mcp23017Gpio BUT12_Pin(&mcp1,10,false,true);
constexpr const mcp23017Gpio BUT13_Pin(&mcp1,11,false,true);
constexpr const mcp23017Gpio BUT14_Pin(&mcp1,12,false,true);
constexpr const mcp23017Gpio BUT15_Pin(&mcp1,13,false,true);
constexpr const mcp23017Gpio BUT16_Pin(&mcp1,14,false,true);
constexpr const mcp23017Gpio BUT17_Pin(&mcp1,15,false,true);

constexpr const Gpio *const LED1_set[] = {
    &LED10_Pin, &LED11_Pin, &LED12_Pin, &LED13_Pin, 
    &LED14_Pin, &LED15_Pin, &LED16_Pin, &LED17_Pin
};

openlcb::MultiConfiguredConsumer gpio_consumers(openmrn.stack()->node(),
    LED1_set, ARRAYSIZE(LED1_set), cfg.seg().mcp1().consumers());

openlcb::ConfiguredProducer BUT10_producer(openmrn.stack()->node(), cfg.seg().mcp1().producers().entry<0>(), &BUT10_Pin);
openlcb::ConfiguredProducer BUT11_producer(openmrn.stack()->node(), cfg.seg().mcp1().producers().entry<1>(), &BUT11_Pin);
openlcb::ConfiguredProducer BUT12_producer(openmrn.stack()->node(), cfg.seg().mcp1().producers().entry<2>(), &BUT12_Pin);
openlcb::ConfiguredProducer BUT13_producer(openmrn.stack()->node(), cfg.seg().mcp1().producers().entry<3>(), &BUT13_Pin);
openlcb::ConfiguredProducer BUT14_producer(openmrn.stack()->node(), cfg.seg().mcp1().producers().entry<4>(), &BUT14_Pin);
openlcb::ConfiguredProducer BUT15_producer(openmrn.stack()->node(), cfg.seg().mcp1().producers().entry<5>(), &BUT15_Pin);
openlcb::ConfiguredProducer BUT16_producer(openmrn.stack()->node(), cfg.seg().mcp1().producers().entry<6>(), &BUT16_Pin);
openlcb::ConfiguredProducer BUT17_producer(openmrn.stack()->node(), cfg.seg().mcp1().producers().entry<7>(), &BUT17_Pin);

// The producers need to be polled repeatedly for changes and to execute the
// debouncing algorithm. This class instantiates a refreshloop and adds the
// producers to it.
openlcb::RefreshLoop BUT1_refresh_loop(openmrn.stack()->node(),
    {
        BUT10_producer.polling(),
        BUT11_producer.polling(),
        BUT12_producer.polling(),
        BUT13_producer.polling(),
        BUT14_producer.polling(),
        BUT15_producer.polling(),
        BUT16_producer.polling(),
        BUT17_producer.polling()
    }
);
#endif


ESP32ControlStand stand(openmrn.stack()->node(),
                        cfg.seg().controlstand());

openlcb::RefreshLoop stand_refresh_loop(openmrn.stack()->node(),
   { &stand });


class FactoryResetHelper : public DefaultConfigUpdateListener {
public:
    UpdateAction apply_configuration(int fd, bool initial_load,
                                     BarrierNotifiable *done) OVERRIDE {
        AutoNotify n(done);
        return UPDATED;
    }

    void factory_reset(int fd) override
    {
        cfg.userinfo().name().write(fd, openlcb::SNIP_STATIC_DATA.model_name);
        cfg.userinfo().description().write(
            fd, "OpenLCB + Arduino-ESP32 on an ESP32.");
#ifdef MCP23017_0
        for(int i = 0; i < openlcb::NUM_OUTPUTS; i++)
        {
            cfg.seg().mcp0().consumers().entry(i).description().write(fd, "");
        }
        for(int i = 0; i < openlcb::NUM_INPUTS; i++)
        {
            cfg.seg().mcp0().producers().entry(i).description().write(fd, "");
            CDI_FACTORY_RESET(cfg.seg().mcp0().producers().entry(i).debounce);
        }
#endif
#ifdef MCP23017_1
        for(int i = 0; i < openlcb::NUM_OUTPUTS; i++)
        {
            cfg.seg().mcp1().consumers().entry(i).description().write(fd, "");
        }
        for(int i = 0; i < openlcb::NUM_INPUTS; i++)
        {
            cfg.seg().mcp1().producers().entry(i).description().write(fd, "");
            CDI_FACTORY_RESET(cfg.seg().mcp1().producers().entry(i).debounce);
        }
#endif
    }
} factory_reset_helper;

namespace openlcb
{
    // Name of CDI.xml to generate dynamically.
    const char CDI_FILENAME[] = "/spiffs/cdi.xml";

    // This will stop openlcb from exporting the CDI memory space upon start.
    extern const char CDI_DATA[] = "";

    // Path to where OpenMRN should persist general configuration data.
    extern const char *const CONFIG_FILENAME = "/spiffs/openlcb_config";

    // The size of the memory space to export over the above device.
    extern const size_t CONFIG_FILE_SIZE = cfg.seg().size() + cfg.seg().offset();

    // Default to store the dynamic SNIP data is stored in the same persistant
    // data file as general configuration data.
    extern const char *const SNIP_DYNAMIC_FILENAME = CONFIG_FILENAME;
}

static const char rcsid[] = "@(#) : $Id$";

void setup() {
    Serial.begin(115200L);
    // Set up status LED Early and show Yellow (starting up)
    pinMode(STATUS_R,OUTPUT);
    digitalWrite(STATUS_R,HIGH);
    pinMode(STATUS_G,OUTPUT);
    digitalWrite(STATUS_G,HIGH);
    
    
    // Initialize the SPIFFS filesystem as our persistence layer
    if (!SPIFFS.begin())
    {
        printf("SPIFFS failed to mount, attempting to format and remount\n");
        if (!SPIFFS.begin(true))
        {
            printf("SPIFFS mount failed even with format, giving up!\n");
            // blink red
            digitalWrite(STATUS_G,LOW);
            while (1)
            {
                // Unable to start SPIFFS successfully, give up and wait
                // for WDT to kick in
                digitalWrite(STATUS_R,LOW);
                delay(500);
                digitalWrite(STATUS_R,HIGH);
                delay(500);
            }
        }
    }

    // Create the CDI.xml dynamically
    openmrn.create_config_descriptor_xml(cfg, openlcb::CDI_FILENAME);

    // Create the default internal configuration file
    openmrn.stack()->create_config_file_if_needed(cfg.seg().internal_config(),
        openlcb::CANONICAL_VERSION, openlcb::CONFIG_FILE_SIZE);

    // initialize all declared GPIO pins
#ifdef MCP23017_0
    mcp0.begin(0x20);
    LED00_Pin.hw_init();
    LED01_Pin.hw_init();
    LED02_Pin.hw_init();
    LED03_Pin.hw_init();
    LED04_Pin.hw_init();
    LED05_Pin.hw_init();
    LED06_Pin.hw_init();
    LED07_Pin.hw_init();
    BUT00_Pin.hw_init();
    BUT01_Pin.hw_init();
    BUT02_Pin.hw_init();
    BUT03_Pin.hw_init();
    BUT04_Pin.hw_init();
    BUT05_Pin.hw_init();
    BUT06_Pin.hw_init();
    BUT07_Pin.hw_init();
#endif
#ifdef MCP23017_1
    mcp1.begin(0x21);
    LED10_Pin.hw_init();
    LED11_Pin.hw_init();
    LED12_Pin.hw_init();
    LED13_Pin.hw_init();
    LED14_Pin.hw_init();
    LED15_Pin.hw_init();
    LED16_Pin.hw_init();
    LED17_Pin.hw_init();
    BUT10_Pin.hw_init();
    BUT11_Pin.hw_init();
    BUT12_Pin.hw_init();
    BUT13_Pin.hw_init();
    BUT14_Pin.hw_init();
    BUT15_Pin.hw_init();
    BUT16_Pin.hw_init();
    BUT17_Pin.hw_init();
#endif
    stand.hw_init();
    // Start the OpenMRN stack
    openmrn.begin();
    openmrn.start_executor_thread();

#if defined(PRINT_PACKETS)
    // Dump all packets as they are sent/received.
    // Note: This should not be enabled in deployed nodes as it will
    // have performance impact.
    openmrn.stack()->print_all_packets();
#endif // PRINT_PACKETS

#if defined(USE_CAN)
    // Add the hardware CAN device as a bridge
    openmrn.add_can_port(
        new Esp32HardwareCan("esp32can", CAN_RX_PIN, CAN_TX_PIN));
#endif // USE_CAN
    stand.welcomeScreen();
    stand.SendIsTrainEventQuery();
    // Green for up and running...
    digitalWrite(STATUS_R,LOW);
    digitalWrite(STATUS_G,HIGH);
}
                
void loop() {
    // Call the OpenMRN executor, this needs to be done as often
    // as possible from the loop() method.
    openmrn.loop();
}    

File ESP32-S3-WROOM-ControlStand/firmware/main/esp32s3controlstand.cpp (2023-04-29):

// -!- C++ -!- //////////////////////////////////////////////////////////////
//
//  System        : 
//  Module        : 
//  Object Name   : $RCSfile$
//  Revision      : $Revision$
//  Date          : $Date$
//  Author        : $Author$
//  Created By    : Robert Heller
//  Created       : Mon Dec 12 13:38:08 2022
//  Last Modified : <230429.1355>
//
//  Description	
//
//  Notes
//
//  History
//	
/////////////////////////////////////////////////////////////////////////////
//
//    Copyright (C) 2022  Robert Heller D/B/A Deepwoods Software
//			51 Locke Hill Road
//			Wendell, MA 01379-9728
//
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
// 
//
//////////////////////////////////////////////////////////////////////////////

static const char rcsid[] = "@(#) : $Id$";

#include "sdkconfig.h"
#include "cdi.hxx"
#include "cdidata.hxx"
#include "DelayRebootHelper.hxx"
#include "EventBroadcastHelper.hxx"
#include "FactoryResetHelper.hxx"
#include "HealthMonitor.hxx"
#include "fs.hxx"
#include "hardware.hxx"
#include "NodeRebootHelper.hxx"

#include <algorithm>
#include <driver/i2c.h>
#include <driver/uart.h>
#include <esp_err.h>
#include <esp_log.h>
#include <esp_ota_ops.h>
#include <esp_system.h>
#include <esp_task_wdt.h>
#include <esp32s3/rom/rtc.h>
#include <freertos_includes.h>
#include <freertos_drivers/esp32/Esp32HardwareTwai.hxx>
#include <freertos_drivers/esp32/Esp32WiFiManager.hxx>
#include <freertos_drivers/esp32/Esp32BootloaderHal.hxx>
#include <freertos_drivers/esp32/Esp32SocInfo.hxx>
#include <openlcb/MemoryConfigClient.hxx>
#include <openlcb/RefreshLoop.hxx>
#include <openlcb/SimpleStack.hxx>
#include <openlcb/MultiConfiguredConsumer.hxx>
#include <openlcb/MultiConfiguredPC.hxx>
#include "MultiConfiguredProducer.hxx"
#include <utils/constants.hxx>
#include <utils/format_utils.hxx>
#include "freertos_drivers/esp32/Esp32HardwareI2C.hxx"
#include "MCP23017Gpio.hxx"
#include "Adafruit_TCA8418.hxx"
#include "NvsManager.hxx"
#include "BootPauseHelper.hxx"
#include "ESP32ControlStand.hxx"

///////////////////////////////////////////////////////////////////////////////
// Increase the CAN RX frame buffer size to reduce overruns when there is high
// traffic load (ie: large datagram transport).
///////////////////////////////////////////////////////////////////////////////
OVERRIDE_CONST(can_rx_buffer_size, 64);

esp32s3controlstand::ConfigDef cfg(0);
Esp32HardwareTwai twai(CONFIG_TWAI_RX_PIN, CONFIG_TWAI_TX_PIN);
Esp32HardwareI2C i2c("/dev/i2c");


namespace openlcb
{
    /// Name of CDI.xml to generate dynamically.
    const char CDI_FILENAME[] = "/fs/cdi.xml";

    // Path to where OpenMRN should persist general configuration data.
    const char *const CONFIG_FILENAME = "/fs/config";

    // The size of the memory space to export over the above device.
    const size_t CONFIG_FILE_SIZE =
        cfg.seg().size() + cfg.seg().offset();

    // Default to store the dynamic SNIP data is stored in the same persistant
    // data file as general configuration data.
    const char *const SNIP_DYNAMIC_FILENAME = "/fs/config";

    /// Defines the identification information for the node. The arguments are:
    ///
    /// - 4 (version info, always 4 by the standard
    /// - Manufacturer name
    /// - Model name
    /// - Hardware version
    /// - Software version
    ///
    /// This data will be used for all purposes of the identification:
    ///
    /// - the generated cdi.xml will include this data
    /// - the Simple Node Ident Info Protocol will return this data
    /// - the ACDI memory space will contain this data.
    const SimpleNodeStaticValues SNIP_STATIC_DATA =
    {
        4,
        SNIP_PROJECT_PAGE,
        SNIP_PROJECT_NAME,
        SNIP_HW_VERSION,
        SNIP_SW_VERSION
    };

} // namespace openlcb

extern "C"
{

void *node_reboot(void *arg)
{
    Singleton<esp32s3controlstand::NodeRebootHelper>::instance()->reboot();
    return nullptr;
}

void reboot()
{
    os_thread_create(nullptr, nullptr, uxTaskPriorityGet(NULL) + 1, 2048
                   , node_reboot, nullptr);
}

ssize_t os_get_free_heap()
{
    return heap_caps_get_free_size(MALLOC_CAP_8BIT);
}

/// Verifies that the bootloader has been requested.
///
/// @return true (always).
///
/// NOTE: On the ESP32 this defaults to always return true since this code will
/// not be invoked through normal node startup.
bool request_bootloader(void)
{
    LOG(VERBOSE, "[Bootloader] request_bootloader");
    // Default to allow bootloader to run since we are not entering the
    // bootloader loop unless requested by app_main.
    return true;
}



/// Updates the state of a status LED.
///
/// @param led is the LED to update.
/// @param value is the new state of the LED.
///
/// NOTE: Currently the following mapping is being used for the LEDs:
/// LED_ACTIVE -> Bootloader LED
/// LED_WRITING -> Bootloader Write LED
/// LED_REQUEST -> Used only as a hook for printing bootloader startup.
void bootloader_led(enum BootloaderLed led, bool value)
{
    LOG(VERBOSE, "[Bootloader] bootloader_led(%d, %d)", led, value);
    if (led == LED_ACTIVE)
    {
        ACT1_Pin::instance()->write(value);
    }
    else if (led == LED_WRITING)
    {
        ACT2_Pin::instance()->write(value);
    }
    else if (led == LED_REQUEST)
    {
        //LOG(INFO, "[Bootloader] Preparing to receive firmware");
        //LOG(INFO, "[Bootloader] Current partition: %s", current->label);
        //LOG(INFO, "[Bootloader] Target partition: %s", target->label);
    }
}

/// Initializes the node specific bootloader hardware (LEDs)
void bootloader_hw_set_to_safe(void)
{
    LOG(VERBOSE, "[Bootloader] bootloader_hw_set_to_safe");
    ACT1_Pin::hw_init();
    ACT2_Pin::hw_init();
}

namespace esp32s3controlstand {

ConfigUpdateListener::UpdateAction FactoryResetHelper::apply_configuration(
    int fd, bool initial_load, BarrierNotifiable *done)
{
    // nothing to do here as we do not load config
    AutoNotify n(done);
    LOG(VERBOSE, "[CFG] apply_configuration(%d, %d)", fd, initial_load);

    return ConfigUpdateListener::UpdateAction::UPDATED;
}

void FactoryResetHelper::factory_reset(int fd)
{
    LOG(VERBOSE, "[CFG] factory_reset(%d)", fd);
    // set the name of the node to the SNIP model name
    cfg.userinfo().name().write(fd, openlcb::SNIP_STATIC_DATA.model_name);
    cfg.userinfo().description().write(fd, "");
    
#if defined(CONFIG_IO_BUTTON_LED_BOARD_1)
    for(int i = 0; i < NUM_OUTPUTS; i++)
    {
        cfg.seg().mcp0().consumers().entry(i).description().write(fd, "");
    }
    for(int i = 0; i < NUM_INPUTS; i++)
    {
        cfg.seg().mcp0().producers().entry(i).description().write(fd, "");
        CDI_FACTORY_RESET(cfg.seg().mcp0().producers().entry(i).debounce);
    }
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

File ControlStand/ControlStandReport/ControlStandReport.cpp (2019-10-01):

//
//  System        : 
//  Module        : 
//  Object Name   : $RCSfile$
//  Revision      : $Revision$
//  Date          : $Date$
//  Author        : $Author$
//  Created By    : Robert Heller
//  Created       : Mon Jul 31 11:43:58 2017
//  Last Modified : <170802.0844>
//
//  Description	
//
//  Notes
//
//  History
//	
/////////////////////////////////////////////////////////////////////////////
//
//    Copyright (C) 2017  Robert Heller D/B/A Deepwoods Software
//			51 Locke Hill Road
//			Wendell, MA 01379-9728
//
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
// 
//
//////////////////////////////////////////////////////////////////////////////

static const char rcsid[] = "@(#) : $Id$";

#include <ControlStandReport.h>


_debouncedSwitchMomentary::_debouncedSwitchMomentary(int pin)
{
    switchPin = pin;
    lastSwitchState = HIGH;
    switchState = HIGH;
    lastDebounceTime = 0;
    debounceDelay = 200;
    pinMode(switchPin, INPUT_PULLUP);
}

bool _debouncedSwitchMomentary::On()
{
    switch (checkstate()) {
        case -1:
        case 0: return false;
        case 1: return true;
    }
    return false;
}

bool _debouncedSwitchMomentary::Off()
{
    switch (checkstate()) {
        case 1:
        case 0: return false;
        case -1: return true;
    }
    return false;
}

int _debouncedSwitchMomentary::checkstate()
{
    int result = 0;
    int reading = digitalRead(switchPin);
    if (reading != lastSwitchState) {
        lastDebounceTime = millis();
    }
    if ((((long) millis()) - lastDebounceTime) > debounceDelay) {
        if (reading != switchState) {
            switchState = reading;
            if (switchState == HIGH) {
                result = -1;
            } else {
                result = 1;
            }
        }
    }
    lastSwitchState = reading;
    return result;
}

_debouncedSwitchNonMomentary::_debouncedSwitchNonMomentary(int pin)
{
    switchPin = pin;
    lastSwitchState = HIGH;
    switchState = HIGH;
    lastDebounceTime = 0;
    debounceDelay = 200;
    pinMode(switchPin, INPUT_PULLUP);
}

bool _debouncedSwitchNonMomentary::On()
{
    checkstate();
    return (switchState != HIGH);
}

bool _debouncedSwitchNonMomentary::Off()
{
    checkstate();
    return (switchState == HIGH);
}

int _debouncedSwitchNonMomentary::checkstate()
{
    int result = 0;
    int reading = digitalRead(switchPin);
    if (reading != lastSwitchState) {
        lastDebounceTime = millis();
    }
    if ((((long) millis()) - lastDebounceTime) > debounceDelay) {
        if (reading != switchState) {
            switchState = reading;
            if (switchState == HIGH) {
                result = -1;
            } else {
                result = 1;
            }
        }
    }
    lastSwitchState = reading;
    return result;
}

const char *ControlStandReport::HelpText[] = {
    "Control Stand Report 0.0",
    "",
    "Commands:",
    "R", "  Read",
    "H", "  Print this help",
    "", NULL
};

ControlStandReport::ControlStandReport() {
    throttle = 0;
    autobrake = 0;
    indbrake = 0;
    reverser = 0;
    uselup = _debouncedSwitchMomentary(USELUP);
    useldown = _debouncedSwitchMomentary(USELDOWN);
    unitSelect = Off;
    horn = _debouncedSwitchNonMomentary(HORN);
    pinMode(USELD0,OUTPUT); digitalWrite(USELD0,LOW);
    pinMode(USELD1,OUTPUT); digitalWrite(USELD1,LOW);
    pinMode(USELD2,OUTPUT); digitalWrite(USELD2,LOW);
}

void ControlStandReport::ReadControls() {
    //char buffer[80];
    throttle = analogRead(THROTTLE);
    autobrake = analogRead(AUTOBRAKE);
    indbrake = analogRead(INDBRAKE);
    reverser = analogRead(REVERSER);
    //sprintf(buffer,"*** ControlStandReport::ReadControls(): throttle = %u",throttle);
    //Serial.println(buffer);
    //sprintf(buffer,"*** ControlStandReport::ReadControls(): autobrake = %u",autobrake);
    //Serial.println(buffer);
    //sprintf(buffer,"*** ControlStandReport::ReadControls(): indbrake = %u",indbrake);
    //Serial.println(buffer);
    //sprintf(buffer,"*** ControlStandReport::ReadControls(): reverser = %u",reverser);
    //Serial.println(buffer);
    if (uselup.On()) {
        switch (unitSelect) {
        case Brake: unitSelect = Off; break;
        case Off: unitSelect = U1; break;
        case U1: unitSelect = U2; break;
        case U2: unitSelect = U3; break;
        case U3: unitSelect = U4; break;
        case U4: unitSelect = U5; break;
        default: break;
        }
    }
    if (useldown.On()) {
        switch (unitSelect) {
        case Off: unitSelect = Brake; break;
        case U1: unitSelect = Off; break;
        case U2: unitSelect = U1; break;
        case U3: unitSelect = U2; break;
        case U4: unitSelect = U3; break;
        case U5: unitSelect = U4; break;    
        default: break;
        }
    }
    switch (unitSelect) {
    case Brake: digitalWrite(USELD0,LOW); digitalWrite(USELD1,HIGH); 
        digitalWrite(USELD2,HIGH); break;
    case Off: digitalWrite(USELD0,LOW); digitalWrite(USELD1,LOW); 
        digitalWrite(USELD2,LOW); break;
    case U1: digitalWrite(USELD0,HIGH); digitalWrite(USELD1,LOW);
        digitalWrite(USELD2,LOW); break;
    case U2:digitalWrite(USELD0,LOW); digitalWrite(USELD1,HIGH);
        digitalWrite(USELD2,LOW); break;
    case U3: digitalWrite(USELD0,HIGH); digitalWrite(USELD1,HIGH);
        digitalWrite(USELD2,LOW); break;
    case U4:digitalWrite(USELD0,LOW); digitalWrite(USELD1,LOW);
        digitalWrite(USELD2,HIGH); break;
    case U5: digitalWrite(USELD0,HIGH); digitalWrite(USELD1,LOW);
        digitalWrite(USELD2,HIGH); break;
    }
}
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

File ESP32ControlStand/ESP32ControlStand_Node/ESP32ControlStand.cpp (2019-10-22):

// -!- C++ -!- //////////////////////////////////////////////////////////////
//
//  System        : 
//  Module        : 
//  Object Name   : $RCSfile$
//  Revision      : $Revision$
//  Date          : $Date$
//  Author        : $Author$
//  Created By    : Robert Heller
//  Created       : Mon Oct 7 18:47:11 2019
//  Last Modified : <191022.1446>
//
//  Description	
//
//  Notes
//
//  History
//	
/////////////////////////////////////////////////////////////////////////////
//
//    Copyright (C) 2019  Robert Heller D/B/A Deepwoods Software
//			51 Locke Hill Road
//			Wendell, MA 01379-9728
//
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
// 
//
//////////////////////////////////////////////////////////////////////////////

static const char rcsid[] = "@(#) : $Id$";

#include <Arduino.h>
#include <SPI.h>
#include <Wire.h>
#include <Adafruit_GFX.h>
#include <Adafruit_SSD1306.h>
#include <Button.h>
#include <OpenMRNLite.h>
#include "openlcb/TractionThrottle.hxx"
#include "openlcb/RefreshLoop.hxx"
#include "openlcb/EventHandlerTemplates.hxx"
#include "openlcb/EventService.hxx"
#include "ESP32ControlStand.h"


bool ESP32ControlStand::checkThrottle()
{
    bool changedP = false;
    uint8_t newQuadrature;
    newQuadrature = digitalRead(THROTTLEA) | (digitalRead(THROTTLEB) << 1);
    uint8_t quadratureUp[] = {1, 3, 0, 2};
    uint8_t quadratureDown[] = {2, 0, 3, 1};
    if (newQuadrature != throttleQuadrature_)
    {
        changedP = true;
        if (newQuadrature == quadratureUp[throttleQuadrature_ & 0x03])
        {
            if (throttlePosition_ > 0)
                throttlePosition_--;
        }
        else if (newQuadrature == quadratureDown[throttleQuadrature_ & 0x03])
        {
            if (throttlePosition_ < 8)
                throttlePosition_++;
        }
        else
            throttlePosition_ = 0;
    }
    throttleQuadrature_ = newQuadrature & 0x03;
    return changedP;
}

bool ESP32ControlStand::readBrake() {
    uint16_t newBrake = analogRead(BRAKE);
    if (newBrake != brake_) {
        brake_ = newBrake;
        return (true);
    } else {
        return (false);
    }
}

bool ESP32ControlStand::readHorn() {
    uint16_t newHorn = analogRead(HORN);
    if (newHorn != horn_) {
        horn_ = newHorn;
        return (true);
    } else {
        return (false);
    }
}

bool ESP32ControlStand::readReverser() {
    uint16_t newReverser = analogRead(REVERSER);
    if (newReverser != reverser_) {
        reverser_ = newReverser;
        return (true);
    } else {
        return (false);
    }
}
void ESP32ControlStand::hw_init()
{
    // SSD1306_SWITCHCAPVCC = generate display voltage from 3.3V internally
    if(!display_.begin(SSD1306_SWITCHCAPVCC, 0x3C)) { // Address 0x3C for 128x32
        Serial.println(F("SSD1306 allocation failed"));
        // blink red
        digitalWrite(STATUS_G,LOW);
        for(;;) { // Don't proceed, loop forever
            digitalWrite(STATUS_R,LOW);
            delay(500);
            digitalWrite(STATUS_R,HIGH);
            delay(1000);
        }
    }
    pinMode(HORN,INPUT);
    pinMode(BRAKE,INPUT);
    a_.begin();
    b_.begin();
    c_.begin();
    d_.begin();
    bell_.begin();
    lightSwitch_.begin();
    pinMode(REVERSER,INPUT);
    pinMode(THROTTLEA,INPUT_PULLUP);
    pinMode(THROTTLEB,INPUT_PULLUP);
    throttleQuadrature_ = digitalRead(THROTTLEA) | (digitalRead(THROTTLEB) << 1);
}
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

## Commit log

2019-10-01 Initial Commit.
    [Arduino_As_Uno.kicad_pcb, Arduino_As_Uno.sch, ControlStandShield.kicad_pcb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]
2019-10-01 Start ESP32ControlStand.
    [ESP32ControlStand.sch]
2019-10-02 ESP32ControlStand Base I/O circuits.
    [ButtonLEDPanel.sch, ESP32ControlStand.sch]
2019-10-03 Completed first draft of PCBs for ESP32ControlStand.
    [ButtonLedPanel2.sch, CAN_Transceiver.sch, ESP32ControlStand.kicad_pcb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]
2019-10-03 Tweaks of PCBs for ESP32ControlStand.
    [ESP32ControlStand.kicad_pcb]
2019-10-04 Assorted updates to the PCB.
    [ESP32ControlStand.kicad_pcb, ESP32ControlStand.sch]
2019-10-05 Continue 3D model, spec out horn and brake pots, noturn hole for reverser.
    [ButtonLEDPanel.sch, ButtonLedPanel2.sch, CAN_Transceiver.sch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]
2019-10-06 3D Model nearly complete, DXF export.
    [2ndGenLocoControlStand.dxf, ESP32ControlStand.kicad_pcb]
2019-10-07 Fleshing out the ESP32ControlStand Node code.
2019-10-07 Generate PDF of schematic, PNG of board.
2019-10-07 Continue to fleshout the the throttle node.
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2019-10-11 Start a fritzing breadboard.
    [ESP32ControlStand.fzz]
2019-10-12 Update circuit to use "Default" SDA/SDL.
    [ButtonLEDPanel.sch, ButtonLedPanel2.sch, CAN_Transceiver.sch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]
2019-10-12 Continue to flesh out the firmware: add config options, remove unneeded release train function, remove redundant currentTrain_ variable.
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2019-10-12 Fix I/O conflict (Status_G).
    [ESP32ControlStand.kicad_pcb, ESP32ControlStand.sch]
2019-10-12 Complete phase1 (buttons and display) breadboard.
    [ESP32ControlStand.fzz]
2019-10-13 Continuing with the breadboard.
    [ESP32ControlStand.fzz]
2019-10-16 Set things up to use the status LED.
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2019-10-16 Complete fritzing breadboard.
    [ESP32ControlStand.fzz]
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2020-12-23 FreeCAD model of the box lid.
    [2ndGenLocoControlStand.fcstd]
2020-12-26 Continue FreeCAD work
    [2ndGenLocoControlStand.fcstd, ButtonLEDPanel.sch, ButtonLedPanel2.sch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]
2020-12-28 Horn lever in place.
    [2ndGenLocoControlStand.fcstd]
2022-02-06 Add I2C pullups.
    [ButtonLEDPanel.sch, ButtonLedPanel2.sch, CAN_Transceiver.sch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]
2022-07-25 Start on bare processor, smd version.
    [ButtonLedPanel1.sch, ButtonLedPanel2.sch, CANTransceiver.sch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]
2022-07-26 Nearly complete schematic. Added Antenna footprint.
    [ButtonLedPanel1.sch, ButtonLedPanel2.sch, CANTransceiver.sch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]
2022-07-27 Conversion to SMD continues...
    [ButtonLedPanel1.sch, ButtonLedPanel2.sch, CANTransceiver.sch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]
2022-07-28 Complete PS, work on parts spec.
    [ButtonLedPanel1.sch, ButtonLedPanel2.sch, CANTransceiver.sch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]
2022-07-28 Transfer edge cuts.
    [ESP32-D0WD-V3-ControlStand.kicad_pcb]
2022-07-29 Completed parts spec for ESP32-D0WD-V3-ControlStand.
    [ButtonLedPanel1.sch, ButtonLedPanel2.sch, CANTransceiver.sch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]
2022-07-31 Working on the PCB Layout.
    [ButtonLedPanel1.sch, ButtonLedPanel2.sch, CANTransceiver.sch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]
2022-07-31 Completed V0.0 PCB.
    [ButtonLedPanel1.sch, ButtonLedPanel2.sch, CANTransceiver.sch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]
2022-07-31 Started on V0.1 PCB.
    [ESP32-D0WD-V3-ControlStand-V0-0.kicad_pcb, ESP32-D0WD-V3-ControlStand.kicad_pcb, ProcessorSection.sch]
2022-08-01 About halfway done.
    [ButtonLedPanel1.sch, ButtonLedPanel2.sch, CANTransceiver.sch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]
2022-08-01 Nearly done. Just the button/LED boards to do.
    [ESP32-D0WD-V3-ControlStand.kicad_pcb]
2022-08-02 Completed V0-1 board (still need to add a few things -- logos and such and adjust silk).
    [ESP32-D0WD-V3-ControlStand.kicad_pcb, ESP32-D0WD-V3-ControlStand.sch, ProcessorSection.sch]
2022-08-02 Completed V0-1 board -- added logos, cleaned up silk, added connector labels, etc.
    [ESP32-D0WD-V3-ControlStand.kicad_pcb, ESP32-D0WD-V3-ControlStand.sch]
2022-08-02 Add measurments (for CAD work on a hand-held box/enclusure).
    [ESP32-D0WD-V3-ControlStand.kicad_pcb]
2022-08-03 Working on CAD: handheld box.
    [ESP32-D0WD-V3-ControlStand.kicad_pcb]
2022-08-06 Working on CAD models.
    [ESP32-D0WD-V3-ControlStand.kicad_pcb]
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2022-08-09 Working on control features CAD.
    [ESP32-D0WD-V3-ControlStand.kicad_pcb]
2022-12-09 Created ESP32-S3-WROOM-ControlStand.
    [ButtonLedPanel1.sch, ButtonLedPanel2.sch, CANTransceiver.sch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]
2022-12-10 Add Keypad board.
    [ButtonLedPanel1.sch, ButtonLedPanel2.sch, CANTransceiver.sch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]
2022-12-12 Start on OpenMRNIDF port of Control Stand (Throttle) firmware.
    [esp32s3controlstand-partitions.csv]
2022-12-16 Rename code directory.
    [esp32s3controlstand-partitions.csv]
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2022-12-21 Add additional dims.
    [ESP32-S3-WROOM-ControlStand.kicad_pcb]
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2022-12-22 Add brake lever, update STL code for levers.
2022-12-26 Completed basic Control Stand (throttle) code. TODO: Keypad processing.
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2023-02-09 Add ESP32-T7S3-ControlStand.
    [ButtonLedPanel1.sch, ButtonLedPanel2.sch, CANTransceiver.sch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]
2023-04-30 Update: remove USB connector from main board and update for current Adafruit OLED.
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2024-02-19 update ESP32-T7S3-ControlStand: Kicad 6, fix SDA, clean up and finalize PCB.
    [ESP32-T7S3-ControlStand.kicad_pcb, ESP32-T7S3-ControlStand.kicad_sch]
2024-04-08 Snapshot April 8, 2024.
    [ButtonLedPanel1.kicad_sch, ButtonLedPanel2.kicad_sch, CANTransceiver.kicad_sch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]
2024-04-08 3D models mostly done.
    [APHB1608CGKSURKC.stp, B3U-1100P-B.stp, ESP32-S3-WROOM-1-N4.stp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]
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2024-04-25 Finalize part numbers for BOM.
    [ESP32-S3-WROOM-ControlStand.kicad_sch, KeypadPanel.kicad_sch, PowerSupply.kicad_sch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]

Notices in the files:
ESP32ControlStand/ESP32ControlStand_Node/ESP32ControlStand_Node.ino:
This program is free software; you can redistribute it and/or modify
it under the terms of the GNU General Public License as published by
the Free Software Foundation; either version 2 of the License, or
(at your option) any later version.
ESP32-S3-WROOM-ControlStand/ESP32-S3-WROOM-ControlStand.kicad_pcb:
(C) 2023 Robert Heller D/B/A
